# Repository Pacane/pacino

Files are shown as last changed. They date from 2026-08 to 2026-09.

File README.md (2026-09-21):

# Pacino

A hand-wired wireless split keyboard you print, screw together and solder — no main PCB.
Parametric OpenSCAD case + switch plate, with a build pipeline that produces **real STEP solids**
(via FreeCAD) so everything is editable in Fusion 360 as B-rep geometry, not as a mesh.
If you would rather not hand-wire it, the same design has a **slim build**: an 11.5 mm case around a
reversible PCB that is generated from this model and ready to order — [see below](#the-slim-build-a-real-pcb-115-mm).

Named after (and descended from) the [cheapino](https://github.com/tompi/cheapino), whose column
stagger and thumb-cluster geometry it borrows; hardware-wise it runs a nice!nano-compatible
nRF52840, Kailh hot-swap sockets on Amoeba-King single-key PCBs, and ZMK.

file-23d378c498248af3c7d3fe0cd5108f69

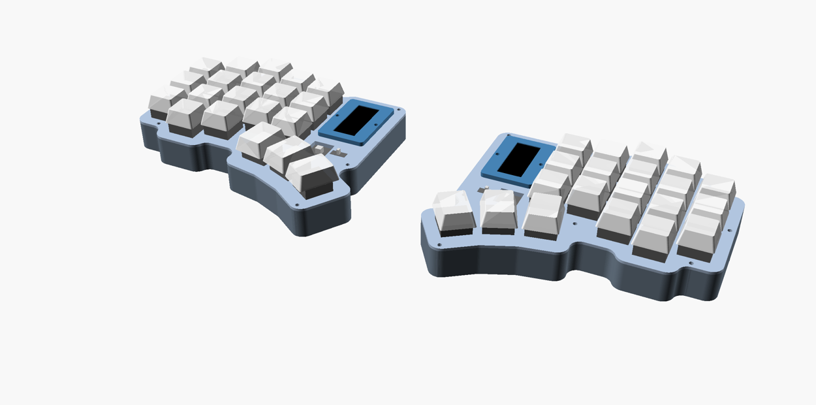
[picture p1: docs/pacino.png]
Pacino — 5 columns + 2 extra keys, nice!view version


*20 keys per half (40 total): 5 columns + 2 extra keys, with the nice!view display. 145 × 120 mm.*

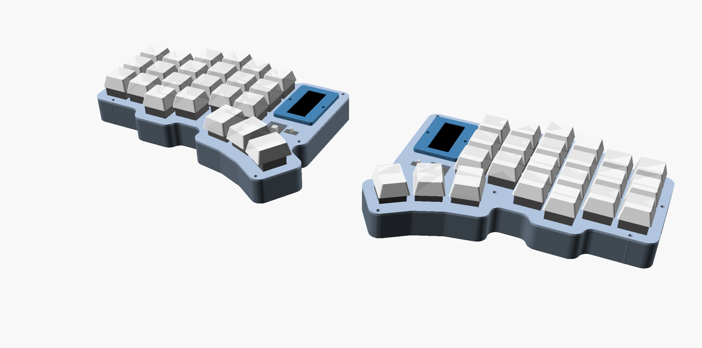
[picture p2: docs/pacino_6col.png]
Pacino — 6 columns + 2 extra keys, nice!view version


*23 keys per half (46 total): the optional 6th outer column, same display. 164 × 120 mm.*

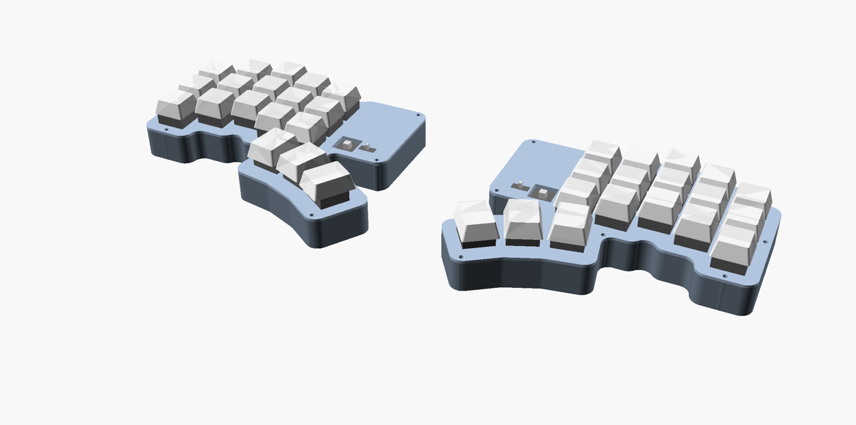
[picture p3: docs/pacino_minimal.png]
Pacino — 5 columns, no extras, no display


*The minimal build — 18 keys per half (36 total), no extra keys, no display. 145 × 120 mm.*

All three are the same scale. The display costs no width: stacked over the nano, a build with it is
exactly as wide as one without. Renders of every other combination are
[at the bottom](#variant-gallery).

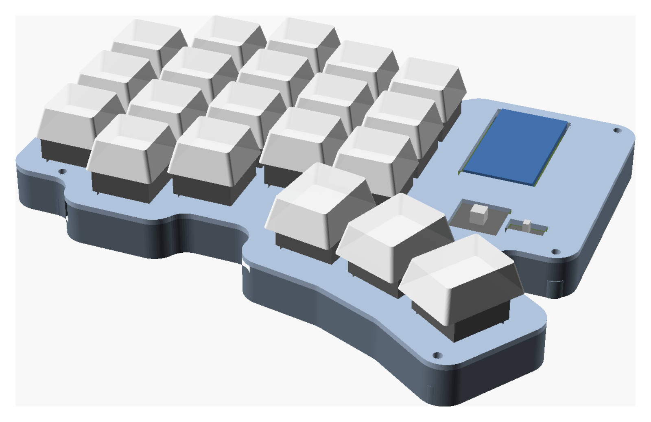
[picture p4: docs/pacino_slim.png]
Pacino — the slim PCB build


*The slim build: the same 40 keys over a reversible PCB, **11.5 mm** to the plate top instead of 17.5,
and flat — the cell lies in a well under the board. The controller sits flush in the plate window.*

**The default design:** a cheapino-style 3×5 (+2) + 3-thumb column-stagger layout on a clean
19.05 mm **MX** grid with **1.25u thumbs**, an **electronics bay** beside the inner column that
holds a **LiPo** (sunk into a well in the case floor — a 902030 by default), a **nice!nano**
(**flipped component-side down** in a cradle that is part of the plate, fully enclosed, USB out
through a notch in the wall) and a **reset button and power slide switch** in pockets in the
plate, laid out for **hand-wiring**. A **nice!view** mount (flush in the plate *directly over* the
nano, clamped by a screw-down bezel, so it costs no extra width) is in the model but off by default:
mounting bosses live in the walls, not in the matrix, and there is ~3 mm under the switch pins.
A PCB-sandwich build is a switch away.

```
keyboard.scad            the model — all parameters at the top, Customizer-friendly (parts: case, plate, section; bezel with nice_view)
layouts/cheapino.scad    generated from ../cheapino/pcb/cheapino.kicad_pcb  (exact positions, if you want them)
layouts/badtemper.scad   generated from ../badtemper2/BadTemper.kicad_pcb
tools/kicad_layout.py    KiCad .kicad_pcb -> layouts/*.scad  (switches, holes, MCU, Edge.Cuts polygon)
tools/pcb_gen.py         the slim build's PCBs: model -> pcb/*/ boards + footprint libs + gerbers
pcb/flat/  pcb/pod/     those two KiCad projects (generated, DRC-clean; each has its own README,
                         gerber zip and renders).  part = "pcb_test" prints a stand-in to fit first
tools/csg2step.py        OpenSCAD .csg -> STEP, runs inside FreeCAD
tools/svg_polygon.py     helper: bakes the cavity outline to a polygon for the FreeCAD pass
build.sh                 builds everything into out/
out/                     STEP / 3MF / STL / DXF / PNG — regenerate any time, never hand-edit
CHANGELOG.md             what changed since you printed — and whether you need to reprint, re-order or reflash
```

## Pick a ready-made variant

[`variants/`](variants/) holds every combination of the four options — 5 or 6 columns, with or
without the two extra keys, 902030 or 103450 battery, with or without nice!view — each as
`case_*` / `plate_*` STEP + 3MF for both halves (plus a bezel for display versions) and previews.
The index in [`variants/README.md`](variants/README.md) lists sizes; `./build_variants.sh`
regenerates them all.

## Quick start

```sh
./build.sh            # everything: step, mesh, dxf, png  (~40 s)
./build.sh step       # just the STEP files
SCAD_ARGS='-D battery=[34,50,10.5]' ./build.sh    # any parameter override, e.g. the 2000 mAh cell
```

Or open `keyboard.scad` in OpenSCAD and use the Customizer (`Window ▸ Customizer`).
`part` selects what is shown/exported (`assembly`, `section`, `case`, `plate`, the 2D profiles),
`side` picks `left` / `right` / `both`, `explode` lifts the plate.

Outputs per side: `case_*` and `plate_*` as `.step` (Fusion) and `.3mf` / `.stl` (slicer),
`*_2d_*.dxf` profiles for sketches, and `preview_*.png` (assembly, exploded, top, case, plate,
both halves, section through the bay). `WITH_DISPLAY=1 ./build.sh` additionally builds the
nice!view version (`case_display_*`, `plate_display_*`, `bezel_*`); in the Customizer that is the
`nice_view` switch.

## The layout

`grid_stagger = [0, 10, 16.4, 10, 7.5]` is the cheapino's column stagger (its PCB is already
19.0 mm MX pitch) snapped to 19.05. The thumb cluster starts where the cheapino's does
(`71.5, -15.5`) but uses **1.25u caps standing portrait** — long side pointing up at the columns —
fanned −10° / −22° / −34° around the thumb (key rotation = 90° + fan) at a 21.8 mm pitch along
the arc: `[[71.5,-15.5,80,1.25], [92.5,-21.5,68,1.25], [111.7,-31.7,56,1.25]]`. That gives
~1.5 mm between caps at their lower ends (they diverge towards the top, as a radial fan does) and
1.7 mm to the bottom row. Edit `grid_thumbs` to shift or re-fan the cluster; keep the rotation
as 90 + fan so the caps stay portrait.

**Extra keys.** `grid_extra_keys = [[1, -1], [2, -1]]` adds a short fourth row under the ring and
middle columns (under X/C on the left half, ,/. on the right) — 38 keys per pair. `[]` removes them;
any `[column, row]` pair on the grid works.

**Sixth column.** `grid_outer_col = true` adds a column outside the pinky (Corne-style 3×6), with
its own `grid_outer_stagger` (0 = same as the pinky). The left-edge bosses and bumpons follow it; the
half grows to 164 mm wide. Build it alongside the default with
`SUFFIX=_6col SCAD_ARGS='-D grid_outer_col=true' ./build.sh`.

**Hand-wiring.** Eight 6 mm bosses sit 0.5 mm inside the inner wall line so they merge into the
wall and the whole matrix area is free for diodes and wires (each boss was checked for ≥ 2 mm to
every switch body, ≥ 1 mm to the battery, and clear of the MCU cradle and the keycap footprints
so the screw heads are reachable). Under the plate there are 10 mm: MX body + pins take 8.3 from
the plate top, leaving ~3 mm under the pins. The bay has ~8 mm of floor to the right of the battery and 4 mm below it for routing,
and its open fence end faces the nice!nano.

Set `layout = "cheapino"` or `"badtemper"` to use the exact positions extracted from those
boards instead (`cavity_from = "pcb"` then follows that board's Edge.Cuts).

## The electronics bay

```
bay_left / bay_top_y = 86.5 / 61   the bay hangs from its top edge (USB at the top); size is automatic
battery_type = "902030"            the cell (902030 / 103450 / 604060 / custom), bottom-left of the bay, in a 3 mm fence
mcu_size   = [18, 33]              nice!nano at the top of the bay over the battery (measured on a SuperMini clone)
nv_pcb     = [14, 36, 1.6]         nice!view, right of the nano, header end down
ctrl_bay_h = 13                    reset + power strip hung below the bay, switches at its right end
```

Stack at the bay with the 902030 (z from the case underside): floor 0–2.5, with the battery well
sunk to 1.2 · battery 1.2–10.7 · 2.8 clearance for the nano's components, which now face down ·
nice!nano PCB 13.5–15.05 · 0.95 air · plate 16–17.5. The 1.3 mm the well recovers pays for the
component clearance the flip costs, so overall height is unchanged. The model warns if the board's
components would hit the battery or the board would hit the plate. `part = "section"` renders the stack as a 2D cut.

`battery_type` picks the cell and sizes the bay and the cavity depth (`cavity_depth = 0` = automatic,
battery thickness + 4): `902030` (20 × 30 × 9, 500 mAh — weeks per charge; 13.5 mm cavity),
`103450` (34 × 50 × 10, 2000 mAh; 45 × 60 bay, 14.5 mm cavity, +1 mm case height and +3 mm width — the bay reaches past the thumb cluster), `604060` (40 × 60 × 6; 10.5 mm cavity),
or `custom` with `battery_custom`. Build the 2000 mAh version alongside the default with
`SUFFIX=_2000mah SCAD_ARGS='-D battery_type="103450"' ./build.sh` → `case_2000mah_*`, `plate_2000mah_*`.
The controller charges at 100 mA by default, which is ~20 h for the 2000 mAh cell: before you fit it, bridge the
**boost** solder jumper on the back of the board (two pads by the battery pads; 500 mA on a nice!nano v2, 300 mA
on the SuperMini clones — only with a cell over 500 mAh, so not for the 902030 or 303040).

### How the nano and the battery are held

**Battery:** it drops into a **well sunk 1.3 mm into the case floor** (`battery_well_floor`), whose
walls locate it on all four sides; with the plate on, the nano 2.8 mm above it keeps it in the well. Set `battery_well_floor = 0`
instead and it sits on the floor inside a 3 mm printed fence (`battery_fence`, open at the lead end),
which costs 1.3 mm of case height — the well is the default because the flipped nano needs the room.

**nice!nano / nRF52840 clone:** it goes in **upside down** (`mcu_flipped`, the default) — components
and USB connector facing *into* the case, bare PCB back facing the plate. That protects everything on
the board, and because the wires now poke straight down through the pads into the bay, the cradle no
longer needs wire channels along the sides: the plate above it is **solid**, with no opening over the
MCU at all.

It sits in a cradle that is part of the plate: rails on both long sides, open at the USB end,
holding the board four ways —

- **sideways:** five half-round **crush ribs** per rail (`crush_rib`, 0.6 mm proud, centred on the
  pocket wall so nothing bulges outward), narrowing the 18.6 mm slot to **17.4 mm** at the ribs. An
  18.0 mm board goes in with real resistance and shaves them to a custom fit; boards up to ~18.6 mm
  crush them further. Turn `crush_rib` down for a lighter fit, up for a tighter one.
- **from below, far end:** two corner tabs under the outer 0.5 mm of the far edge, with a 10 mm gap
  between them so a SuperMini-style clone's centred reset button stays clear.
- **from below, USB end:** two posts rising from the **case floor** (`mcu_end_post`), which engage
  once the plate is screwed down.
- **from above:** a 6 mm-wide roof pad on the plate over the bare back of the board, leaving it
  0.2 mm of lift.

**To fit it: with the plate off the case, slide the board into the cradle from the open USB end
until it meets the far rail.** To remove it, push it back out through the **4 mm eject hole** in the
far rail. **Set `mcu_size` to your board's real width × length.** Before printing, check your board's
component side is clear where the cradle touches it: the far corners (outer 0.5 mm, either side of
the reset button) and the two USB-end corners.

**Wiring the nano:** solder the wires on what is now the underside — they drop straight into the bay,
no channels or routing needed. The battery leads come up out of the well right below the board.

Setting `mcu_flipped = false` restores the old component-side-up cradle: an opening through the
plate, wire channels along both long edges, and a USB slot that crosses the plate line.

### Reset button and power switch

Plain through-hole parts, both dropped into the plate from above: a **12 × 12 mm tactile switch**
with a tall plunger (reset → nano `RST` + `GND`) and an **SS12D00 slide switch** (power, in series
with the battery `+` to the nano's `B+`). Each pocket is a hole through the plate the size of the
body (+0.2 mm) with a 1.2 mm floor hanging below, with a 3.5 mm square opening around each leg
(`ctrl_leg_hole`) so the legs hang in free air below the floor and a wire can be wrapped and
soldered to them from underneath. The
tactile's body sits 2.3 mm below the plate top so ~1 mm of its 3.3 mm plunger is proud — enough to
press, hard to hit by accident; the slide's 3 mm actuator stands up for your thumbnail. Solder
wires to the legs from below. Nothing can push the parts in (they sit on the floor) and the legs
plus wires keep them from lifting; if you want belt-and-braces, a dab of glue or a 0.1 mm tighter
`ctrl_clearance` does it. `reset_body` / `power_body` / `*_legs` take the dimensions of whatever
switches you actually buy.

They sit in a **control bay** strip hung below the electronics bay (`ctrl_bay_h = 0` sizes it for
the larger switch), placed as high as the battery allows — the pockets reach up into the bay's
battery-free margin — so they stay clear of the thumb keys in both battery layouts, off the battery
(legs and wires hang free below), and add nothing to the bay's width. (The strip spans the full bay width on purpose: a narrower one leaves a pocket
between bay, column 4 and thumb key 2 that the outline smoothing turns into a hole.)

### nice!view

The nice!view has no mounting holes — on a PCB it hangs off its 5-pin header — so here it is
**clamped**. It sits vertically (header end down, the way a Corne shows it) in a pocket through the
plate, resting on two 1 mm ledges under its long edges that hang from a ring below the plate. The PCB
top ends up `nv_preload` (0.15 mm) above the plate top; the printed **bezel** (`part = "bezel"`,
2.5 mm, window sized to the glass) is screwed down onto two 5 mm bosses hanging under the plate with
M2 screws — `nv_boss_hole_d = 1.7` for self-tapping into PETG (works well; 3 mm of engagement), or
3.2 for heat-set inserts — so it clamps the PCB, not the plate. The 12.6 mm opening under the
display leaves the solder pads free. Nothing can come loose without removing two screws, and
nothing relies on a friction or snap fit.

**It sits directly on top of the nano** (`nv_stacked`, the default). That only works because the
board is flipped: the plate above it is solid, so the display can take that surface. The bay then
stays as narrow as the no-display version — the display costs **0 mm of width** instead of 11.6.

Three things follow from stacking, and the model enforces all of them:

- The bezel's screw bosses move from the display's **ends to its sides** — an end boss hangs 3 mm
  below the plate and would pass straight through the board. On the sides they clear the board by
  0.8 mm and the cradle pocket by 0.5 mm, landing in free bay space 2.3 mm above the battery.
- The support ledges are thinned (`nv_ledge_te`, 1.2 → 0.6 mm) so they clear the board's back by
  0.4 mm — and they then double as the board's hold-down, replacing the cradle roof pad that the
  display's opening cuts through.
- The display's wiring end overhangs past the board, so its five wires drop straight into the bay
  and run to the nano's pads, which now face into the bay.

The cost is servicing: getting the nano out means removing the bezel and lifting the display first.
Set `nv_stacked = false` for the old side-by-side bay (11.6 mm wider); it is also the automatic
behaviour if `mcu_flipped` is off, since an unflipped nano needs that plate area for its own opening.

### Bumpons

Eight 10.6 mm × 1 mm recesses in the underside for 10 mm self-adhesive rubber feet (`bumpon_d`,
`bumpon_clearance`, `bumpon_depth`; `bumpon_positions` for the four under the key block and thumb
cluster, two on the left edge follow the outer column, and two are placed on the bay: 8 mm in from
its top-right corner, and 12 mm up from the bottom of the control strip on the right). The floor is
2.5 mm so 1.5 mm remains under each recess.

The two bay feet and the **battery well** compete for the same floor: the well is already 1.3 mm
into it, so a recess over the well would leave 0.2 mm. With a well the cell therefore sits against
the bay's *left* wall (which doubles as the well's side) instead of 5 mm from it, keeping the bay's
right-hand corners clear, and the bay is sized so the top-right foot always fits beside the cell with
a millimetre of wall outside its recess. Each bay foot then moves outward only by what its well
forces — a couple of millimetres — and the model warns if one has nowhere to go. The wider cells pay
for it in width: the 103450's bay is 45 mm instead of 44, and its case 148 mm. A 56 mm MagSafe magnet ring (the
self-adhesive kind) goes under the index column (`magsafe_d`, `magsafe_pos`; 0 = none). It is **printed in**
(`magsafe_style = "embedded"`, the default): an annular pocket exactly as tall as the ring (`magsafe_ring_id`,
`magsafe_ring_t`; measure your ring — a 56 mm sticker ring is about 45 mm inside and 0.5–0.7 mm thick), open to the
underside through a window one layer up, so the first layer is a ledge overlapping the ring's edges by 0.8 mm
(`magsafe_lip_w`) and the steel shows through between them, 0.2 mm below the surface. Add a pause in the slicer
**before layer 5** (the model prints the height: after the layer ending at z = 0.8 mm), drop the ring in with its
exposed face **down** and the adhesive up, press it flat, and resume. Layer 5 is then laid straight onto the ring,
like a first layer on a sticky bed, with the nozzle a full layer above the steel. If supports are on, put a
support blocker over the ring: the pocket reaches the plate through the window and would otherwise be filled.
It uses 0.8 mm of the 2.5 mm floor, so it works in the slim build too, and the ring cannot come off. Being
steel, the ring has no polarity to get wrong.

Why the window: the hold improves with every tenth of a millimetre less between the ring and the mount. A
0.4 mm skin over the ring (`magsafe_skin = 0.4`) is the clean look and holds decently; a one-layer skin held
better but tears along its lines with the ring's edge behind it; the ledge is backed by the pocket wall and holds.
Don't leave air over the ring either (`magsafe_pocket_air` only pads a ring thinner than a layer multiple; keep
ledge or skin + ring + air on a layer boundary, the model notes if it isn't): the ceiling would have to bridge it,
and since a layer's lines all run one way, the ones running along the ring span 30 mm chords and sag. The bigger
lever is the ring itself: the usual sticker ring is 0.65 mm of steel, and a *magnet* ring (1.2–2 mm, 16 segments)
holds a mount in a different league — the pocket takes it the same way, but it has a right way up: hold it
against the mount first and put the face it pulls in with down.

The two stick-on alternatives: `"groove"` leaves the underside flat with a one-layer locating groove 0.3 mm
outside the ring's edge, and the ring's adhesive sticks straight to the bed-side first layer (it holds there, as on
any PETG print). `"recess"` sinks the ring 1 mm into the floor (`magsafe_depth`), but that pocket prints on
support and the adhesive does *not* hold on a support-interface surface — sand the pocket and glue the ring in.
The recess has to stay clear of the battery well, since the two cut the floor from opposite sides and would leave
0.2 mm where they overlap (the model warns). `out/preview_bottom.png` shows them all.

### How the plate attaches

The plate is the lid. The case walls end flush with the plate's underside, so the plate rests on
them all round; a 1 mm lip under the plate drops inside the walls (0.2 mm clearance) and locates it.
Eight 6 mm bosses rise from the floor to the plate underside (six around the key block, two on
the bay's right-hand corners, all half-buried in the wall so they don't intrude on the wiring), each with a
3.3 mm × 5 mm hole, with a 4.2 mm × 0.6 mm counterbore at its mouth (`boss_relief_d` / `boss_relief_h`), for an **M2 × 4 × 3.5 brass heat-set insert** — press it down until it bottoms in the counterbore, so it and the plastic it displaces sit below the boss face and the plate seats without trimming (`boss_hole_d = 1.7` if you'd
rather self-tap). **M2 × 6 screws** go down through the plate into them — the heads sit on top of
the plate, like a tray-mount case (ultra-thin hex-socket heads are ideal).

Hardware per half: 8 × M2×4×3.5 inserts, 8 × M2×6 screws, 8 × 10 mm bumpons
(+ 2 × M2×4 self-tapping screws for the bezel if you build the display version).
`variants/insert_test.3mf` (`part = "insert_test"`) is a two-minute test print — one boss as on the
case and a scrap of plate with its screw hole — to try the insert and screw before printing a case.

**M3 instead:** `screw_size = "M3"` resizes everything at once — 4.0 mm insert holes for the common
4.2 mm OD M3 inserts with a 5 mm counterbore, 3.4 mm clearance holes in the plate, and in the slim build a
6 mm spacer boss, a 4.6 mm wall channel, a 3.6 mm wall and 3.4 mm board holes. Hardware is then
8 × M3 inserts (4 mm long here, 3 mm in the slim build) and 8 × M3×6 (M3×10 slim) screws; an M3 socket
head is 5.5 mm across, so use low-profile ones. The 6 mm bosses keep 1 mm of wall around the insert —
fine for the five buried in the wall, set the three free-standing ones carefully. The bezel stays M2.

### Hot-swap with single-key PCBs

Per-key hot-swap PCBs (amoeba style) work as-is: the Kailh socket and the diode go on the underside
of each little board, the bare top face sits against the switch body, and the board hangs on the
switch — the socket grips the pins (as in any hot-swap board) and 5-pin switches' pegs locate it.
Row/column wires join the boards' `ROW`/`COL` pads underneath, below the ribs.

The classic failure with hanging boards — a switch being inserted pushes the board down instead of
into the socket — is handled by **pillars rising from the case floor** under each board's four
corners (`key_pcb_post = [2.5, 3.2]`, `key_pcb_post_gap = 0.2`). They sit inside the corner notches,
on the bare 1.3 × 2 mm patches the amoeba-king keeps clear of pads and components (its side pad rows
end 5.6 mm off-centre; the pillars start at 6.3), and stop 0.2 mm below the boards, so with the case
closed a board cannot move and a new switch's pins are forced into the socket. To swap a switch,
just pull and push with the case closed; the board stays put.

**Wiring around the pillars.** The pillars hug the *top and bottom* edges of each board (the row
boundaries), 3.5 mm long at ±7 mm from centre, so the column boundaries are completely free and the
centre 10 mm of every row boundary is free too. The amoeba-king's ROW pads are on its left/right
edges and its COL pads at the centre of its top/bottom edges: row wires go straight across the
column boundary pad-to-pad, column wires run down the board centre line between the pillar pairs —
neither comes near a pillar. The only rule: never lay a wire along a board's top/bottom edge into a
corner, because a wire on a pillar patch gets clamped in the 0.2 mm gap when the case closes.
[`docs/wiring_guide.png`](docs/wiring_guide.png) shows the underside: the inner wall and its bosses,
the boards with their pads, the pillars, the matrix, and the nice!nano with every pin named. The
matrix pins are read straight from the shield (`row-gpios` in `pacino.dtsi`, `col-gpios` in
`pacino_left.overlay`), and each row and column chain gets its own thin wire to its pin, routed
clear of pillars, bosses and wall (`tools/wiring_guide.py` regenerates it and checks every wire;
each variant directory gets its own). Orient the boards with the ROW pads towards the neighbouring
columns (the pillars are sized around that). The row wires leave the inner column straight into the
bay; the column wires collect at the thumbs' COL pads (the bottom key's, for a column without a
thumb), enter the bay beside the inner column's bottom corner and climb the far side of the nano.

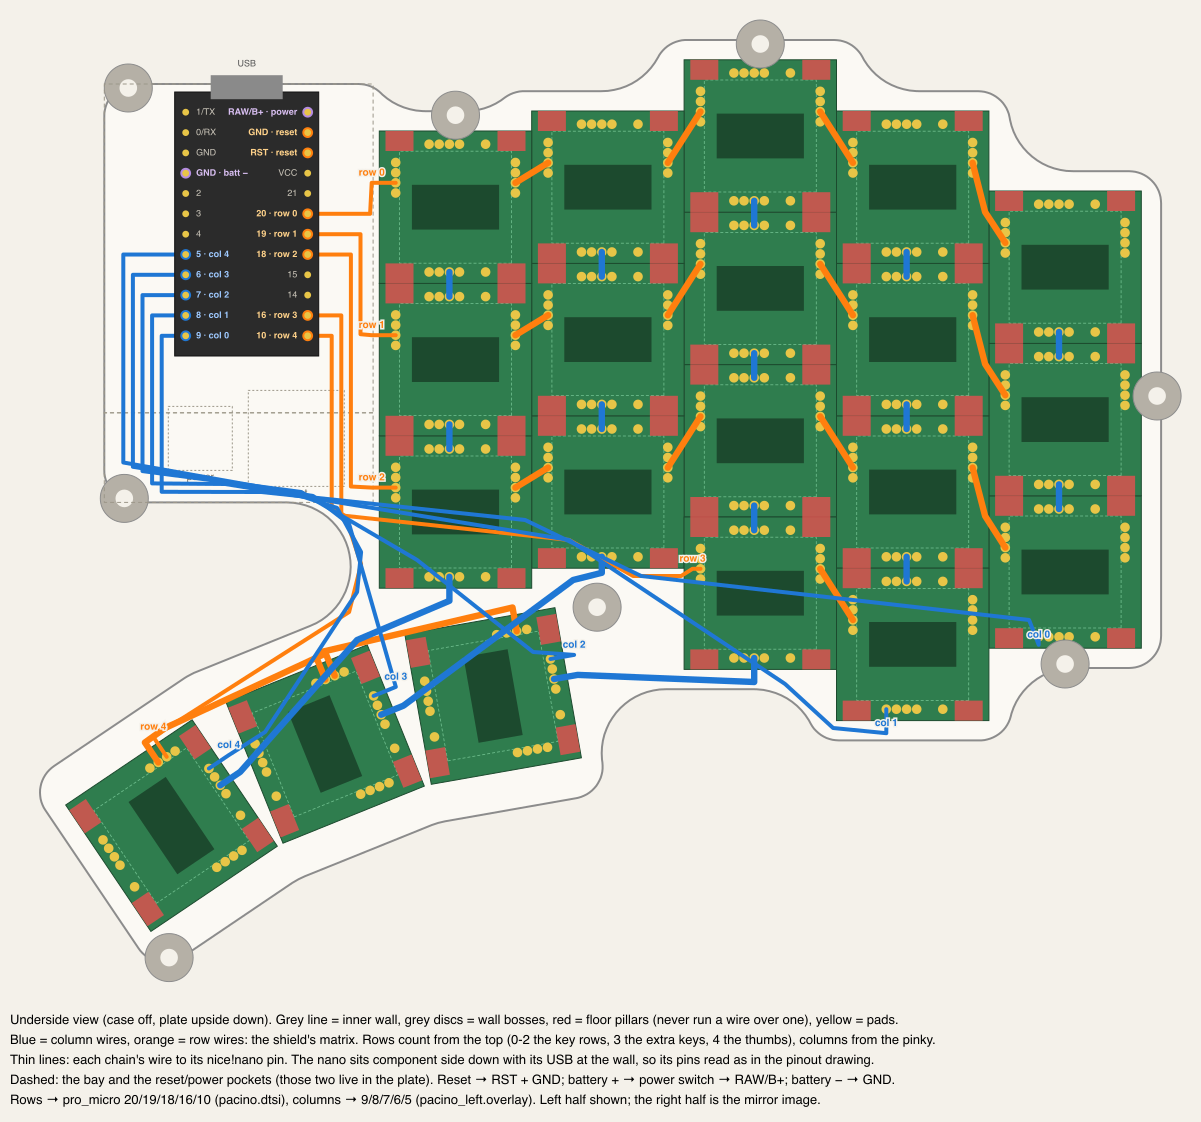
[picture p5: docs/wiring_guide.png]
wiring guide

`key_pcbs = true` (default) also stops the ribs 0.3 mm above the boards' top face, since the boards
are wider than the rib cells; set it to false for plain hand-wiring (no boards, no pillars). All of
this is a hand-wired idea — `build = "pcb"` ignores it, and takes its rib depth from the main board.

### Plate stiffness

A flat 1.5 mm PETG plate flexes under typing, and infill/walls can't fix that (it is already
practically solid). The plate therefore carries an **egg-crate of ribs** on its underside:
a 1.5 mm wall around every switch, 3.2–3.5 mm tall (down to the switch-body bottom, or 0.3 mm above
per-key PCBs, or the main board on the slim build), 0.3 mm outside the switch's clip zone, merging
into a grid (`plate_ribs`, `rib_w`, `rib_h`). That is roughly 5× the bending stiffness of the flat plate
at no change in case height — the ribs sit beside the switch bodies, above the pins, so wiring and
diodes (which live below the pins) are unaffected. The ribs are kept clear of the bosses and the
lip. Print the plate in 100 % infill anyway; a PLA plate with a PETG case is also a fine
combination (PLA is ~70 % stiffer than PETG).

### Printing (PETG)

- **Case:** prints as-is, bosses up, with a **pause before layer 5** to drop the MagSafe ring into its pocket
  (see [Bumpons](#bumpons)). If you print with supports on (say, for the bumpon recesses), use `case_*.bambu.3mf`
  instead: the same case as a Bambu Studio / Orca project with a support blocker already over the ring pocket
  (`tools/bambu_3mf.py` makes it from the plain 3MF) — otherwise the slicer fills the pocket through its window.
  Nothing overhangs except the open-top USB slot (bridged by the
  plate, so it can stay open) and the 1 mm bumpon recesses on the first layer.
- **Plate:** print top-side down. The cradle, the switch pockets (and the display ring and bezel
  bosses, if enabled) then point up and need no support; the keycap side gets the smooth first
  layer. The cradle's crush ribs run the full rail height, so they print as part of the rail
  perimeter. The only overhangs are the cradle's far corner tabs, the roof pad over the board and
  the pocket floors (tiny, fine in PETG).
- **Bezel** (if used): window side down.
- PETG tolerances: pockets have 0.2–0.3 mm clearance, the plate lip 0.2 mm; if your printer runs
  tight, bump `mcu_clearance` / `ctrl_clearance` to 0.4 and `lip_clearance` to 0.3. The MCU cradle
  is deliberately an interference fit — tune `crush_rib` (0.6) rather than the clearances. Self-tapping M2
  into 1.7 mm holes is a good fit for PETG; heat-set inserts also work in the 5 mm bosses.

### What sets the size

Per half (case outline), against the Bad Temper:

| | width × height |
|---|---|
| Bad Temper (choc, printed case) | 122 × 94 |
| badtemper2 MX PCB + 2 mm case | 131 × 107 |
| this (default, no display) | **145.0 × 120.2** (17.5 mm to the plate top) |
| this, with nice!view | 145.0 × 120.2 (the display stacks over the nano) |
| this, slim PCB build | 145.0 × 120.2 (**11.5 mm** to the plate top, flat; or the same with a pod for a 902030) |

Without the display the bay (nano + 902030) is narrower than the thumb cluster, so the **thumb
cluster** sets the right edge (130.5) and the bottom (−51): the cheapino position plus the portrait
1.25u fan is +12 mm lower and ~+12 mm further out than the Bad Temper's 1u thumbs. The display no
longer changes that: stacked over the nano it needs no extra bay width, so both versions are the
same size. (Side by side — `nv_stacked = false` — the nano + nice!view row is 41.2 mm and pushes
the right edge to 142.1: **+11.6 mm**.) Margins (`key_margin` 3,
`wall` 2.4) account for ~2.5 mm per side. A Bad Temper-sized half therefore needs a tighter thumb
cluster, not a different battery.

## Getting it into Fusion 360

1. **STEP (recommended).** `File ▸ Open` / `Insert ▸ Insert Derive` on `out/case_left.step`.
   One solid, true planar faces, real cylindrical holes. Edit with `Press Pull`, fillets,
   `Move Face`, or sketch on a face and cut/extrude; everything after import is in the timeline.
   Volumes are cross-checked against OpenSCAD's mesh on every build (printed by `build.sh`;
   they agree to <0.01 %).
   Note the case outline is a polygon (8 segments per 90° of rounding) because OCC's 2D
   offsetting cannot reproduce OpenSCAD's outline smoothing — see `build.sh`. Holes and bosses
   are exact cylinders.
2. **DXF profiles → fully parametric rebuild.** `Insert ▸ Insert DXF` on the XY plane:
   `cavity_2d`, `case_outline_2d`, `plate_2d`. Extrude the outline to the wall height, cut the
   cavity from `floor_t` up, add bosses at the hole centres. Slower, but you own every dimension.
3. **Mesh fallback.** `Insert ▸ Insert Mesh` with the `.3mf`, then `Mesh ▸ Convert Mesh`
   (Prismatic).

## Build modes and hardware

- `build = "plate"` (default, hand-wired): switches clip into the 1.5 mm plate, 6 mm bosses run
  from the floor to the plate underside with 3.3 mm holes for M2×4×3.5 heat-set inserts
  (`boss_hole_d = 1.7` for self-tappers); M2×6 screws through the plate (`screw_size = "M3"` for
  M3 inserts and screws throughout). `cavity_depth = 10`
  leaves room for MX bodies + pins + wiring and the battery/cradle stack.
- `build = "pcb"`: PCB sandwich, and the slimmest build at **11.5 mm**. Bosses stop at the PCB
  underside, the plate gets spacer bosses down to the PCB, MX plate-to-PCB spacing is automatic
  (5.0 mm MX / 2.2 mm Choc), the MCU sits on sockets on the PCB, the plate gets a window instead of
  the cradle, and the cell either lies flat under the board or rides in a pod on the plate over the
  controller. The boards are in [`pcb/`](pcb/) — see
  [The slim build](#the-slim-build-a-real-pcb-115-mm).
- `switch_type = "choc"` swaps pitch (18 × 17), cutout (13.8), plate thickness (1.3) and heights.
- Wall cutouts: `usb_cutout = [w, h, z-offset-from-board-top]`; `extra_cutouts` for a power
  switch etc. `[x, y, outward_angle, w, h, z]`.

## Using a different PCB or layout

```sh
python3 tools/kicad_layout.py path/to/board.kicad_pcb --prefix mykbd > layouts/mykbd.scad
```

It picks up `SW*`/`K*`/`MX*` switch footprints (position, rotation), mounting holes with
1.9–3.6 mm drills, `U1` as the MCU, and chains `Edge.Cuts` into one polygon. Add an `include`
and a `layout` option in `keyboard.scad` the way `cheapino`/`badtemper` are wired in.

## The slim build: a real PCB, 11.5 mm

`build = "pcb"` turns the same design into a **PCB sandwich**, and the boards exist: [`pcb/`](pcb/)
holds two complete, DRC-clean KiCad 9 projects with gerbers, generated from this model by
[`tools/pcb_gen.py`](tools/pcb_gen.py).

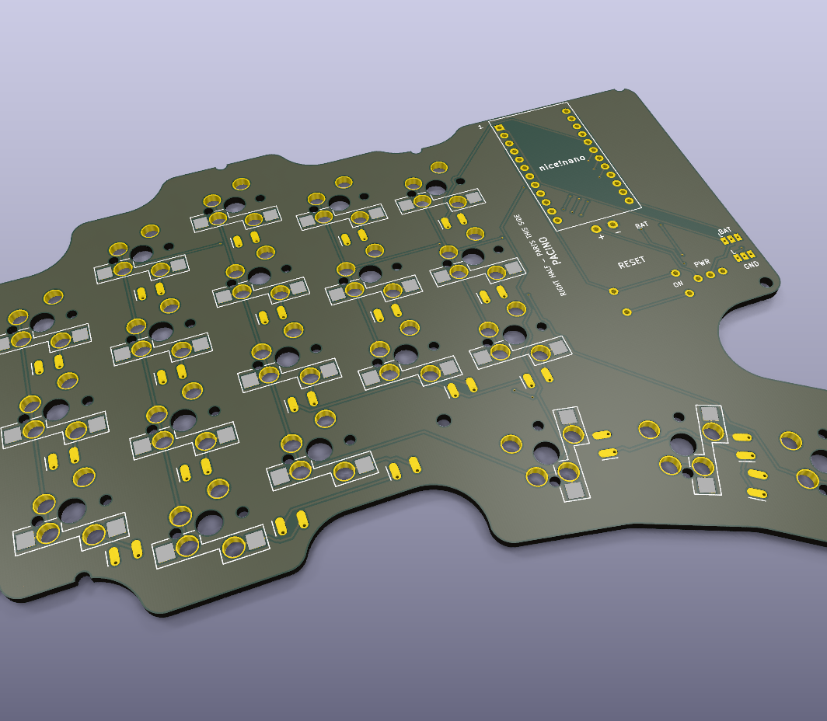
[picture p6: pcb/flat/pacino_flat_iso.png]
the Pacino PCB


<p>
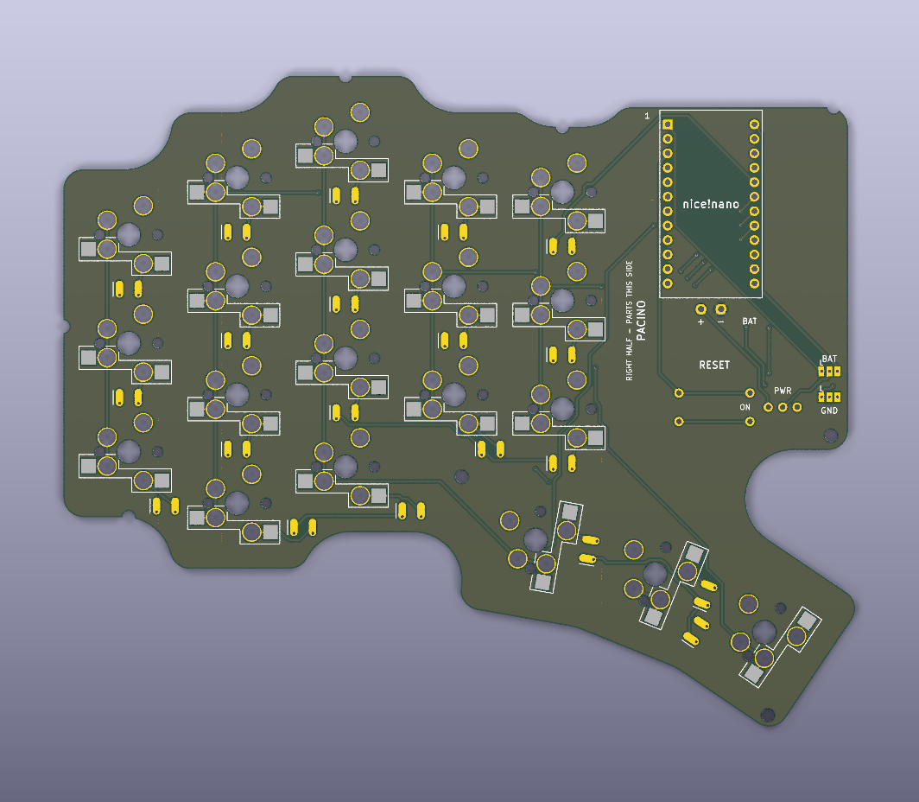
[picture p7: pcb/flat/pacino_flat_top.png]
front

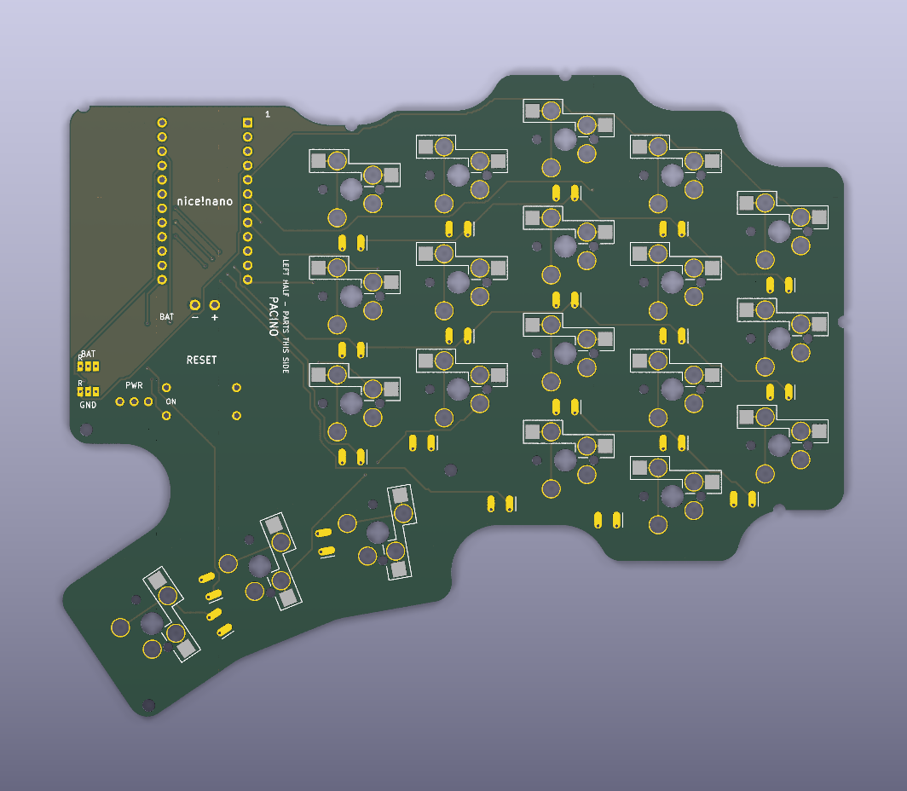
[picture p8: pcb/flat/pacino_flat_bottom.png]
back

</p>

*The same board from both sides. Flip it over and the bay swaps sides — that is the right half. Each
face's silkscreen names the half you build on it, and outlines its hot-swap sockets the way round
they go in on that half. These renders come out of `tools/pcb_gen.py` with the board, so they are
always the board in the repo rather than a picture of an older one.*

**11.5 mm to the plate top** — the floor for any MX build, and 6 mm thinner than hand-wired. The
stack is 2.5 floor + 2.4 (hot-swap sockets) + 1.6 board + 5.0 (MX plate-to-PCB, fixed by the
switch), and there is nothing left to remove.

Hardware for the slim build: the bosses stop at the board, so they are only 4.9 mm tall and their insert
holes 4 mm deep with 0.9 mm of floor under them, the same 0.6 mm counterbore at the mouth — use **M2 × 3 × 3.5 heat-set inserts** (the hand-wired case
takes 4 mm ones) and **M2 × 10 screws** (1.5 plate + 3.5 spacer + 1.6 board + 3 mm of thread). Five of the
eight bosses sit on the wall line like the hand-wired ones, and since the wall keeps rising 5 mm past their
tops, their insert holes would be tucked 1.2 mm under it — so a 4 mm channel (`pcb_screw_channel`) runs up
the inside of the wall over each hole, the insert and screw drop straight in, and the slim case's wall is
3 mm (`pcb_wall`) to keep 1.5 mm behind the channel (`screw_size = "M3"`: 4.6 mm channel, 3.6 mm wall, 3.4 mm
board holes, 6 mm spacer bosses — see [How the plate attaches](#how-the-plate-attaches)). The other three (thumb end, the bay's bottom corner, and
the one by the thumb keys) stand 2.5–3 mm clear of the wall as full round bosses; the board gets three real
mounting holes there and five edge notches at the wall-line ones. Two 3 mm floor pillars (`pcb_posts`)
stand under the board between the bosses, in the column gaps clear of the sockets, switch pins and diodes,
so a 55 mm span of board is not hanging on its corners; the model warns if one is moved onto a socket, and
the board generator keeps diodes off them.

Going to M3 with a board that was made for M2 (2.2 mm holes): the screws only have to pass *through* the board,
so drill its three real holes and file its five edge notches out to 3.4 mm rather than ordering a new one. Seven
of the eight have no copper within 3.15 mm of the hole centre (only the ground pour, which any drill over 2.7 mm
exposes on the hole wall — harmless, the screw lands in a brass insert in plastic). The top-edge hole between the
middle and ring columns, at (76.2, 57.1), is the exception: the column-0 bus runs 1.45 mm from its centre on the
back, so a 3.2 mm drill would cut it. Leave that one M2 with `m2_holes = [[76.2, 57.1]]` (its insert hole,
counterbore, plate hole and board notch stay M2-sized) or leave it unscrewed — the plate rests on the wall all
round. A board generated with `screw_size = "M3"` (`tools/pcb_gen.py -D 'screw_size="M3"'`) has 3.4 mm holes
from the start.

What sets it is where the cell goes, because **below the board every millimetre of battery is a
millimetre of case**. Above it, the 3.5 mm the MX geometry hands you is free — the socketed
controller already lives there, finishing flush with the plate top, and costs no height at all.
There are two ways to spend that, and both are built:

### Flat — a 303040 under the board (the default)

the slim build, flat

There is 3.4 mm of unused space under the board in the bay: 1.3 mm of floor well plus the 2.4 mm the
hot-swap sockets need — and the bay has no switches, so nothing is using it. A cell that fits inside
it needs no pod and no cutout in the board. A **303040** (3 × 30 × 40, ~320 mAh) lies in a well in the
floor, the plate stays flat, and the controller sits flush in its window.
Parts: [`variants/5col_extra2_bat303040_pcb_flat/`](variants/5col_extra2_bat303040_pcb_flat/),
board: [`pcb/flat/`](pcb/flat/).

3.4 mm is a cliff, not a slope. A thicker cell has to poke up through the board, and in the bay that
cutout runs straight under the controller and leaves its pin rows with no board to solder to — the
model warns if you ask for it.

### Pod — the 902030 over the controller

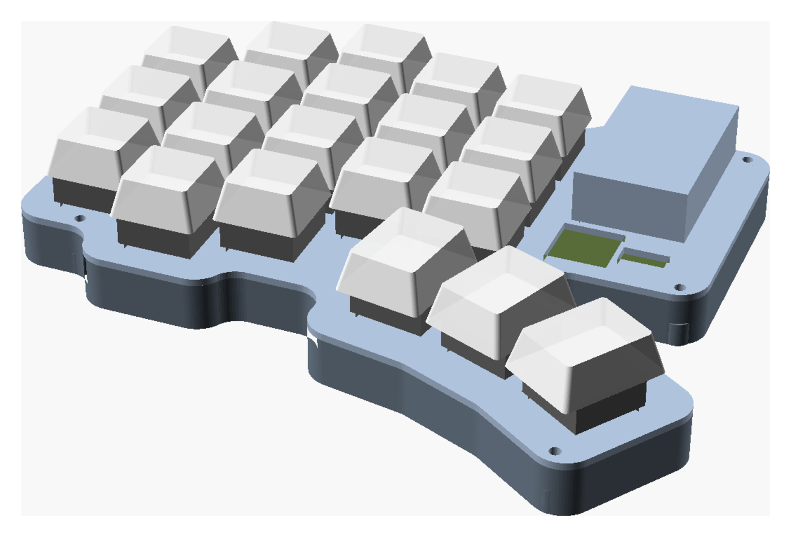
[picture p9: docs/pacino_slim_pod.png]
the slim build, pod


If you want the full 500 mAh, the 902030 rides in a **pod moulded into the plate, directly over the
controller** (`battery_pod = true`): in through the MCU window from below, resting on the controller,
leads down into the bay. Same 11.5 mm case, same outline — the pod stands 11.1 mm proud of the plate,
under the keycaps, which reach 14.5.
Parts: [`variants/5col_extra2_bat902030_pcb_pod/`](variants/5col_extra2_bat902030_pcb_pod/),
board: [`pcb/pod/`](pcb/pod/).

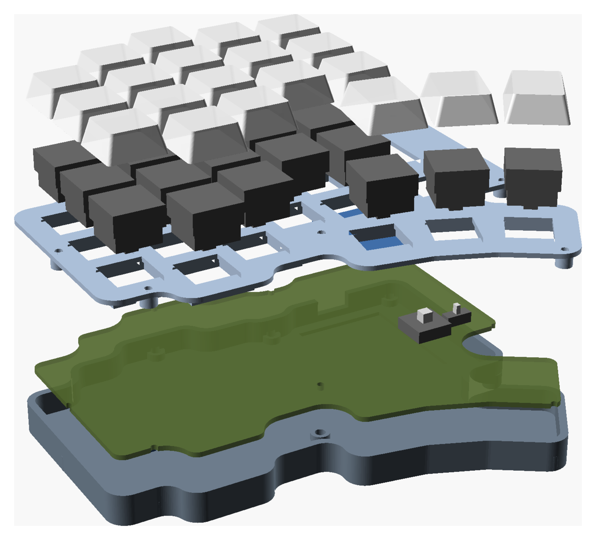
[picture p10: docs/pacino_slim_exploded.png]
the slim build, exploded


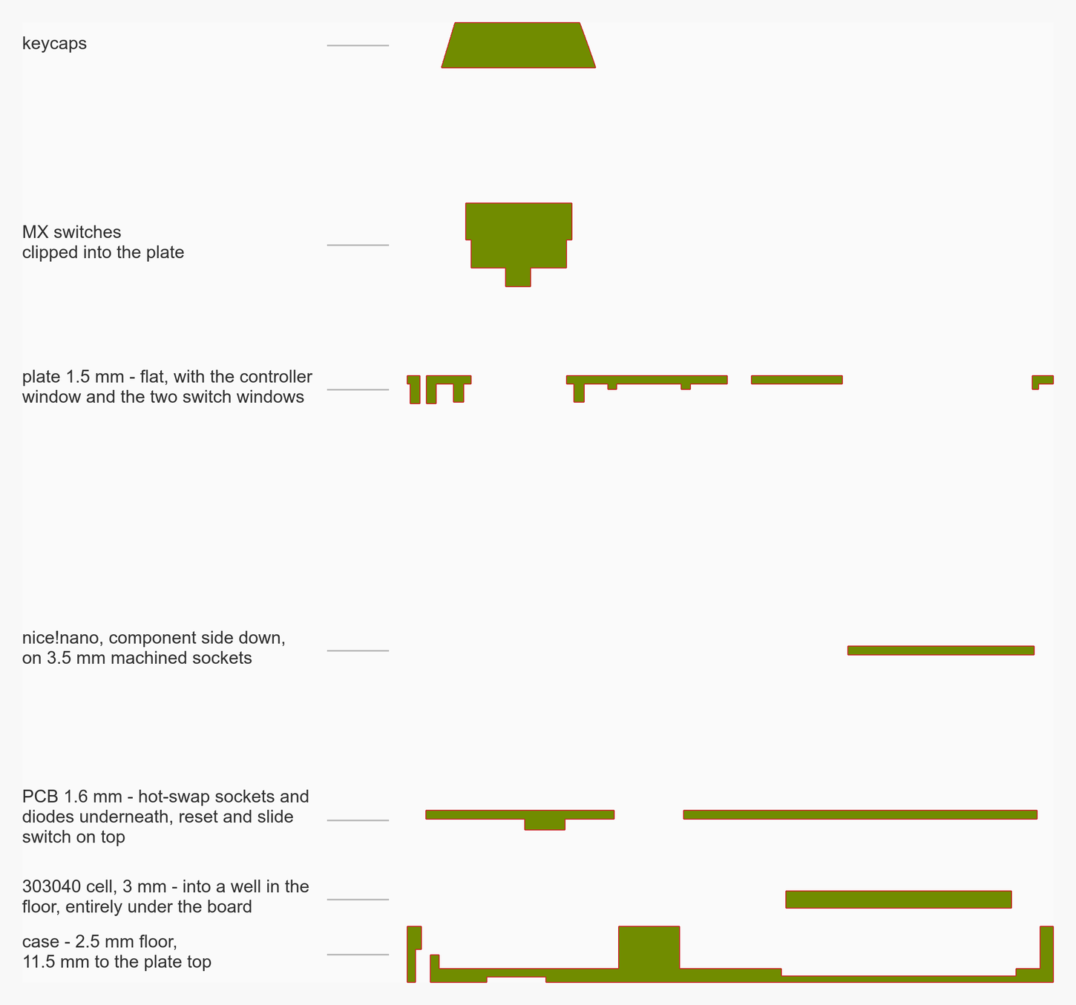
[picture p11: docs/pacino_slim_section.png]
the slim build in section, exploded and labelled


*Every part and where it sits, in the order you assemble it. `part = "section"` cuts the stack at
`section_x` (here 111, through a thumb key and the bay at once); `explode` separates the layers —
case, cell, board, controller, plate, switches, keycaps — each by its own step, so `explode = 0` is
exactly the assembled model.*

### Test-fitting it before you order a board

`part = "pcb_test"` prints a stand-in for the PCB: the real outline and mounting notches at 1.6 mm
thick, every hole a switch's pins, pegs and centre post pass through, the controller's two socket
rows, and the reset and slide switch legs — plus bumps on the underside at the hot-swap socket's real
1.85 mm, so the 2.4 mm under the board is a real test and not an assumption. Both slim variants ship
one as `pcb_test.3mf`; it is reversible the same way the board is, so flip it over for the other half.

```sh
SCAD_ARGS='-D build="pcb"' ./build.sh          # the case and plate
openscad -D 'part="pcb_test"' -D 'build="pcb"' -o pcb_test.3mf keyboard.scad
```

Print it flat, bumps up, then turn it over into the case. It checks the outline against the walls
and bosses, that every switch's pins land in a hole, the plate-to-board spacing, where the controller
and the two switches sit, the cell's room, and the 11.5 mm — everything except the copper. What it
cannot tell you: a printed 1.6 mm sheet is floppier than FR-4, so don't judge flex by it.

### The board

20 keys, 39 nets, ~515 tracks, ~16 vias, two layers, 0.3 mm tracks / 0.2 mm clearance / 0.3 mm
smallest drill — the cheapest process any fab offers. Hot-swap sockets, SOD-123 diodes (a
through-hole 1N4148 fits the same land), the controller on 3.5 mm machined low-profile sockets under the
plate window, reset and slide switch poking up through theirs. The controller gets **bare machined pins**
(Mill-Max 3320 or diode legs) — not a pin header with a plastic body: the board has to sit directly on the
sockets, 3.5 mm + its own thickness putting its back flush with the plate top and its USB receptacle inside
the socket gap. A 2.5–3 mm header body between board and sockets lifts the whole controller by that much and
pushes the USB receptacle up into the plate at the wall. The window around the controller runs right up to the
wall line at the USB end (the receptacle overhangs the board there) and the plate's rim is cut away across the
whole window at that end (the wall's notch below stays 12 mm), so the port is open from above rather than hidden
under a bridge and no stub of rim sits over the board's corners (`usb_plate_slot`); the window has 2 mm of clearance on the other sides;
`part = "clash"` renders whatever the plate hits — it should be empty. The silkscreen outlines every
hot-swap socket on both faces, so each one goes where its outline is — and because the outlines on
the two faces are the 180° rotation of each other, the way the right half differs is visible on the
board rather than only in the instructions.

The two builds are **two boards**, not one board with an option: moving the cell moves the bay, two
of the mounting holes and the reset/power positions. They are otherwise identical — same matrix,
same footprints, same firmware; only the bay end of the outline and the parts in it differ.

Both are **reversible**: one design, flipped over for the right half. Three things pay for that, and
each board's `README.md` has the detail —

- **Switches** carry *both* MX pin diagonals and a socket land on each face; on the right half they
  go in rotated 180°, which an MX switch does not care about. (Mirroring the pin pair instead — the
  obvious way — puts two 3 mm holes 2.84 mm apart and they merge into a slot.)
- **The matrix** lands on different GPIOs per half, because flipping swaps the controller's two pin
  rows. The ten holes were chosen so both of each hole's pins are usable GPIOs, keeping
  `pro_micro 1/14/15/16` free on both halves. Hence a separate `pacino_pcb` ZMK shield. (ZMK's
  stock nice!view adapter wants pins 1/2/3 — D1 plus the OLED header's SDA/SCL — and the PCB uses
  2 and 3 for the matrix, so a display on the PCB needs its own `nice_view_spi` on the free
  14/15/16.)
- **The controller** sits on top of the board — the face opposite the sockets — component side
  down, flush in the plate window; the pin lists and the **L**/**R** marks are worked out for that.
- **Power** gets two three-pad solder jumpers (bridge to **L** or **R**). Reset needs none: it sits
  across a pin pair that is GND/RST one way up and RST/GND the other.

```sh
tools/pcb_gen.py                 # both boards, footprint libraries and gerbers
tools/pcb_gen.py --variant=flat  # just one
```

Everything on them comes from `keyboard.scad` — outline, switch positions, mounting holes, controller
and switch placement — so changing the model and re-running moves the boards with it. There is no
schematic file: the generator declares every net and every connection, and names them the way the ZMK
shield does. Each project ships a `*_gerbers.zip` ready to upload; order ten and you have five
keyboards' worth of both halves.

If you would rather draw your own board, the bootstrap files are still there:
[`docs/pcb/pacino_edge_cuts.dxf`](docs/pcb/pacino_edge_cuts.dxf) (the outline for `Edge.Cuts`) and
[`docs/pcb/pacino_placement.csv`](docs/pcb/pacino_placement.csv) (every position in KiCad
coordinates), both from `tools/kicad_placement.py`. `tools/kicad_layout.py` reads a finished
`.kicad_pcb` back so the case can follow the real board.

## Variant gallery

Every option combination, with previews, sizes and download links:
**[variants/README.md](variants/README.md)** — each directory also carries an exploded-style
`preview_assembly.png`, a `preview_top.png` and its own `wiring_guide.png`.

## Firmware (ZMK)

This repo doubles as the ZMK config — no separate zmk-config repo needed. `config/` holds the
`pacino` shield (matrix, transform, default keymap) and `build.yaml` the build matrix; pushing a
change to either makes **GitHub Actions build the firmware** (Actions tab → latest run →
artifacts → `.uf2` files for left, right and `settings_reset`). SuperMini nRF52840 clones flash
as `nice_nano_v2`: double-tap reset, drag the `.uf2` on.

The slim PCB build has its own shield, **`pacino_pcb`** (same layout, same matrix, same keymap):
the reversible board puts the matrix on a different set of GPIOs on each half, so it cannot share
`pacino_left` / `pacino_right`. Both shields are in the build matrix; take the `pacino_pcb_*`
artifacts if you built the board. The pin lists are in
[`pcb/README.md`](pcb/README.md) and `tools/pcb_gen.py` prints them.

Electrical matrix ([`docs/wiring_guide.png`](docs/wiring_guide.png) draws it pin by pin) — 5 columns × 5 rows
per half, diodes `col2row` (Amoeba-King: switch → diode → ROW pad):

| matrix | wires to | nice!nano pin |
|---|---|---|
| row 0 / 1 / 2 | top / home / bottom key row | `pro_micro` 20 / 19 / 18 |
| row 3 | the two extra keys | `pro_micro` 16 |
| row 4 | the three thumbs | `pro_micro` 10 |
| col 0…4 | pinky → inner column (each column chain includes its extra key and thumb) | `pro_micro` 9 / 8 / 7 / 6 / 5 |

Pins 1, 2 and 3 are left free: that is where ZMK's stock `nice_view_adapter` puts the nice!view
(CS on D1, MOSI and SCK on the OLED header's SDA/SCL, plus VCC and GND), so the display variant is
this same wiring plus `nice_view_adapter nice_view` after the shield in `build.yaml` — no rewiring,
and nothing to add to `config/pacino.conf` (the nice_view shield enables the display itself). Pins
14/15/16 are the AVR pro micro's SPI pins; the nRF52840 puts SPI anywhere. Edit your keymap in
`config/pacino.keymap`. The left half is the central
side. The shield covers the default 5-column + 2-extra layout; the 6-column or no-extra variants
need a matching edit to the transform and one more column pin.

## Requirements

- OpenSCAD 2025.03+ (Manifold backend) — `/Applications/OpenSCAD.app`
- FreeCAD 1.0+ for STEP — `/Applications/FreeCAD.app` (only for `build.sh step`)
- Python 3 for the tools
- KiCad 9 for the PCB — `tools/pcb_gen.py` runs itself under KiCad's bundled Python (`pcbnew`)
  and uses `kicad-cli` for the gerbers

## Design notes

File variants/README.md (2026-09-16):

# Variants

Every combination of the four options. Each directory has `case_{left,right}` and `plate_{left,right}`
as **.step** (Fusion 360 / CAD) and **.3mf** (slicer) -- the case also as `case_*.bambu.3mf`, a Bambu Studio / Orca
project with a support blocker over the MagSafe ring pocket, for printing with supports on -- plus a bezel for the display versions, previews, and a
`wiring_guide.png` showing the underside with the wall, the floor pillars, the matrix and every wire to its nice!nano pin, all clash-free.
Print the plate top-side down, the case as-is with a pause before layer 5 to drop the MagSafe ring into its pocket; hardware and assembly notes are in the main README.

| variant | columns | keys/half | battery | nice!view | half size (mm) | preview |
|---|---|---|---|---|---|---|
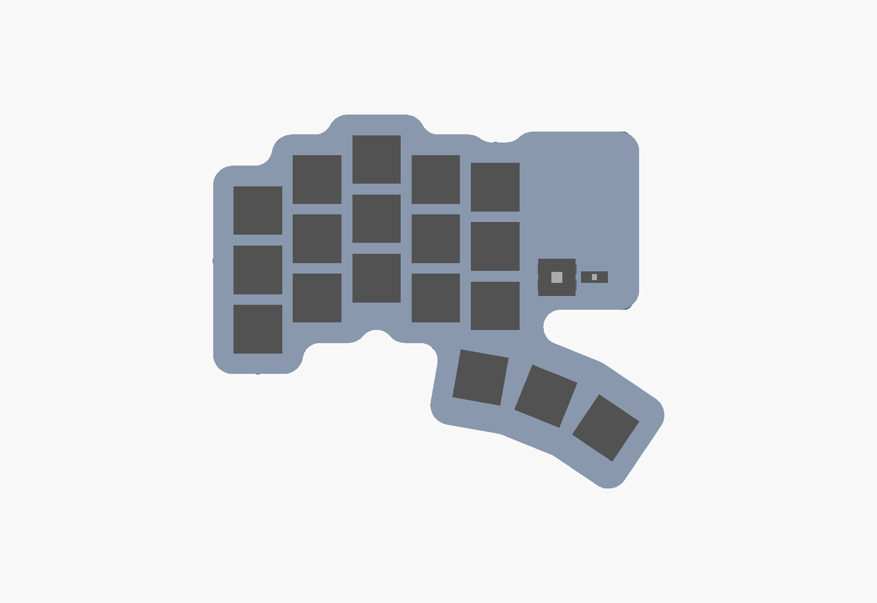
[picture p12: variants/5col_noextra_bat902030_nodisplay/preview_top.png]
| [`5col_noextra_bat902030_nodisplay`](5col_noextra_bat902030_nodisplay/) | 5 | 18 | 902030 | no | 145 × 120 |  |
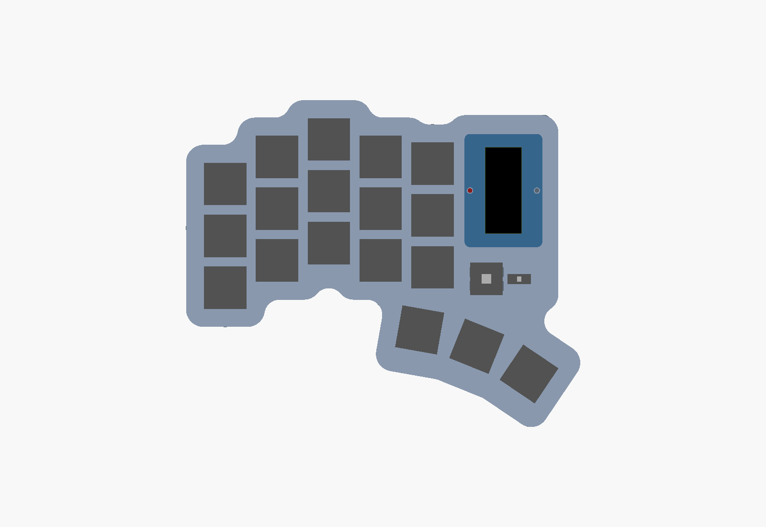
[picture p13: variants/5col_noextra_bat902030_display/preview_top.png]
| [`5col_noextra_bat902030_display`](5col_noextra_bat902030_display/) | 5 | 18 | 902030 | yes | 145 × 120 |  |
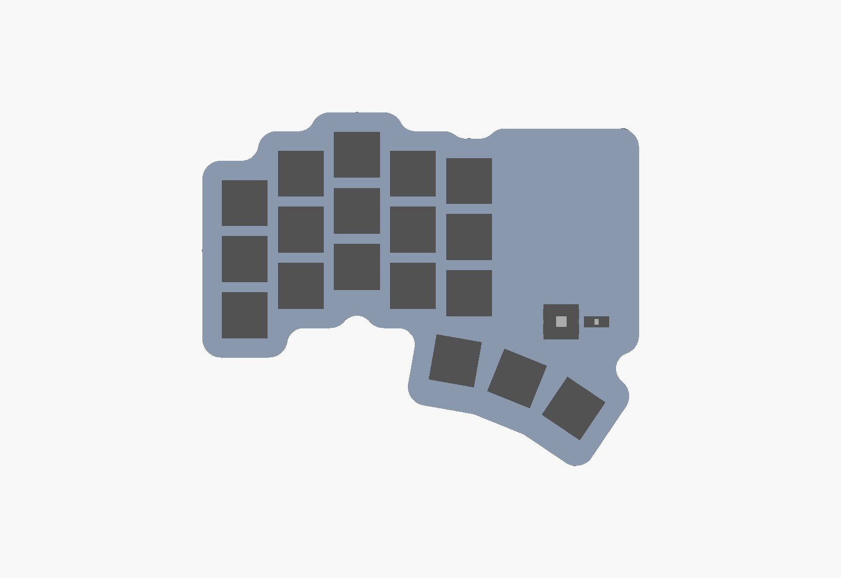
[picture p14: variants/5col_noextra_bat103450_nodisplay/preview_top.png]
| [`5col_noextra_bat103450_nodisplay`](5col_noextra_bat103450_nodisplay/) | 5 | 18 | 103450 | no | 148 × 120 |  |
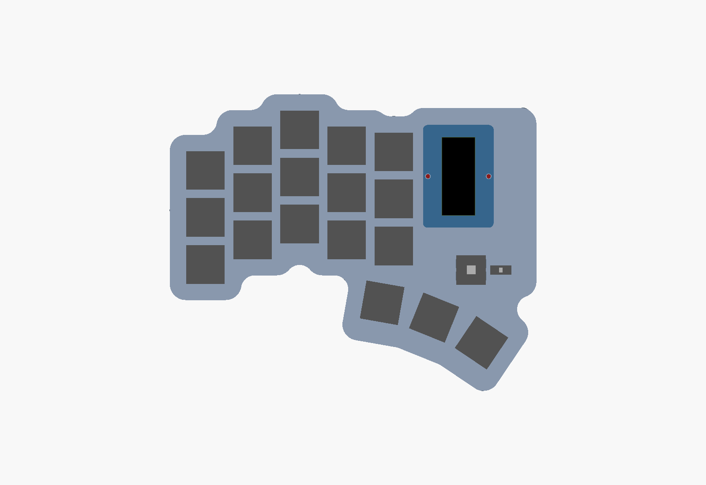
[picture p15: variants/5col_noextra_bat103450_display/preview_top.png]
| [`5col_noextra_bat103450_display`](5col_noextra_bat103450_display/) | 5 | 18 | 103450 | yes | 148 × 120 |  |
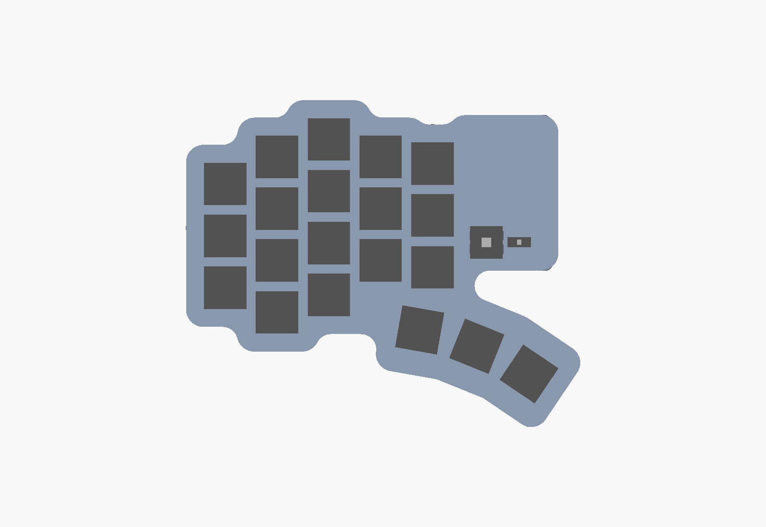
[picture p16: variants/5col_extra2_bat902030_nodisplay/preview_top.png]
| [`5col_extra2_bat902030_nodisplay`](5col_extra2_bat902030_nodisplay/) | 5 | 20 | 902030 | no | 145 × 120 |  |
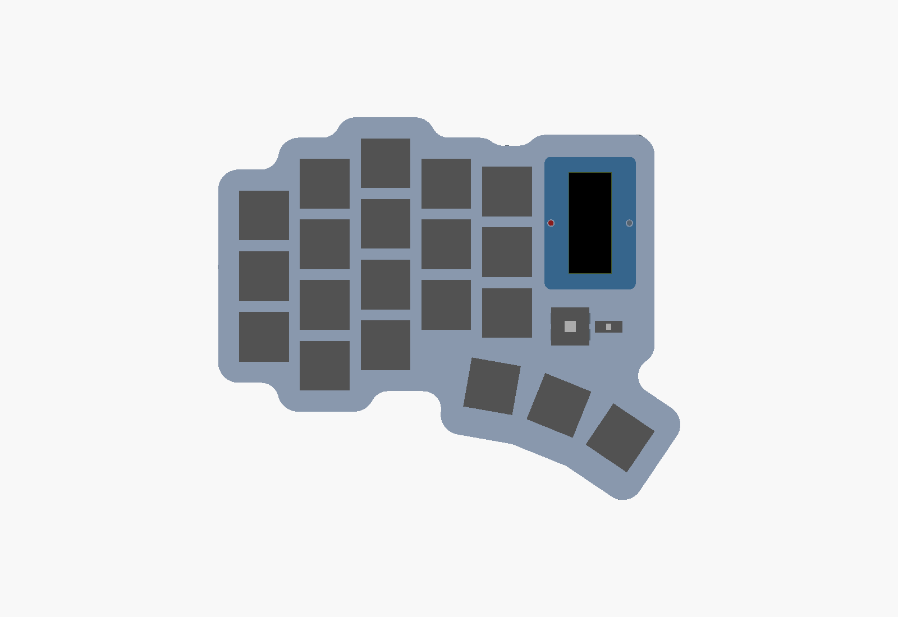
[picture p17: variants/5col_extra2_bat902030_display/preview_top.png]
| [`5col_extra2_bat902030_display`](5col_extra2_bat902030_display/) | 5 | 20 | 902030 | yes | 145 × 120 |  |
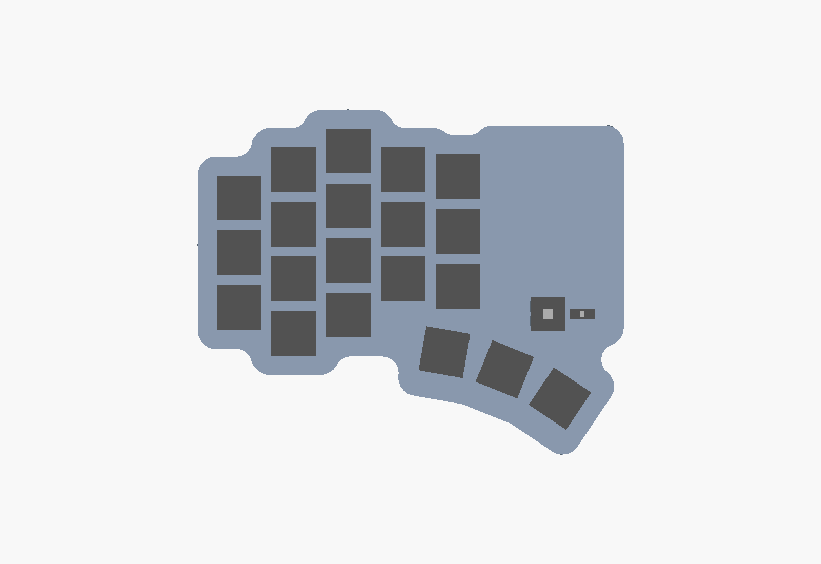
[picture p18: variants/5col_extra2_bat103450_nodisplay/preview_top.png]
| [`5col_extra2_bat103450_nodisplay`](5col_extra2_bat103450_nodisplay/) | 5 | 20 | 103450 | no | 148 × 120 |  |
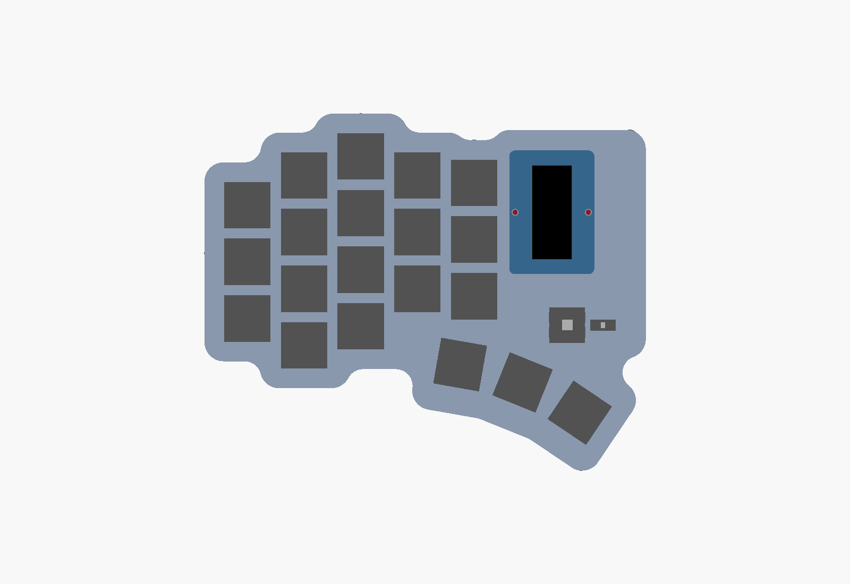
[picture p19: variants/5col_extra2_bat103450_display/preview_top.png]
| [`5col_extra2_bat103450_display`](5col_extra2_bat103450_display/) | 5 | 20 | 103450 | yes | 148 × 120 |  |
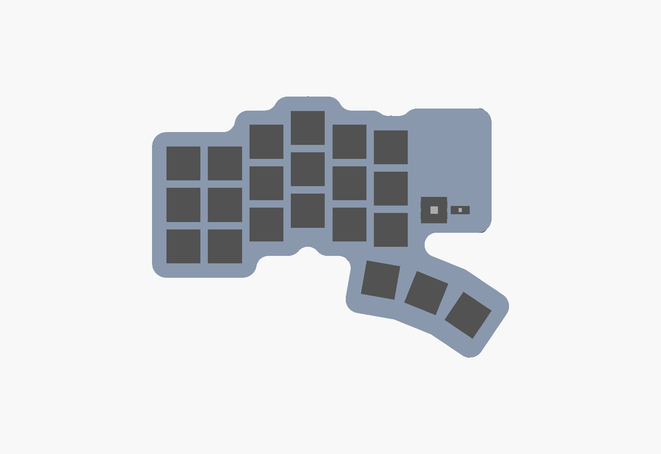
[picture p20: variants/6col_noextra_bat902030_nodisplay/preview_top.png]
| [`6col_noextra_bat902030_nodisplay`](6col_noextra_bat902030_nodisplay/) | 6 | 21 | 902030 | no | 164 × 120 |  |
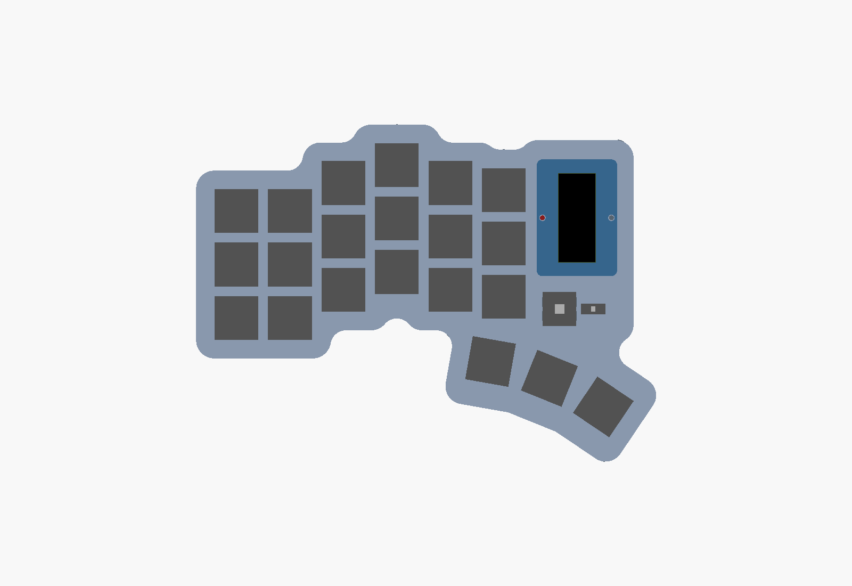
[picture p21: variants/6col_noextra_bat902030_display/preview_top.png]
| [`6col_noextra_bat902030_display`](6col_noextra_bat902030_display/) | 6 | 21 | 902030 | yes | 164 × 120 |  |
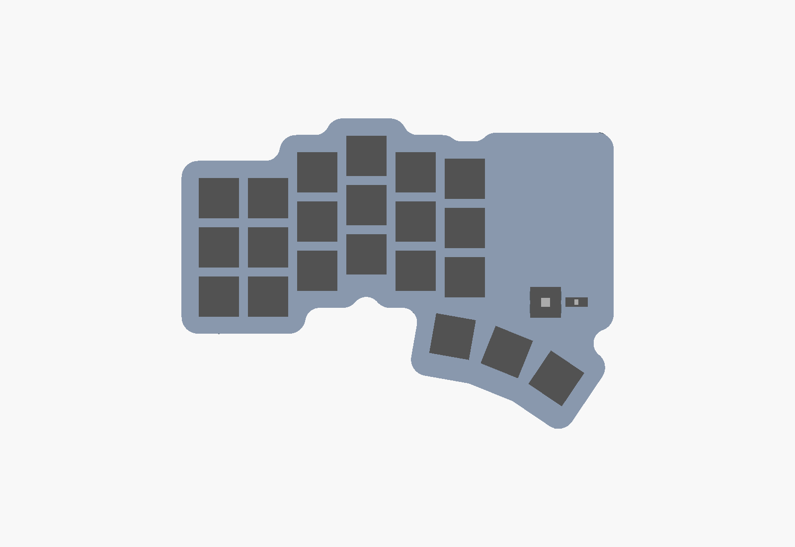
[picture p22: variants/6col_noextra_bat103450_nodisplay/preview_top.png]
| [`6col_noextra_bat103450_nodisplay`](6col_noextra_bat103450_nodisplay/) | 6 | 21 | 103450 | no | 167 × 120 |  |
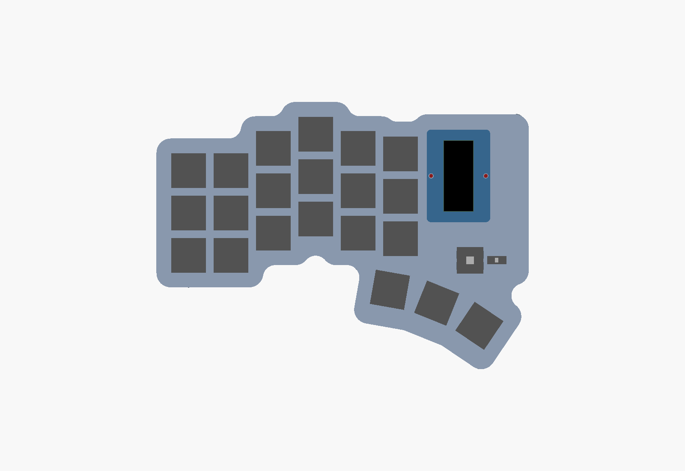
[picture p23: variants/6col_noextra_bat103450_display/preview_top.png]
| [`6col_noextra_bat103450_display`](6col_noextra_bat103450_display/) | 6 | 21 | 103450 | yes | 167 × 120 |  |
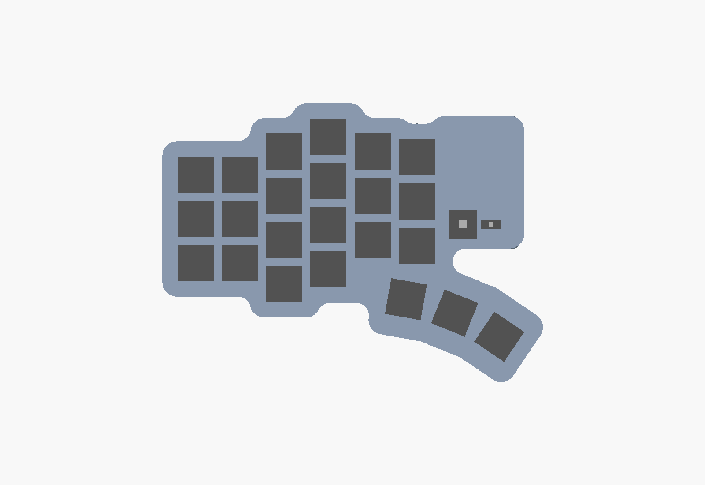
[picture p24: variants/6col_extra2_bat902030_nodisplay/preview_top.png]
| [`6col_extra2_bat902030_nodisplay`](6col_extra2_bat902030_nodisplay/) | 6 | 23 | 902030 | no | 164 × 120 |  |
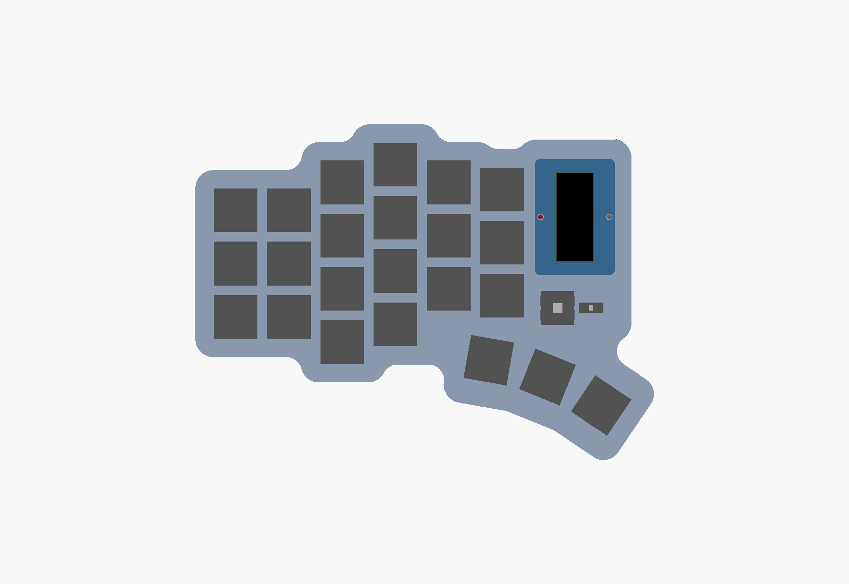
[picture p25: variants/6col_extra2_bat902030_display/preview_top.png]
| [`6col_extra2_bat902030_display`](6col_extra2_bat902030_display/) | 6 | 23 | 902030 | yes | 164 × 120 |  |
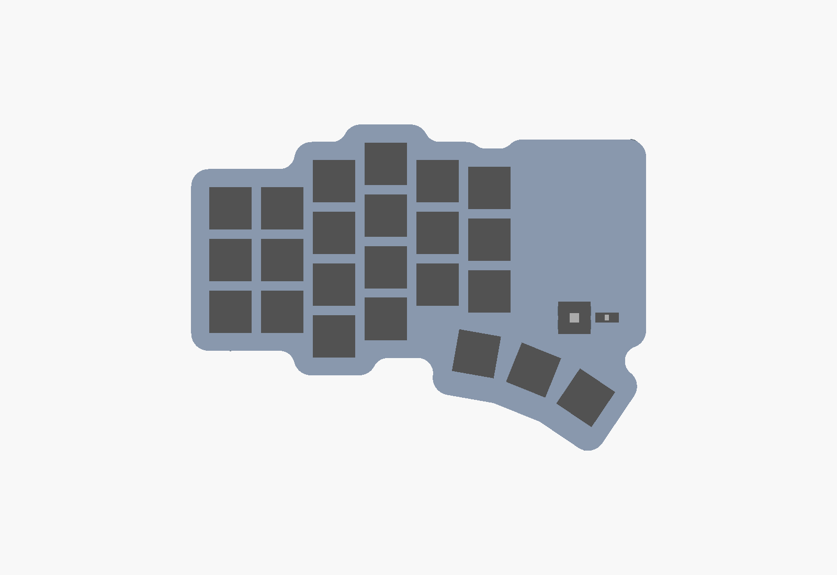
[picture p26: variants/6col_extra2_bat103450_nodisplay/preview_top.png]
| [`6col_extra2_bat103450_nodisplay`](6col_extra2_bat103450_nodisplay/) | 6 | 23 | 103450 | no | 167 × 120 |  |
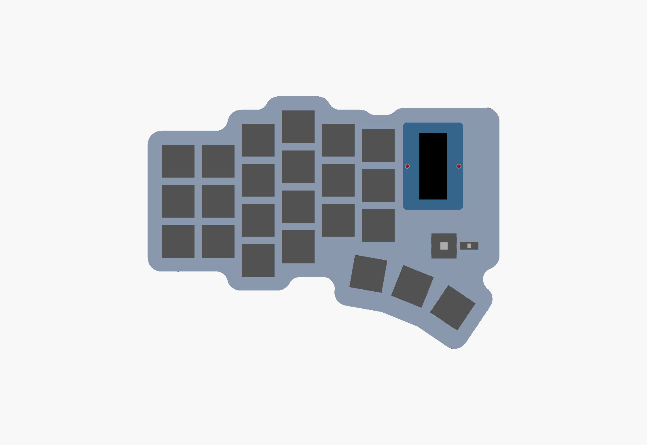
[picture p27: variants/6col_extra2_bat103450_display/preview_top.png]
| [`6col_extra2_bat103450_display`](6col_extra2_bat103450_display/) | 6 | 23 | 103450 | yes | 167 × 120 |  |
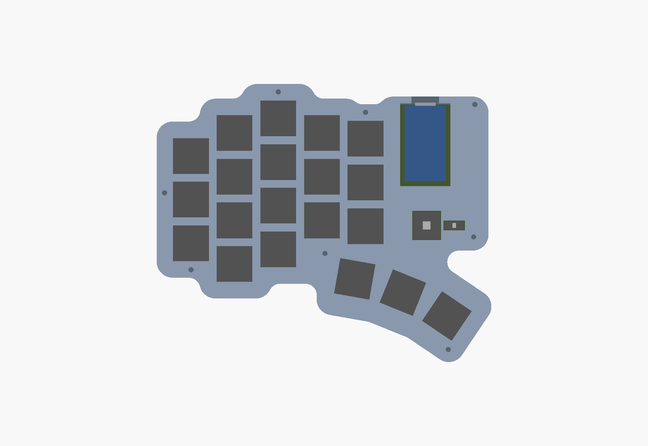
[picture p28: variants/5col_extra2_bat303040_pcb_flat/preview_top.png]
| [`5col_extra2_bat303040_pcb_flat`](5col_extra2_bat303040_pcb_flat/) | 5 | 20 | 303040, flat (under the board) | no | 146 × 121 |  |
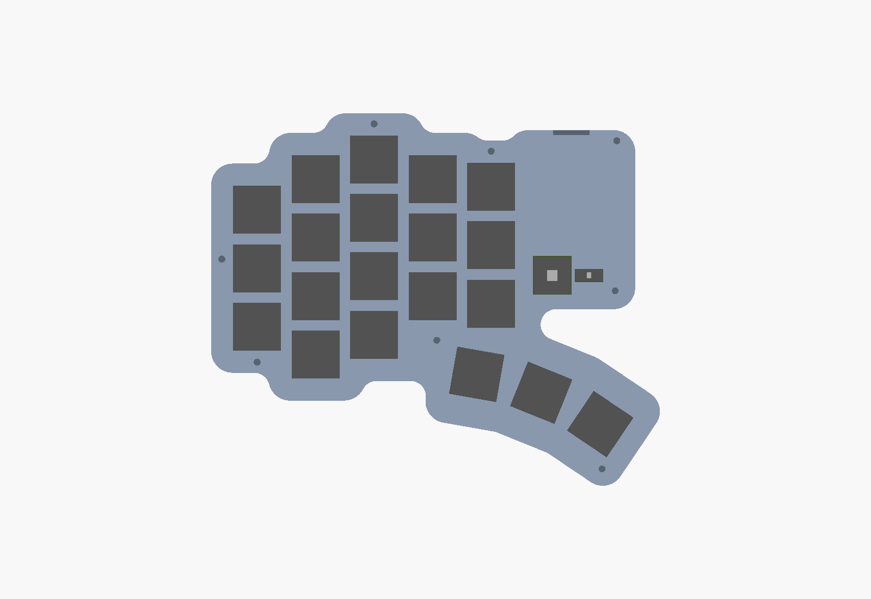
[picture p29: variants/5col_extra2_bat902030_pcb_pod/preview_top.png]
| [`5col_extra2_bat902030_pcb_pod`](5col_extra2_bat902030_pcb_pod/) | 5 | 20 | 902030, in a plate pod | no | 146 × 121 |  |

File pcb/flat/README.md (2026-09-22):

# pacino_flat

The board for the slim build whose cell sits **in a well in the case floor, entirely under the board -- the plate is flat**.
Cell: **303040 (3 x 30 x 40, ~320 mAh)**.  Case half: [`variants/5col_extra2_bat303040_pcb_flat`](../../variants/5col_extra2_bat303040_pcb_flat/).

The two slim builds are two boards, not one board with an option: moving the cell moves the bay, two
of the mounting holes and the reset/power positions. The matrix, the footprints and the firmware are
identical between them.

Generated by [`tools/pcb_gen.py`](../../tools/pcb_gen.py) -- **do not hand-edit
`pacino_flat.kicad_pcb`**; change the generator (or `keyboard.scad`, which the outline and every
position come from) and re-run it. There is no schematic file: the generator declares every net and
every connection, and names the nets the way the ZMK shield names them.

    tools/pcb_gen.py                 # both boards, with gerbers and renders
    tools/pcb_gen.py --variant=flat  # just this one
    tools/pcb_gen.py --no-render     # skip the raytracing while iterating

pacino_flat

20 keys, 39 nets, 557 tracks, 21 vias. Two layers, 1.6 mm, 0.3 mm tracks,
0.2 mm clearance, 0.3 mm smallest drill -- inside every fab's cheapest process.

## One board, both halves

The board is **reversible**: build the left half with the parts on the back, flip the board over and
build the right half with the parts on the front. The silkscreen on each face says which half it is.
Three things make that work.

**Switches.** Every switch footprint carries *both* MX pin diagonals -- the normal pair and its 180
degree rotation -- and a hot-swap socket land on each face. On the right half the switches and the
sockets go in **rotated 180 degrees**; MX switches are square and their stems are symmetric, so
nothing about the feel, the keycaps or the plate changes. (Mirroring the pin pair instead, which is
the obvious way to do it, puts two 3 mm holes 2.84 mm apart -- they would merge into a slot.)

**Matrix.** The controller sits on the face *opposite* the sockets and diodes -- on top of the board,
component side towards it, flush in the plate's window -- and flipping the board swaps its two pin
rows but not the position along a row, so each hole is one pin on the left half and a different one
on the right. The ten matrix holes were
chosen so that *both* of their pins are usable GPIOs and neither is one of `pro_micro 1/14/15/16` --
the nice!view's CS/MISO/SCK/MOSI stay free on both halves. The two halves therefore need different
pin lists in ZMK -- which is why the slim build has its own shield, `pacino_pcb`, whose two overlays
differ from each other (the hand-wired `pacino` shield is unchanged and unrelated):

| net | hole | left half | right half |
|---|---|---|---|
| `ROW0` | U1 pad 20 | `pro_micro 2` | `pro_micro 21` |
| `ROW1` | U1 pad 19 | `pro_micro 3` | `pro_micro 20` |
| `ROW2` | U1 pad 18 | `pro_micro 4` | `pro_micro 19` |
| `ROW3` | U1 pad 17 | `pro_micro 5` | `pro_micro 18` |
| `ROW4` | U1 pad 13 | `pro_micro 9` | `pro_micro 10` |
| `COL0` | U1 pad 5 | `pro_micro 21` | `pro_micro 2` |
| `COL1` | U1 pad 6 | `pro_micro 20` | `pro_micro 3` |
| `COL2` | U1 pad 7 | `pro_micro 19` | `pro_micro 4` |
| `COL3` | U1 pad 8 | `pro_micro 18` | `pro_micro 5` |
| `COL4` | U1 pad 12 | `pro_micro 10` | `pro_micro 9` |

**Power.** RAW and GND have no symmetric partner, so each gets a three-pad solder jumper: bridge the
centre pad to the pad marked **L** or **R** for the half you are building. The mark is printed on
the face the controller sits on (the face opposite the sockets), and that is the pad to bridge.
Boards generated before September 2026 have the letters the other way round: on those, still bridge
the marked pad on the controller's face, whatever letter it shows. Reset needs no jumper -- the
switch sits across the `(rowA,3)`/`(rowB,3)` pair, which is GND/RST one way up and RST/GND the
other; a 12 mm tactile links its two legs 12.5 mm apart internally, and the footprint puts those on
one net (boards from before the same date have it the other way and short RST to GND: fit the
switch by two diagonal legs only).

| jumper | bridge to | left half | right half |
|---|---|---|---|
| `JP1` RAW | centre -> L or R | pad 1 = `RAW` | pad 24 = `RAW` |
| `JP2` GND | centre -> L or R | pad 21 = `GND` | pad 4 = `GND` |

## Assembly

1. Pick your half and work on **that face only** -- the one whose silkscreen names your half.
2. Diodes: cathode (the bar) towards the marked end. The land takes a SOD-123 on either face, or a
   through-hole 1N4148 bent to 3.3 mm.
3. Hot-swap sockets, one per key, on the same face -- the silkscreen outlines each one, so the
   socket goes where its outline is. **Right half: rotated 180 degrees**; the outlines on that face
   are drawn that way round, so follow them rather than the other side's.
4. Reset and slide switch: through-hole, bodies on the *other* face -- they poke up through their
   windows in the plate.
5. Sockets for the controller on the **other** face -- the plate side, with the reset and slide
   switch bodies. The nano sits on top of the board, **component side down** (towards the board:
   its USB shell lives in the 3.5 mm socket gap), USB towards the notch in the wall, and finishes
   flush in the plate's window. The nano's own B+ / B- pads stay empty; the battery reaches it
   through RAW / GND -- *after* the slide switch, so **charge with the switch on**: switched off, the
   charger sees no cell and its blue LED blinks instead of charging.
6. Bridge `JP1` and `JP2` to the pad marked for your half.
7. Battery leads to `BAT +` / `-`; the cell lies in the floor well beneath them.

## Bill of materials (per half)

| qty | part | notes |
|---|---|---|
| 20 | Kailh MX hot-swap socket | CPG151101S11, one per key, on the face you assemble |
| 20 | 1N4148W diode | SOD-123; a through-hole 1N4148 on 3.3 mm pitch fits the same land |
| 20 | MX switch | plate-mount 3-pin or PCB-mount 5-pin, 3x 1.25u for the thumbs |
| 1 | nice!nano v2 / nRF52840 SuperMini | component side DOWN on 3.5 mm low-profile sockets |
| 2 | 1x12 machined low-profile socket | Mill-Max and similar; a normal stamped 2.54 header stands ~8.5 mm and will not fit under the plate |
| 2 | 1x12 machined pin strip | into the controller's castellations, pins out of its COMPONENT side. Measure board surface to controller underside with a pin seated: that is mcu_socket_h (3.5 mm by default, and it cannot go below 3.5 -- the USB shell hangs 3.2 mm under the board) |
| 1 | 12x12 mm THT tactile switch | reset, tall plunger, through the plate window |
| 1 | SS12D00 slide switch | power, through the plate window |
| 1 | LiPo cell 303040 (3 x 30 x 40, ~320 mAh) | in a well in the case floor, entirely under the board -- the plate is flat |

Plus, from the case: 8 x M2x3x3.5 heat-set inserts, 8 x M2x10 screws, 8 x 10 mm bumpons.

## Why the mounting holes are notches

Five of the eight are half-circles in the edge rather than holes through the board; the other three
(the thumb end, the bay's bottom corner and the one between the columns) are real holes. That follows
from the case: five of its screw bosses sit 0.5 mm inside the inner wall line so they merge into the
wall, and the board is the cavity less 0.5 mm -- so those screws' centres land exactly on the board's
edge. The other three bosses stand 2.5-3 mm clear of the wall, because the wall keeps rising past the
bosses in this build and an insert hole at the wall line would be tucked under it; the five that stay
on the line get a 4 mm channel up the inside of the wall instead, so their inserts and screws drop in.

Nothing is bolted through the board. It is **clamped**: the case's 6 mm bosses come up to its
underside and the plate's 5 mm spacer bosses come down onto its top, about 8 mm2 of board between
them at each point, and the M2 screw passes through the notch on its way from the plate into the
boss. The notches also locate the board -- each one hugs a screw shank, so the board cannot shift in
the 0.5 mm of slack around it. Fit the board with the screws out, then drop them through.

## Ordering

Two-layer, 1.6 mm, any finish, no controlled impedance. `pacino_flat_gerbers.zip` is ready to upload.
Order it twice over (or ten boards, which is the usual minimum) -- the same board is both halves.

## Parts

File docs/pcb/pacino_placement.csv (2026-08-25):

type | ref | x_model | y_model | rot_deg | x_kicad | y_kicad | note
switch | SW1 | 0 | 0 | 0 | 60.0 | 120.0 | 1u MX hotswap
switch | SW2 | 0 | 19.05 | 0 | 60.0 | 100.95 | 1u MX hotswap
switch | SW3 | 0 | 38.1 | 0 | 60.0 | 81.9 | 1u MX hotswap
switch | SW4 | 19.05 | 10 | 0 | 79.05 | 110.0 | 1u MX hotswap
switch | SW5 | 19.05 | 29.05 | 0 | 79.05 | 90.95 | 1u MX hotswap
switch | SW6 | 19.05 | 48.1 | 0 | 79.05 | 71.9 | 1u MX hotswap
switch | SW7 | 38.1 | 16.4 | 0 | 98.1 | 103.6 | 1u MX hotswap
switch | SW8 | 38.1 | 35.45 | 0 | 98.1 | 84.55 | 1u MX hotswap
switch | SW9 | 38.1 | 54.5 | 0 | 98.1 | 65.5 | 1u MX hotswap
switch | SW10 | 57.15 | 10 | 0 | 117.15 | 110.0 | 1u MX hotswap
switch | SW11 | 57.15 | 29.05 | 0 | 117.15 | 90.95 | 1u MX hotswap
switch | SW12 | 57.15 | 48.1 | 0 | 117.15 | 71.9 | 1u MX hotswap
switch | SW13 | 76.2 | 7.5 | 0 | 136.2 | 112.5 | 1u MX hotswap
switch | SW14 | 76.2 | 26.55 | 0 | 136.2 | 93.45 | 1u MX hotswap
switch | SW15 | 76.2 | 45.6 | 0 | 136.2 | 74.4 | 1u MX hotswap
switch | SW16 | 19.05 | -9.05 | 0 | 79.05 | 129.05 | 1u MX hotswap
switch | SW17 | 38.1 | -2.65 | 0 | 98.1 | 122.65 | 1u MX hotswap
switch | SW18 | 71.5 | -15.5 | 80 | 131.5 | 135.5 | 1.25u MX hotswap
switch | SW19 | 92.5 | -21.5 | 68 | 152.5 | 141.5 | 1.25u MX hotswap
switch | SW20 | 111.7 | -31.7 | 56 | 171.7 | 151.7 | 1.25u MX hotswap
hole | H1 | -11.5 | 22 | 0 | 48.5 | 98.0 | M2 clearance 2.2, screw passes into the case boss below
hole | H2 | 0 | -11.5 | 0 | 60.0 | 131.5 | M2 clearance 2.2, screw passes into the case boss below
hole | H3 | 38.1 | 66 | 0 | 98.1 | 54.0 | M2 clearance 2.2, screw passes into the case boss below
hole | H4 | 76.2 | 57.1 | 0 | 136.2 | 62.9 | M2 clearance 2.2, screw passes into the case boss below
hole | H5 | 58.5 | -4.4 | 0 | 118.5 | 124.4 | M2 clearance 2.2, screw passes into the case boss below
hole | H6 | 112 | -48.2 | 0 | 172.0 | 168.2 | M2 clearance 2.2, screw passes into the case boss below
hole | H7 | 117.1 | 60.5 | 0 | 177.1 | 59.5 | M2 clearance 2.2, screw passes into the case boss below
hole | H8 | 117.6 | 9.2 | 0 | 177.6 | 110.8 | M2 clearance 2.2, screw passes into the case boss below
mcu | U1 | 102.3 | 43.5 | 0 | 162.3 | 76.5 | nice!nano footprint, USB towards +Y (model) / -Y (KiCad)
keepout | BAT | 102.3 | 43.5 | 0 | 162.3 | 76.5 | the cell's footprint: in the plate pod over the controller (default) or in the floor well under the board -- no cutout in either
reset | RSW1 | 96.1 | 16.7 | 0 | 156.1 | 103.3 | PCB-mounted reset (the plate has a window here)
power | PWR1 | 108.1 | 16.7 | 0 | 168.1 | 103.3 | PCB-mounted power slide switch (the plate has a window here)

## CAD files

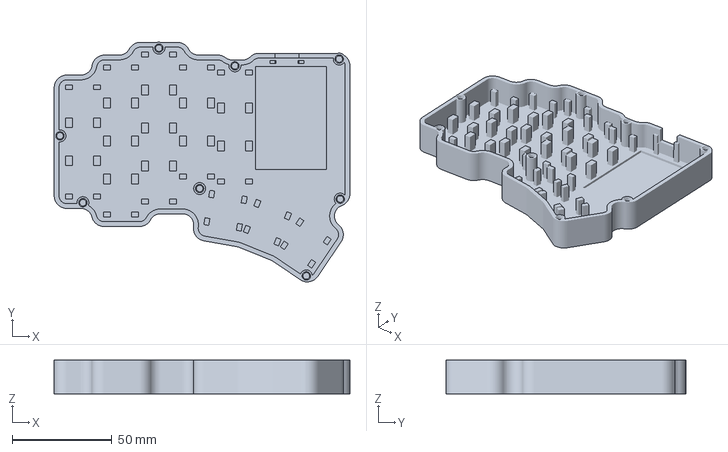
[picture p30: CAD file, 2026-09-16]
variants/5col_extra2_bat103450_display/case_left.bambu.3mf
148.4 x 120.2 x 17.0 mm

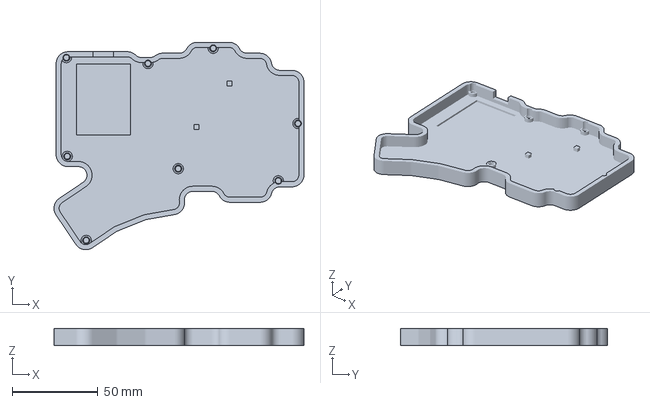
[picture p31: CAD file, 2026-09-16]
variants/5col_extra2_bat303040_pcb_flat/case_right.bambu.3mf
146.1 x 121.3 x 10.0 mm

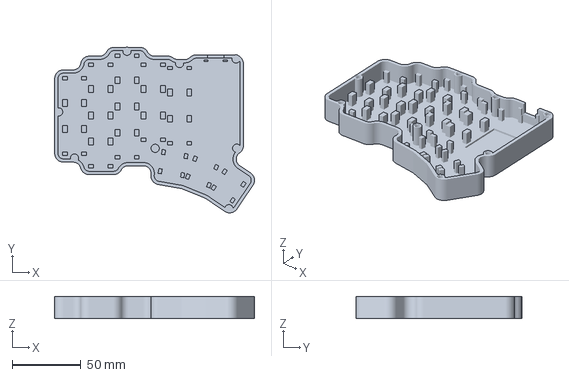
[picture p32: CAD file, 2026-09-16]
variants/5col_extra2_bat902030_display/case_left.bambu.3mf
145.0 x 120.2 x 16.0 mm

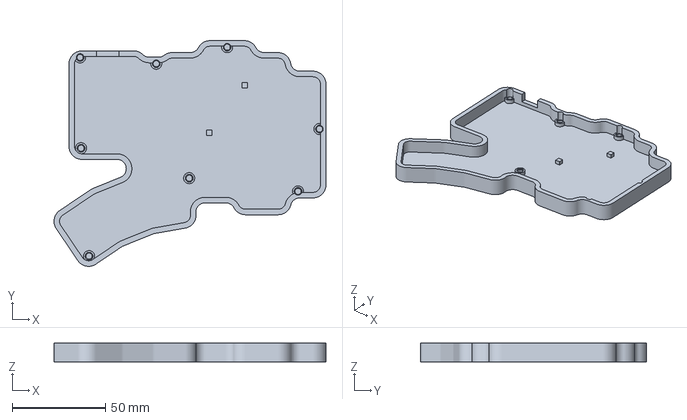
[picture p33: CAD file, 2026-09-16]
variants/5col_extra2_bat902030_pcb_pod/case_right.bambu.3mf
146.1 x 121.3 x 10.0 mm

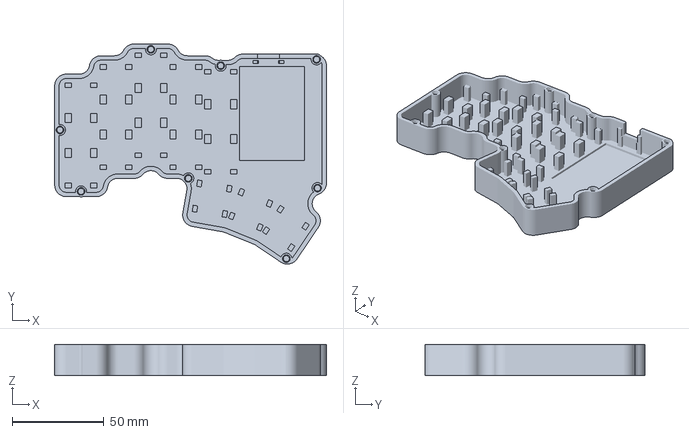
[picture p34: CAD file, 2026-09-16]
variants/5col_noextra_bat103450_display/case_left.bambu.3mf
148.4 x 120.2 x 17.0 mm

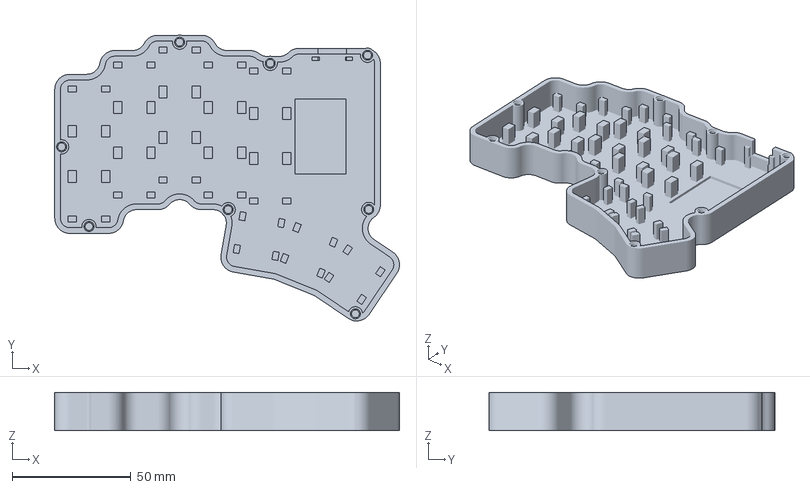
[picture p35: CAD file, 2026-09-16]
variants/5col_noextra_bat902030_display/case_left.bambu.3mf
145.0 x 120.2 x 16.0 mm

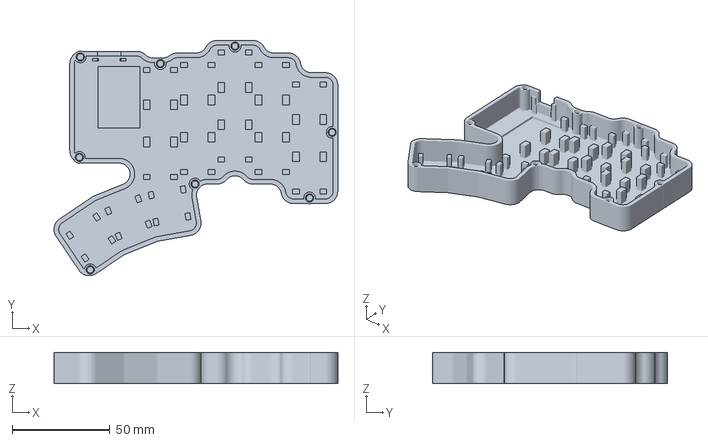
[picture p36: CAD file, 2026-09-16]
variants/5col_noextra_bat902030_nodisplay/case_right.bambu.3mf
145.0 x 120.2 x 16.0 mm

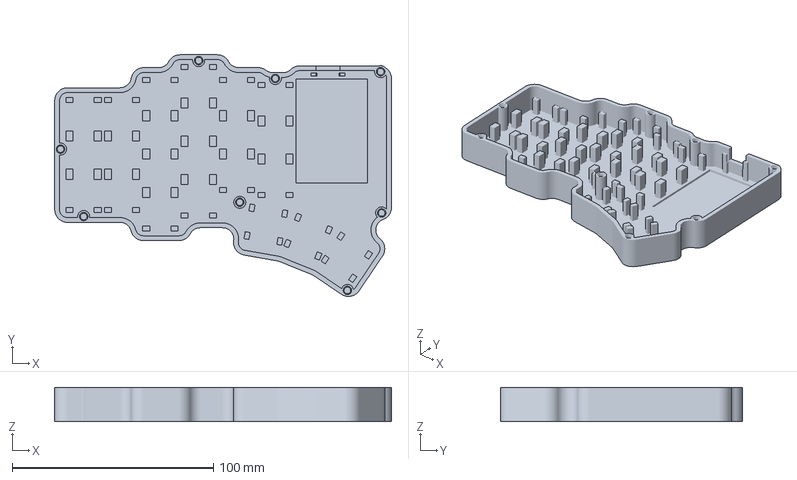
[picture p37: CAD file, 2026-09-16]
variants/6col_extra2_bat103450_display/case_left.bambu.3mf
167.5 x 120.2 x 17.0 mm

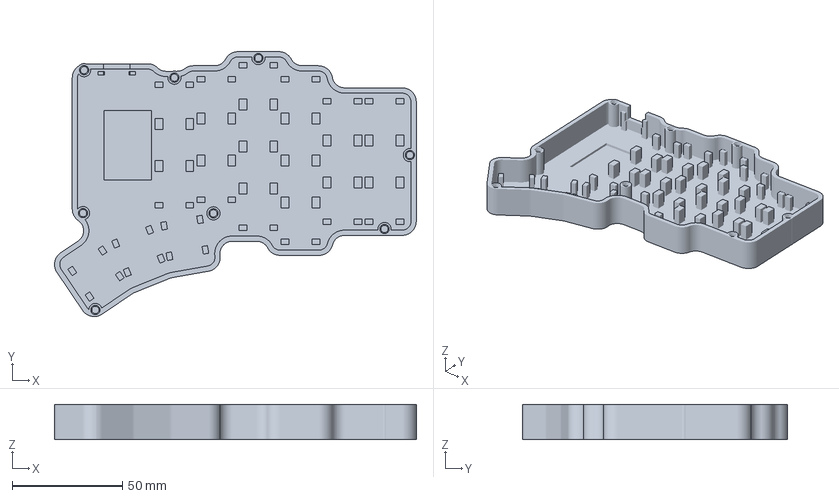
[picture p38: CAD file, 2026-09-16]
variants/6col_extra2_bat902030_display/case_right.bambu.3mf
164.1 x 120.2 x 16.0 mm

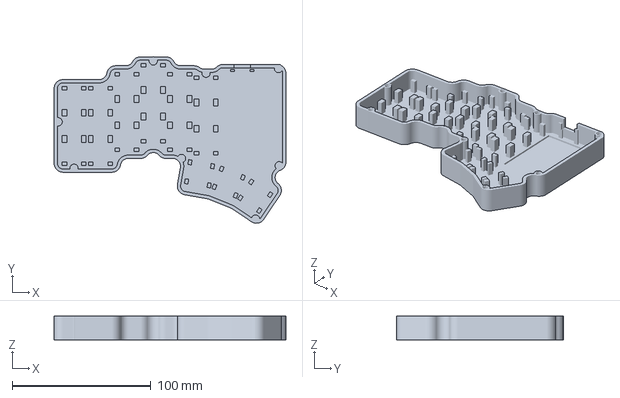
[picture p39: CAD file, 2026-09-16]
variants/6col_noextra_bat103450_display/case_left.bambu.3mf
167.5 x 120.2 x 17.0 mm

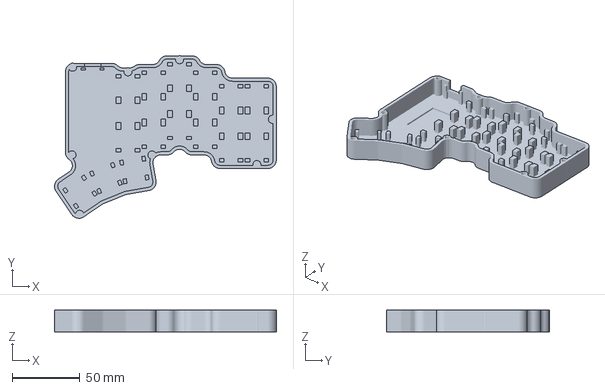
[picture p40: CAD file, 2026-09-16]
variants/6col_noextra_bat902030_display/case_right.bambu.3mf
164.1 x 120.2 x 16.0 mm

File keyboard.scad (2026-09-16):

// keyboard.scad — parametric split keyboard case + switch plate (one half; mirrored for the other)
//
// Default design: cheapino-style 3x5+3 column-stagger layout on a clean 19.05 mm MX grid (1.25u
// portrait thumbs), hand-wired, with an electronics bay beside the inner column holding a LiPo (in
// the case floor), a nice!nano in a cradle that is part of the plate (USB out through the wall),
// and a reset button + power switch below it.  Optional nice!view (nice_view = true).
//
// Tested with OpenSCAD 2025.03 (Manifold backend).  See README.md for the Fusion 360 workflow.
//
// Frame: mm, X right, Y up (away from you), Z up.  Origin = centre of the bottom pinky key of the
// LEFT half.  side="right" mirrors everything in X.
//
// Vertical stack, z=0 at the underside of the case; the wall top is flush with the plate underside:
//   build="plate":  floor_t | cavity_depth                      | plate      (no main PCB; handwire / amoeba PCBs)
//   build="pcb":    floor_t | pcb_lift | PCB | plate_to_pcb-plate_t | plate   (PCB sandwich)

include <layouts/cheapino.scad>
include <layouts/badtemper.scad>

/* [Output] */
part = "assembly"; // [assembly, section, case, plate, bezel, insert_test, pcb_test, clash, plate_2d, case_outline_2d, cavity_2d, pcb_2d, pcb_outline_2d, bezel_2d, info]
// part = "section": 2D cross-section of the assembly through the plane x = section_x (Y across, Z up)
// part = "clash": the case intersected with the plate as assembled, plus (PCB build) the plate with the
// controller -- empty when everything fits
section_x = 123;
side = "left"; // [left, right, both]
// gap between the halves when side = "both"
both_gap = 30;
// lift the plate + keycaps in the assembly view
explode = 0; // [0:1:40]
show_keycaps = true;
show_switches = true;
show_electronics = true;

/* [Layout] */
// grid = parametric column stagger below (default: cheapino geometry on a 19.05 grid);
// cheapino / badtemper = exact positions from those KiCad boards (layouts/*.scad)
layout = "grid"; // [grid, cheapino, badtemper]
grid_rows = 3;
grid_cols = 5;
// per-column Y offset in mm, index 0 = pinky  (cheapino: 0, 10, 16.4, 10, 7.5)
grid_stagger = [0, 10, 16.4, 10, 7.5];
// optional 6th column outside the pinky column (Corne-style 3x6), with its own stagger
grid_outer_col = false;
grid_outer_stagger = 0;
// extra keys as [column, row] on the grid (row -1 = below the bottom row): two keys under the ring and middle
// columns, i.e. under X/C on the left half and ,/. on the right.  [] = none
grid_extra_keys = [[1, -1], [2, -1]];
// thumb keys [x, y, rotation_deg, width_u]: 1.25u caps standing "portrait" (rotation = 90 + fan) so the
// long side points up at the columns, fanned -10/-22/-34 deg around the thumb, 21.8 mm pitch along the arc
// (~1.5 mm between caps at their lower ends, 1.7 mm to the bottom row); first key where the cheapino has it
grid_thumbs = [[71.5, -15.5, 80, 1.25], [92.5, -21.5, 68, 1.25], [111.7, -31.7, 56, 1.25]];
// mounting bosses / plate screws [x, y] around the key block: on the perimeter (0.5 mm inside the inner
// wall line, so they merge into the wall) keeping the matrix clear for hand-wiring; >= 2 mm to switch bodies.
// (Two on the left edge follow the outer column, and two on the bay's right-hand corners are automatic.)
grid_holes = [[38.1, 66], [76.2, 57.1], [58.5, -4.4], [112, -48.2]];
// pcb build: the last of those (thumb end) stands 2.5 mm in from the wall instead of on it, so its insert hole
// is clear of the wall rising past the pillar (see pcb_screw_channel); [] = leave it on the wall line
pcb_thumb_hole = [112.3, -46.3];

/* [Switch] */
switch_type = "mx"; // [mx, choc]
// add the 0.8 mm side reliefs for MX switch clips
cutout_notches = false;
// 0 = default for the switch type (MX 1.5, Choc 1.3)
plate_thickness_override = 0;

/* [Build] */
// plate = switches clip into the plate, no main PCB, bosses run floor-to-plate, MCU cradle in the plate;
// pcb = PCB sandwich: bosses stop at the PCB, plate gets spacer bosses, MCU sits on the PCB
build = "plate"; // [plate, pcb]
// plate build: cavity depth below the plate underside. 0 = automatic: whatever the battery + nano cradle
// stack needs (battery + 4), but at least 10 so there is room under the MX pins for diodes and wires.
// (9-10 mm cells come out at 13.5-14.5, a 6 mm cell at 10.)
cavity_depth = 0;
// pcb build: PCB underside above the floor. 0 = automatic: hotswap sockets (2.4) or whatever makes the
// battery -- which sits on the floor, poking through a cutout in the PCB -- fit under the plate
pcb_lift = 0;
pcb_t = 1.6;
// pcb build: MCU socket height above the PCB. The controller board must sit DIRECTLY on the sockets -- bare
// machined pins (Mill-Max 3320 / diode legs), no header body between them: 3.5 + the board = its back flush
// with the plate top, and its USB receptacle (3.2 mm, component side down) inside the socket gap.
mcu_socket_h = 3.5;
// pcb build: plate window around the controller, clearance per side (the pod build uses the pod's interior
// width instead). Its USB end always runs to the wall line: see mcu_window_2d.
mcu_window_margin = 2;
// pcb build: part = "pcb_test" prints a stand-in for the board at pcb_t thick -- the real outline and
// every hole a switch, the controller or the two switches passes through -- so the whole stack can be
// test-fitted before a board is ordered. The stand-ins for the hot-swap sockets are bumps on the
// underside at the socket's real height, which is what makes the 2.4 mm under the board a real test.
pcb_test_sockets = true;
// holes come out undersize when printed; these are the drilled sizes plus a little
pcb_test_slop = 0.2;
// pcb build: floor pillars supporting the board from below between the mounting bosses, [x, y] each, pcb_post
// square, stopping pcb_post_gap under the board. They go in the column gaps, clear of what hangs under the
// board: the hot-swap socket on the pin side of every key, the switch's post and pins, and the diode 8.8 mm
// below each key. The model warns if one lands in those zones and tools/pcb_gen.py keeps diodes off them.
// [] = none. Defaults: one in the ring/middle column gap high up, one in the middle/index gap low down.
pcb_posts = [[28.6, 45.5], [47.8, 20]];
pcb_post = 3;
pcb_post_gap = 0.1;
// pcb build: carry the cell in a pod that is part of the plate, directly over the socketed controller
// (whose bare back finishes flush with the plate top), instead of in a well in the case floor. Below the
// board every millimetre of cell is a millimetre of case; the 3.5 mm above it is fixed by the MX
// plate-to-PCB geometry and otherwise wasted, so this costs no case height at all -- 11.5 mm to the plate
// top, the MX minimum, with the 902030 still in the build. The pod stands battery + pod_wall proud of the
// plate, under the keycaps (14.5). The cell goes in through the MCU window from below and rests on the
// controller; its leads drop into the bay past the window's far end. The board is then solid (no cutout).
battery_pod = true;
pod_wall = 1.2;
pod_clearance = 0.4;

/* [Case] */
wall = 2.4;
// (the pcb build's wall is pcb_wall, under [Mounting]: it depends on the screw channel)
// floor thickness (the bumpon recesses take bumpon_depth out of it)
floor_t = 2.5;
// keys = hull the keycaps (+ bay) with key_margin / corner_r;  pcb = follow the layout's Edge.Cuts + pcb_gap
cavity_from = "keys"; // [keys, pcb]
// keycap edge -> inner wall
key_margin = 3;
// radius of the convex (outer) corners
corner_r = 4;
// notches narrower than this get filled (smooths the column stagger steps and the bay/thumb junction)
fill_r = 8;
// PCB edge -> inner wall (cavity_from = "pcb")
pcb_gap = 0.5;
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

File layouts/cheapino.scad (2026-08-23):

// Generated by tools/kicad_layout.py from ../cheapino/pcb/cheapino.kicad_pcb -- do not edit, re-run instead.
// Units: mm. X right, Y up. Origin = centre of K1 (bottom-left switch).
// KiCad origin of this frame: (69.012, 108.331)

cheapino_keys = [  // [x, y, rot_deg, width_u]
  [75.997, 45.466, 0, 1],  // K1
  [75.997, 26.467, 0, 1],  // K2
  [75.997, 7.468, 0, 1],  // K3
  [56.998, 48.006, 0, 1],  // K4
  [56.998, 29.007, 0, 1],  // K5
  [56.998, 10.008, 0, 1],  // K6
  [37.998, 54.356, 0, 1],  // K7
  [37.998, 35.357, 0, 1],  // K8
  [37.998, 16.358, 0, 1],  // K9
  [18.999, 48.006, 0, 1],  // K10
  [18.999, 29.007, 0, 1],  // K11
  [18.999, 10.008, 0, 1],  // K12
  [0, 37.998, 0, 1],  // K13
  [0, 18.999, 0, 1],  // K14
  [0, 0, 0, 1],  // K15
  [112.598, -21.21, -23, 1],  // K16
  [92.277, -15.494, -10, 1],  // K17
  [71.323, -14.224, 0, 1],  // K18
];

cheapino_holes = [  // [x, y]  (M2-ish mounting holes)
  [84.912, 36.703],  // drill 2.2
  [67.068, 17.019],  // drill 2.2
  [75.768, -3.429],  // drill 2.2
  [8.959, 9.312],  // drill 2.2
  [47.012, 44.927],  // drill 2.2
  [100.152, -24.257],  // drill 2.2
  [27.801, 38.598],  // drill 2.2
  [8.933, 28.472],  // drill 2.2
  [103.2, -8.001],  // drill 2.2
];

cheapino_mcu = [96.596, 38.715, 0, 18, 25.085];  // [cx, cy, rot, width, length]  USB end = +Y before rotation
cheapino_usb = [96.596, 51.257];  // board end where the USB connector sits

cheapino_pcb_outline = [  // 290 points, from Edge.Cuts (1 loop found, longest used)
  [115.035, -32.282],
  [115.555, -32.451],
  [116.097, -32.512],
  [116.641, -32.463],
  [117.164, -32.307],
  [117.646, -32.049],
  [118.066, -31.701],
  [118.408, -31.275],
  [118.658, -30.79],
  [123.218, -20.262],
  [123.433, -19.772],
  [123.567, -19.255],
  [123.618, -18.723],
  [123.584, -18.189],
  [123.466, -17.668],
  [123.268, -17.172],
  [122.993, -16.713],
  [122.65, -16.303],
  [122.246, -15.953],
  [121.792, -15.671],
  [121.299, -15.464],
  [109.868, -10.31],
  [109.395, -10.127],
  [108.945, -9.895],
  [108.521, -9.617],
  [108.129, -9.297],
  [107.773, -8.936],
  [107.456, -8.541],
  [107.183, -8.114],
  [106.956, -7.661],
  [106.778, -7.187],
  [106.651, -6.697],
  [106.575, -6.196],
  [106.553, -5.69],
  [106.386, 23.822],
  [106.434, 24.138],
  [106.618, 24.399],
  [106.898, 24.553],
  [107.218, 24.566],
  [107.574, 24.556],
  [107.896, 24.71],
  [108.112, 24.994],
  [108.174, 25.346],
  [108.011, 47.069],
  [108.06, 47.585],
  [108.031, 48.103],
  [107.923, 48.61],
  [107.74, 49.095],
  [107.485, 49.547],
  [107.165, 49.955],
  [106.787, 50.31],
  [106.359, 50.603],
  [105.892, 50.828],
  [105.396, 50.98],
  [104.883, 51.055],
  [104.365, 51.051],
  [86.394, 51.014],
  [85.88, 51.076],
  [85.403, 51.274],
  [84.997, 51.593],
  [84.692, 52.011],
  [84.512, 52.495],
  [84.469, 53.01],
  [84.371, 53.501],
  [84.093, 53.917],
  [83.676, 54.196],
  [83.185, 54.293],
  [66.556, 54.434],
  [66.143, 54.54],
  [65.774, 54.756],
  [65.48, 55.065],
  [65.283, 55.444],
  [65.167, 55.755],
  [64.953, 56.008],
  [64.665, 56.173],
  [64.338, 56.231],
  [48.648, 56.404],
  [48.123, 56.486],
  [47.669, 56.763],
  [47.357, 57.194],
  [47.234, 57.711],
  [47.202, 61.142],
  [47.131, 61.652],
  [46.875, 62.1],
  [46.47, 62.419],
  [45.975, 62.565],
  [30.785, 62.535],
  [30.305, 62.46],
  [29.89, 62.207],
  [29.604, 61.814],
  [29.49, 61.341],
  [29.489, 57.785],
  [29.323, 57.29],
  [28.999, 56.882],
  [28.556, 56.607],
  [28.045, 56.499],
  [11.417, 56.362],
  [11.074, 56.263],
  [10.784, 56.055],
  [10.581, 55.761],
  [10.489, 55.417],
  [10.418, 49.174],
  [10.357, 48.637],
  [10.178, 48.126],
  [9.89, 47.668],
  [9.508, 47.285],
  [9.05, 46.997],
  [8.539, 46.818],
  [8.001, 46.758],
  [-4.801, 47.156],
  [-5.312, 47.124],
  [-5.816, 47.029],
  [-6.304, 46.872],
  [-6.768, 46.656],
  [-7.203, 46.385],
  [-7.6, 46.061],
  [-7.955, 45.691],
  [-8.26, 45.279],
  [-8.513, 44.833],
  [-8.708, 44.36],
  [-8.843, 43.865],
  [-8.915, 43.358],
  [-8.914, -7.211],
  [-8.869, -7.711],
  [-8.712, -8.188],
  [-8.452, -8.618],
  [-8.101, -8.977],
  [-7.678, -9.248],
  [-7.205, -9.416],
  [-6.706, -9.473],
  [8.23, -9.497],
  [8.729, -9.431],
  [9.193, -9.239],
  [9.593, -8.932],
  [9.899, -8.533],
  [10.092, -8.068],
  [10.157, -7.569],
  [10.27, -0.877],
  [10.333, -0.334],
  [10.52, 0.179],
  [10.82, 0.635],
  [11.218, 1.009],
  [11.692, 1.28],
  [12.216, 1.435],
  [25.806, 1.349],
  [26.311, 1.409],
  [26.787, 1.585],
  [27.209, 1.868],
  [27.554, 2.242],
  [27.801, 2.686],
  [27.937, 3.175],
  [27.96, 4.989],
  [28.084, 5.566],
  [28.388, 6.073],
  [28.838, 6.455],
  [29.387, 6.672],
  [29.977, 6.701],
  [46.086, 6.896],
  [46.636, 6.865],
  [47.155, 6.676],
  [47.597, 6.347],
  [47.926, 5.905],
  [48.114, 5.387],
  [48.146, 4.836],
  [47.978, 2.39],
  [48.041, 1.874],
  [48.217, 1.383],
  [48.497, 0.944],
  [48.867, 0.578],
  [49.308, 0.303],
  [49.8, 0.132],
  [50.317, 0.074],
  [58.709, -0.019],
  [59.229, -0.047],
  [59.736, -0.161],
  [60.218, -0.357],
  [60.661, -0.63],
  [61.053, -0.973],
  [61.382, -1.375],
  [61.64, -1.827],
  [61.82, -2.315],
  [61.916, -2.827],
  [62.704, -21.616],
  [62.855, -22.217],
  [63.182, -22.743],
  [63.655, -23.144],
  [64.228, -23.38],
  [64.728, -23.335],
  [65.228, -23.293],
  [65.728, -23.253],
  [66.229, -23.216],
  [66.729, -23.181],
  [67.23, -23.149],
  [67.731, -23.12],
  [68.232, -23.093],
  [68.733, -23.069],
  [69.235, -23.047],
  [69.736, -23.028],
  [70.238, -23.011],
  [70.739, -22.997],
  [71.241, -22.985],
  [71.743, -22.976],
  [72.245, -22.97],
  [72.747, -22.966],
  [73.248, -22.965],
  [73.75, -22.966],
  [74.252, -22.97],
  [74.754, -22.976],
  [75.256, -22.985],
  [75.757, -22.997],
  [76.259, -23.011],
  [76.761, -23.027],
  [77.262, -23.046],
  [77.763, -23.068],
  [78.265, -23.092],
  [78.766, -23.119],
  [79.267, -23.149],
  [79.768, -23.181],
  [80.268, -23.215],
  [80.769, -23.252],
  [81.269, -23.292],
  [81.769, -23.334],
  [82.269, -23.379],
  [82.769, -23.426],
  [83.268, -23.476],
  [83.767, -23.528],
  [84.266, -23.583],
  [84.764, -23.641],
  [85.263, -23.701],
  [85.761, -23.763],
  [86.258, -23.828],
  [86.756, -23.896],
  [87.252, -23.966],
  [87.749, -24.039],
  [88.245, -24.114],
  [88.741, -24.192],
  [89.236, -24.272],
  [89.731, -24.355],
  [90.226, -24.44],
  [90.72, -24.528],
  [91.214, -24.619],
  [91.707, -24.711],
  [92.199, -24.807],
  [92.692, -24.905],
  [93.183, -25.005],
  [93.674, -25.108],
  [94.165, -25.214],
  [94.655, -25.322],
  [95.145, -25.432],
  [95.634, -25.545],
  [96.122, -25.661],
  [96.61, -25.779],
  [97.097, -25.899],
  [97.584, -26.022],
  [98.07, -26.147],
  [98.555, -26.275],
  [99.039, -26.406],
  [99.523, -26.538],
  [100.007, -26.674],
  [100.489, -26.811],
  [100.971, -26.952],
  [101.452, -27.094],
  [101.933, -27.239],
  [102.412, -27.387],
  [102.891, -27.537],
  [103.369, -27.69],
  [103.847, -27.844],
  [104.323, -28.002],
  [104.799, -28.162],
  [105.274, -28.324],
  [105.748, -28.488],
  [106.221, -28.655],
  [106.693, -28.825],
  [107.165, -28.997],
  [107.636, -29.171],
  [108.105, -29.348],
  [108.574, -29.527],
  [109.042, -29.708],
  [109.509, -29.892],
  [109.975, -30.078],
  [110.44, -30.267],
  [110.904, -30.458],
  [111.367, -30.651],
  [111.829, -30.847],
  [112.29, -31.045],
  [112.751, -31.245],
  [113.21, -31.448],
  [113.668, -31.653],
  [114.125, -31.861],
  [114.581, -32.07],
];

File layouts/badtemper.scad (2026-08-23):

// Generated by tools/kicad_layout.py from ../badtemper2/BadTemper.kicad_pcb -- do not edit, re-run instead.
// Units: mm. X right, Y up. Origin = centre of SW1 (bottom-left switch).
// KiCad origin of this frame: (85.91, 108.5)

badtemper_keys = [  // [x, y, rot_deg, width_u]
  [0, 38.1, 0, 1],  // SW1
  [19.05, 50.1, 0, 1],  // SW2
  [38.1, 56.1, 0, 1],  // SW3
  [57.15, 49.48, 0, 1],  // SW4
  [76.2, 47.1, 0, 1],  // SW5
  [0, 19.05, 0, 1],  // SW6
  [19.05, 31.05, 0, 1],  // SW7
  [38.1, 37.05, 0, 1],  // SW8
  [57.15, 30.43, 0, 1],  // SW9
  [76.2, 28.05, 0, 1],  // SW10
  [0, 0, 0, 1],  // SW11
  [19.05, 12, 0, 1],  // SW12
  [38.1, 18, 0, 1],  // SW13
  [57.15, 11.38, 0, 1],  // SW14
  [76.2, 9, 0, 1],  // SW15
  [63.013, -10.711, 0, 1],  // SW16
  [84.233, -13.613, -15, 1],  // SW17
  [103.812, -21.928, -30, 1],  // SW18
];

badtemper_holes = [  // [x, y]  (M2-ish mounting holes)
  [9.09, 41.698],  // drill 2.2
  [63.061, 38.65],  // drill 2.2
  [9.09, 24.68],  // drill 2.2
];

badtemper_mcu = [92.144, 37.38, 0, 17.78, 33.02];  // [cx, cy, rot, width, length]  USB end = +Y before rotation
badtemper_usb = [92.144, 53.89];  // board end where the USB connector sits

badtemper_pcb_outline = [  // 104 points, from Edge.Cuts (1 loop found, longest used)
  [28.143, 1.633],
  [28.35, 1.681],
  [28.523, 1.804],
  [28.636, 1.984],
  [28.67, 2.2],
  [28.67, 7.242],
  [28.706, 7.452],
  [28.819, 7.633],
  [28.992, 7.756],
  [29.199, 7.803],
  [41.899, 7.803],
  [51.954, -3.403],
  [51.954, -20.439],
  [51.989, -20.649],
  [52.102, -20.829],
  [52.276, -20.952],
  [52.483, -20.999],
  [72.885, -21.003],
  [91.08, -26.166],
  [107.539, -36.214],
  [107.739, -36.276],
  [107.947, -36.254],
  [108.129, -36.15],
  [108.255, -35.982],
  [116.671, -20.47],
  [116.734, -20.264],
  [116.718, -20.049],
  [116.623, -19.855],
  [116.464, -19.709],
  [108.233, -14.872],
  [108.172, 53.965],
  [108.137, 54.175],
  [108.024, 54.355],
  [107.85, 54.478],
  [107.643, 54.526],
  [86.17, 54.514],
  [85.999, 54.546],
  [85.848, 54.63],
  [85.731, 54.759],
  [85.662, 54.918],
  [85.6, 55.092],
  [85.483, 55.235],
  [85.325, 55.33],
  [85.143, 55.366],
  [67.081, 55.35],
  [66.873, 55.398],
  [66.7, 55.521],
  [66.587, 55.701],
  [66.551, 55.911],
  [66.551, 57.591],
  [66.516, 57.801],
  [66.403, 57.981],
  [66.229, 58.104],
  [66.022, 58.152],
  [48.048, 58.169],
  [47.841, 58.217],
  [47.668, 58.34],
  [47.555, 58.52],
  [47.519, 58.73],
  [47.519, 64.912],
  [47.484, 65.122],
  [47.37, 65.302],
  [47.197, 65.425],
  [46.99, 65.472],
  [29.231, 65.457],
  [29.024, 65.41],
  [28.851, 65.287],
  [28.738, 65.107],
  [28.702, 64.897],
  [28.72, 59.342],
  [28.684, 59.132],
  [28.571, 58.952],
  [28.398, 58.829],
  [28.191, 58.782],
  [10.168, 58.782],
  [9.96, 58.734],
  [9.787, 58.611],
  [9.674, 58.431],
  [9.638, 58.221],
  [9.637, 45.879],
  [9.601, 45.67],
  [9.488, 45.49],
  [9.315, 45.367],
  [9.107, 45.319],
  [-8.901, 45.342],
  [-9.108, 45.295],
  [-9.281, 45.172],
  [-9.394, 44.992],
  [-9.43, 44.782],
  [-9.43, -10.687],
  [-9.394, -10.897],
  [-9.281, -11.077],
  [-9.108, -11.2],
  [-8.901, -11.247],
  [9.184, -11.269],
  [9.391, -11.222],
  [9.565, -11.099],
  [9.678, -10.919],
  [9.713, -10.709],
  [9.695, 1.08],
  [9.731, 1.29],
  [9.844, 1.47],
  [10.017, 1.593],
  [10.224, 1.641],
];

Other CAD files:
docs/pcb/pacino_edge_cuts.dxf
variants/5col_extra2_bat103450_nodisplay/case_left.bambu.3mf
variants/5col_extra2_bat902030_nodisplay/case_right.bambu.3mf
variants/5col_noextra_bat103450_nodisplay/case_right.bambu.3mf
variants/6col_extra2_bat103450_nodisplay/case_left.bambu.3mf
variants/6col_extra2_bat902030_nodisplay/case_right.bambu.3mf
variants/6col_noextra_bat103450_nodisplay/case_left.bambu.3mf
variants/5col_extra2_bat103450_display/bezel_left.3mf
variants/5col_extra2_bat103450_display/bezel_left.step
variants/5col_extra2_bat103450_display/bezel_right.3mf
variants/5col_extra2_bat103450_display/bezel_right.step
variants/5col_extra2_bat103450_display/case_left.3mf
variants/5col_extra2_bat103450_display/case_left.step
variants/5col_extra2_bat103450_display/case_right.3mf
variants/5col_extra2_bat103450_display/case_right.bambu.3mf
variants/5col_extra2_bat103450_display/case_right.step
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

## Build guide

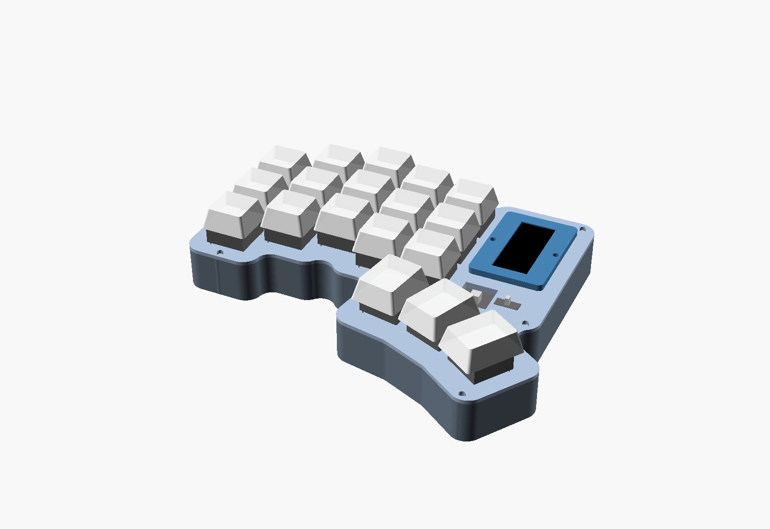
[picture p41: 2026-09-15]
variants/5col_noextra_bat902030_display/preview_assembly.png

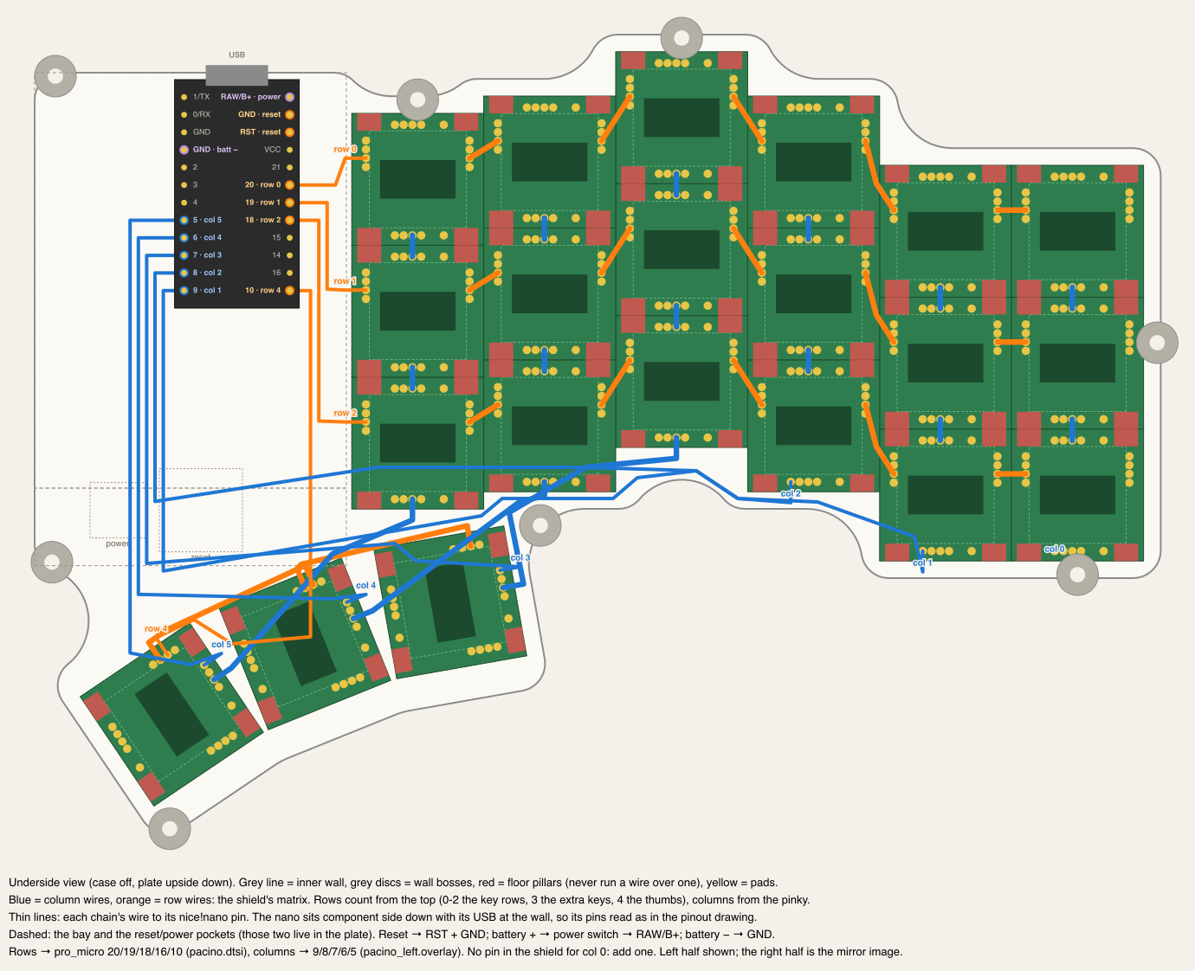
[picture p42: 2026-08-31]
variants/6col_noextra_bat103450_nodisplay/wiring_guide.png

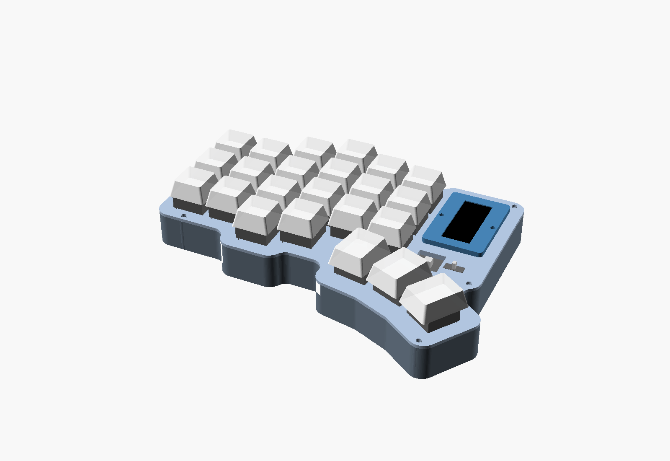
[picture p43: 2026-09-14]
variants/6col_extra2_bat902030_display/preview_assembly.png

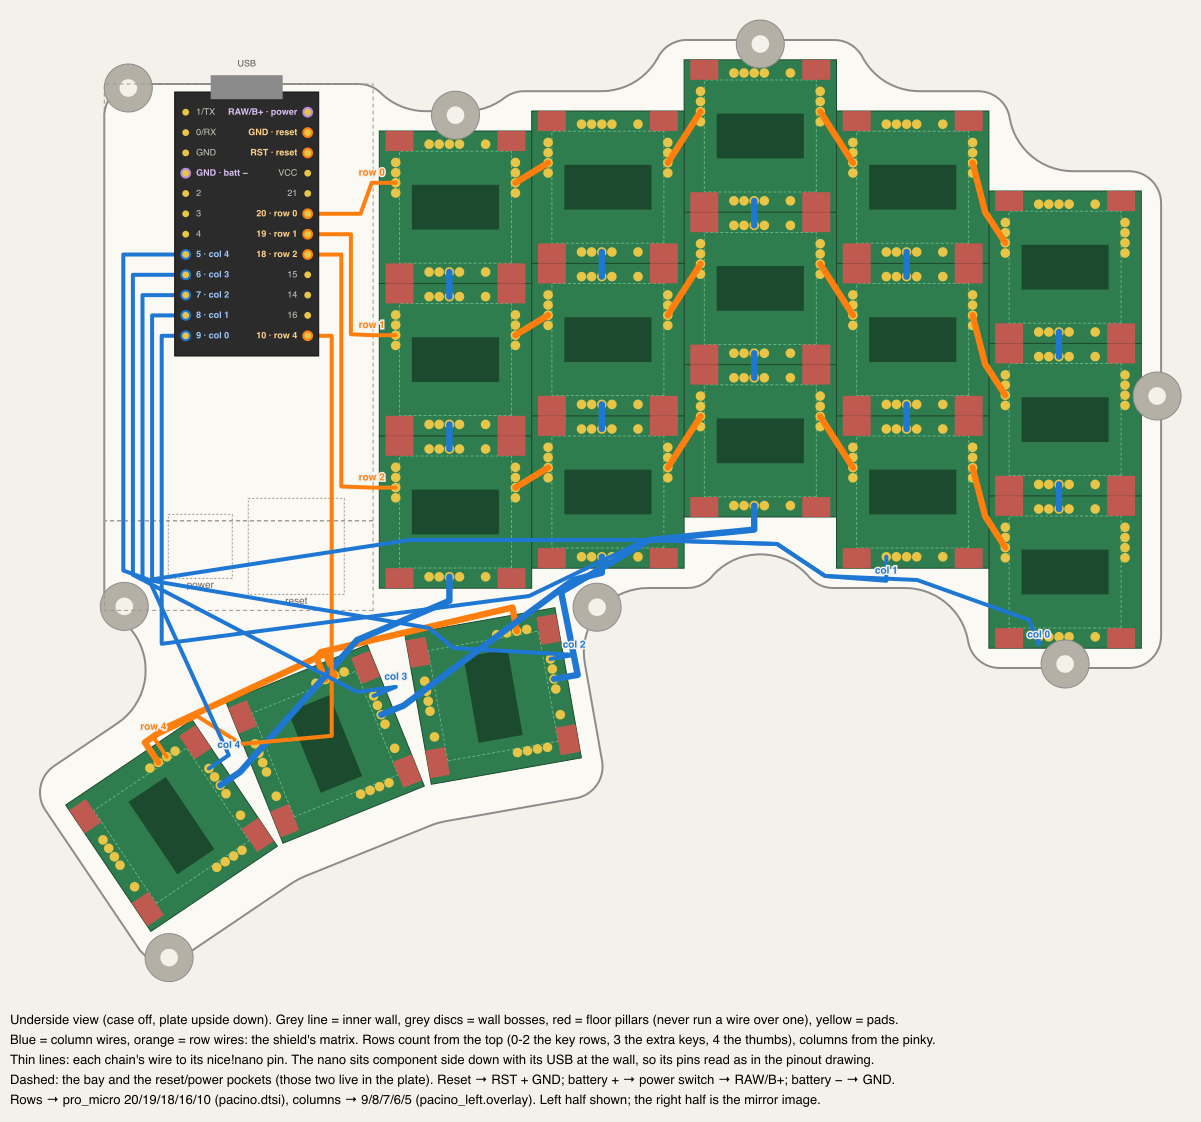
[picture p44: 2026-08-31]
variants/5col_noextra_bat902030_display/wiring_guide.png

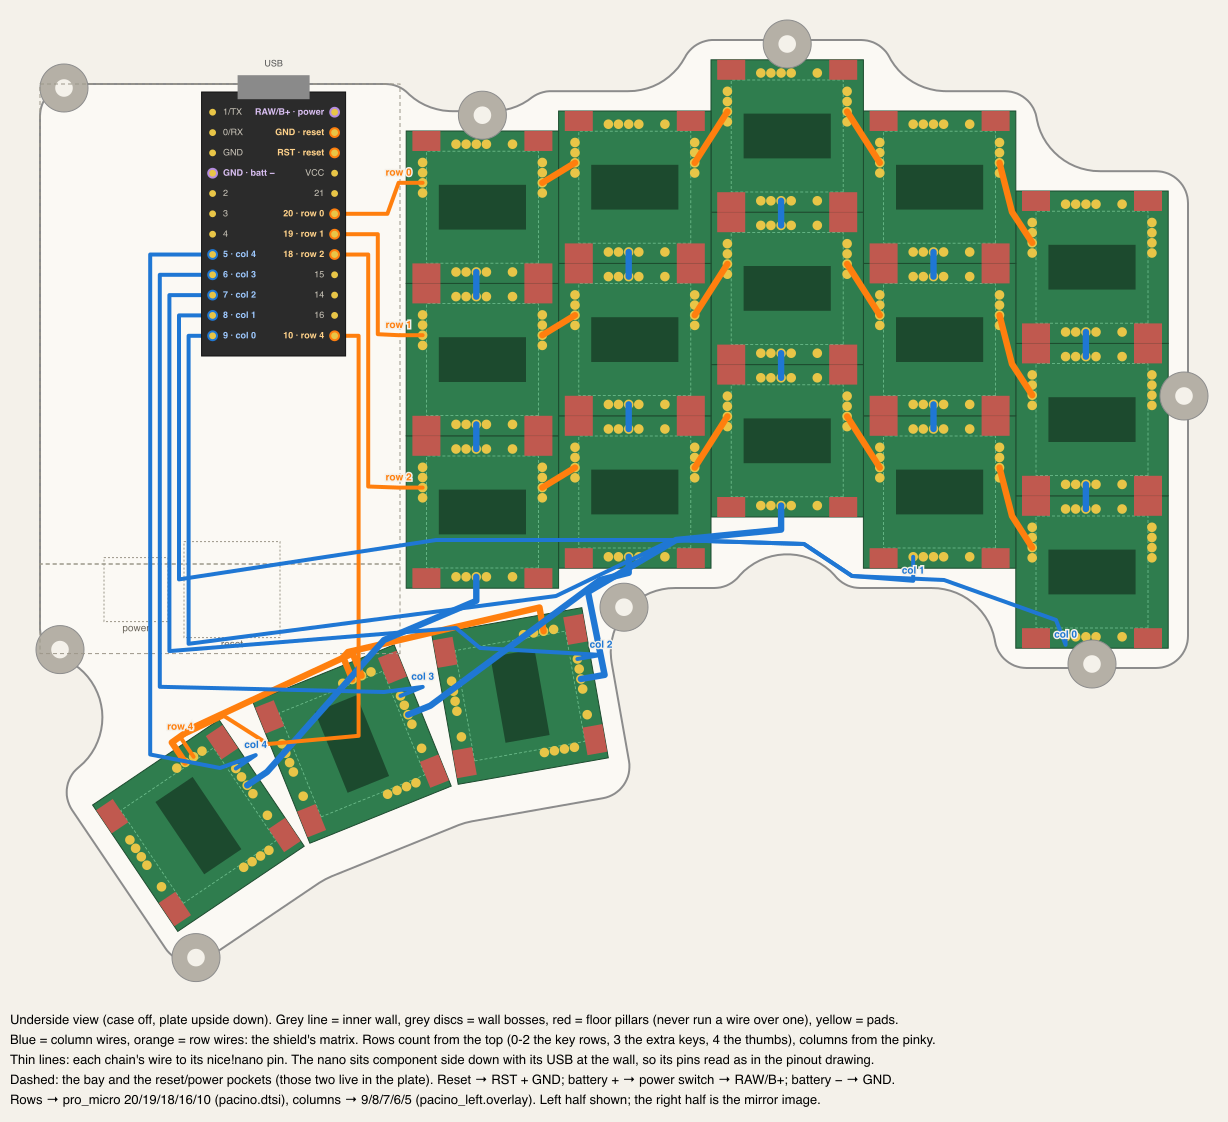
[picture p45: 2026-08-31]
variants/5col_noextra_bat103450_nodisplay/wiring_guide.png

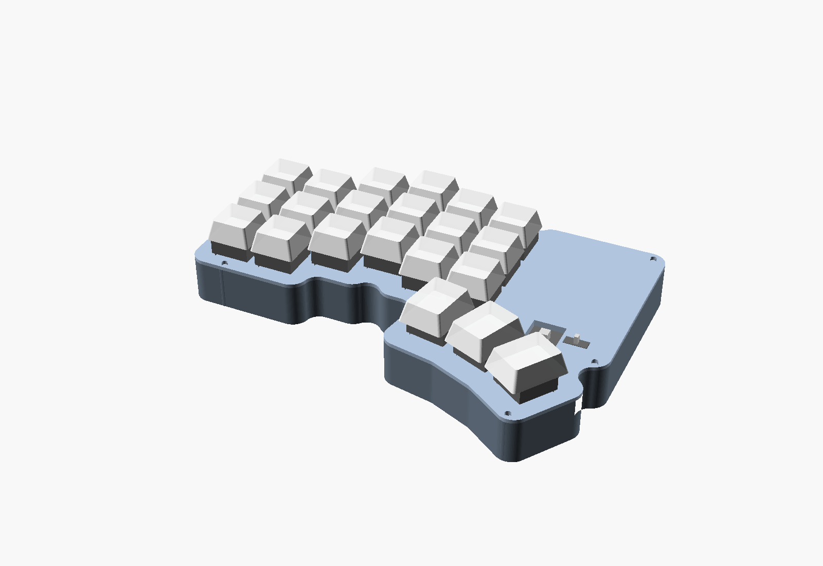
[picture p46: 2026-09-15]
variants/6col_noextra_bat103450_nodisplay/preview_assembly.png

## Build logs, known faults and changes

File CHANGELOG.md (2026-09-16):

# Changelog

What changed, for people who have already printed a case or ordered a board. Newest first. Each entry says
which parts it touches and whether an existing build is affected:

- **reprint** — the printed part changed in a way that matters (fit, hardware, a feature you'd want)
- **re-order** — the PCB changed; boards from before are different
- **reflash / rewire** — the firmware pin assignment changed
- nothing marked — docs, options that default off, or changes to parts you don't have to rebuild

The project went public on 2026-09-14. Everything before that is condensed at the bottom.

## 2026-09-16

- **The MagSafe ring is now printed in, by default.** Three test prints on the slim build settled it: the ring
  goes into a pocket at a print pause before layer 5, exposed through a window in a one-layer ledge, and holds a
  mount with nothing to stick and nothing to come off. `magsafe_style = "embedded"` with `magsafe_skin = 0` is
  the default for every variant; a 0.4 mm skin over the ring is the clean-looking option, a one-layer skin held
  better but tore along its lines, hence the ledge. The stick-on groove and the glued recess stay as options.
  Case only — **reprint** if you want the ring captive (the groove cases keep working as they are). Print
  with a pause and, if you use supports, a support blocker over the ring — every variant now also ships
  `case_*.bambu.3mf`, a Bambu Studio / Orca project with that blocker in place. All variants rebuilt.

## 2026-09-15

- **MagSafe ring: three ways to fit it.** The 1 mm recess under the index column printed on support, and
  the ring's adhesive does not hold on a support-interface surface (it holds fine on the bed-side surface —
  that's how it works on other PETG cases). `magsafe_style` now defaults to `"groove"`: no recess, the ring
  sticks straight onto the underside inside a one-layer locating groove. `"embedded"` prints the steel ring
  *into* the floor at a print pause (pocket behind 0.4 mm of floor, the model prints the pause height; set
  `magsafe_ring_id` / `magsafe_ring_t` to your ring; the pocket is exactly the ring's height so the ceiling is laid
  onto the steel rather than bridged — the first test print showed a bridged annulus sagging along the ring).
  `"recess"` is the old pocket, for gluing. Case only
  — **reprint** if your ring won't stay on, otherwise the old recess is still fine with glue. All variants
  rebuilt with the groove.
- **M3 hardware option.** `screw_size = "M3"` resizes the insert holes (4.0 mm for 4.2 mm OD inserts),
  the counterbores, the plate's clearance holes (3.4 mm) and, in the slim build, the spacer bosses, wall
  channel, wall and board holes. Default stays M2, so nothing changes unless you ask for it. An existing
  M2 board can be drilled/filed to 3.4 mm at seven of its eight holes; the README says which one can't and
  how `m2_holes` keeps it M2.

## 2026-09-14

- **Insert holes get a 0.6 mm counterbore.** Heat-set inserts push a ring of plastic up around them, and
  standing proud of the boss face it kept the plate (hand-wired) or the board (slim build) from seating
  without trimming. Every insert hole now opens into a 4.2 × 0.6 mm relief; press the insert down until it
  bottoms and the flash stays below the face. Case and the `insert_test` coupon — **reprint** the case if
  your plate or board doesn't sit flat on the bosses (or trim the flash on the case you have). All variants
  rebuilt.
- Carry case removed (the two-tray design from 2026-09-08 and its files).
- README: more photos.

## Before publication (2026-08-23 → 2026-09-12)

- **2026-09-12 — slim PCB revision 2.** Three things the first batch of boards taught: the controller sits
  on top of the board (opposite the sockets), which swaps its pin rows relative to what the generator
  assumed, so per-half pin tables, silkscreen faces and the firmware lists are computed for that; the
  reset switch footprint had the 12 mm tactile's legs paired wrong (a normally fitted switch held RST at
  GND and the nano never booted); the battery/GND jumpers moved out from under the bay's corner boss.
  **re-order** — boards from before this date have the old reset footprint and jumper placement.
- **2026-08-31 — rows rewired** to pro_micro 20/19/18/16/10 (columns unchanged on 9/8/7/6/5). **rewire /
  reflash** for hand-wired halves built from the earlier wiring guide; display builds move row 3 to pin 21.
- **2026-08-27 — slim build fixes:** screw channels up the wall over the insert holes, 3 mm wall, three
  pillars pulled in from the wall; the plate's rim cut across the whole controller window at the USB end;
  floor pillars under the board. Slim case, plate and boards.
- **2026-08-25 — the slim build:** `build = "pcb"` with a generated reversible board (KiCad 9, gerbers),
  the 902030 in a plate pod or a 303040 flat under the board, 11.5 mm to the plate top; the
  `pacino_pcb` firmware shield. MagSafe recess kept clear of the battery well.
- **2026-08-24 — controller flipped** component-side-down with cradle crush ribs, the battery sunk into a
  floor well, and the nice!view stacked over the controller.
- **2026-08-23 — first commit:** the parametric hand-wired build, ZMK config with GitHub Actions builds,
  the variant gallery.

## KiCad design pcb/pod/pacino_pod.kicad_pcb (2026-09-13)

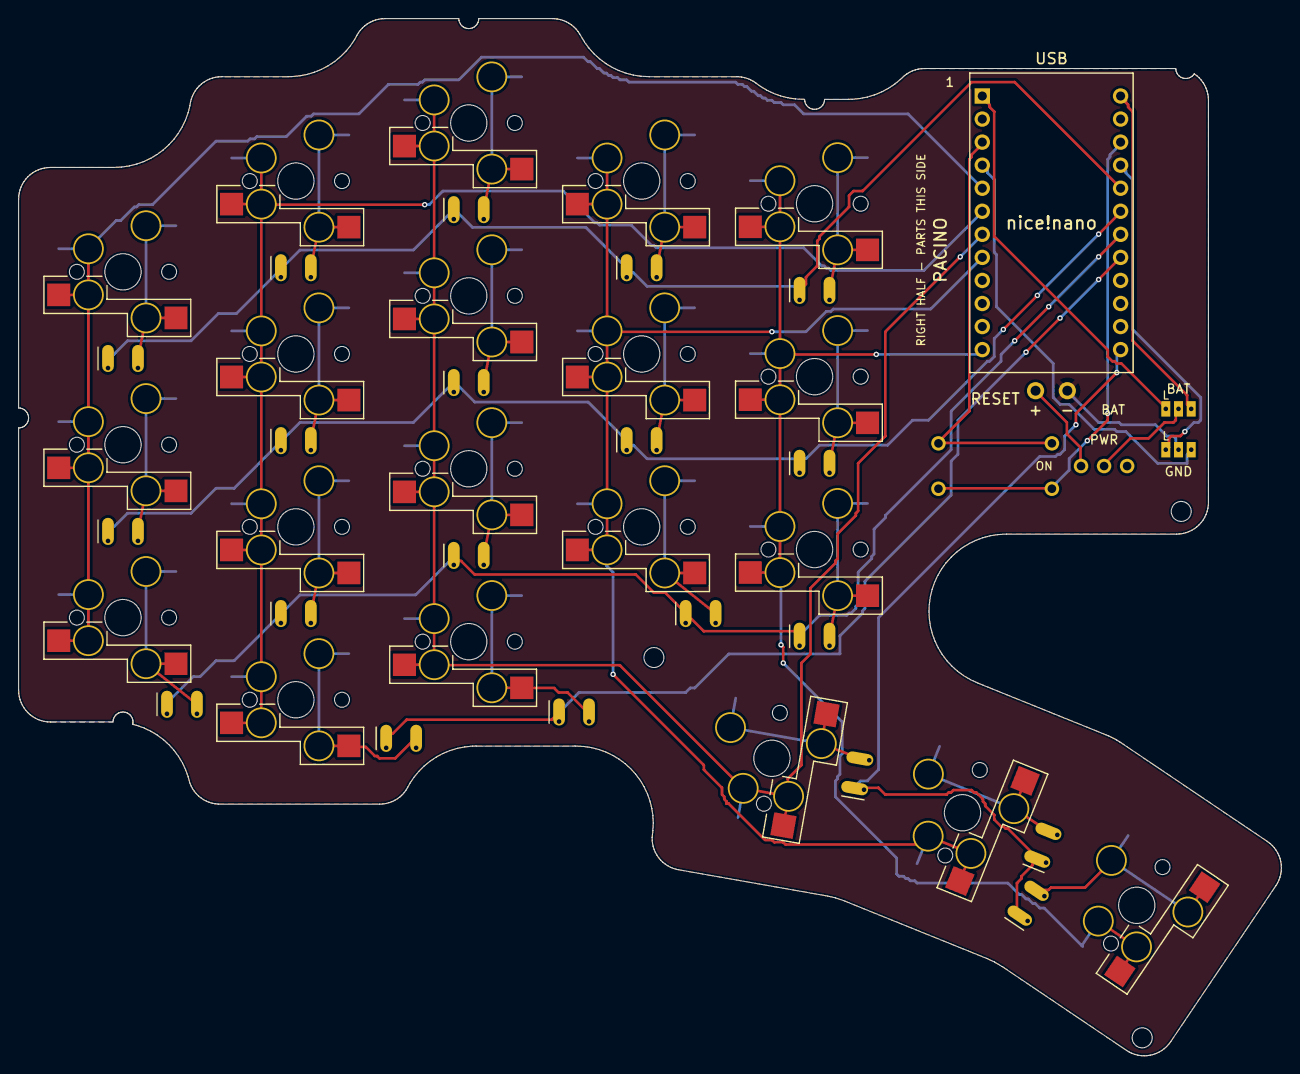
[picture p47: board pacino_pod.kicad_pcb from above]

Board: 2 copper layers, 139.1 x 114.3 mm, 49 parts (0 on the bottom side), 39 nets.

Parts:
BT1: LiPo
D1, D2, D3, D4, D5, D6, D7, D8, D9, D10, D11, D12, D13, D14, D15, D16, D17, D18, D19, D20: 1N4148W
H1, H2, H3: MountingHole
JP1: BAT_SELECT
JP2: GND_SELECT
PWR1: SS12D00
RSW1: SW_Tactile_12mm
SW1, SW2, SW3, SW4, SW5, SW6, SW7, SW8, SW9, SW10, SW11, SW12, SW13, SW14, SW15, SW16, SW17, SW18, SW19, SW20: MX_Hotswap_Rev
U1: nice!nano

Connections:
BAT_L: JP1.1, U1.1
BAT_P: BT1.1, PWR1.1
BAT_R: JP1.3, U1.24
BAT_SW: JP1.2, PWR1.2
COL0: SW1.1, SW2.1, SW3.1, U1.5
COL1: SW4.1, SW5.1, SW6.1, SW16.1, U1.6
COL2: SW7.1, SW8.1, SW9.1, SW17.1, SW18.1, U1.7
COL3: SW10.1, SW11.1, SW12.1, SW19.1, U1.8
COL4: SW13.1, SW14.1, SW15.1, SW20.1, U1.12
GND: BT1.2, JP2.2
GND_L: JP2.1, U1.21
GND_R: JP2.3, U1.4
ROW0: D3.1, D6.1, D9.1, D12.1, D15.1, U1.20
ROW1: D2.1, D5.1, D8.1, D11.1, D14.1, U1.19
ROW2: D1.1, D4.1, D7.1, D10.1, D13.1, U1.18
ROW3: D16.1, D17.1, U1.17
ROW4: D18.1, D19.1, D20.1, U1.13
RST_A: RSW1.1, U1.3
RST_B: RSW1.2, U1.22
SW1: D1.2, SW1.2
SW2: D2.2, SW2.2
SW3: D3.2, SW3.2
SW4: D4.2, SW4.2
SW5: D5.2, SW5.2
SW6: D6.2, SW6.2
SW7: D7.2, SW7.2
SW8: D8.2, SW8.2
SW9: D9.2, SW9.2
SW10: D10.2, SW10.2
SW11: D11.2, SW11.2
SW12: D12.2, SW12.2
SW13: D13.2, SW13.2
SW14: D14.2, SW14.2
SW15: D15.2, SW15.2
SW16: D16.2, SW16.2
SW17: D17.2, SW17.2
SW18: D18.2, SW18.2
SW19: D19.2, SW19.2
SW20: D20.2, SW20.2

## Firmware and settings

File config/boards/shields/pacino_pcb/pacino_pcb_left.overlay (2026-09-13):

#include "pacino_pcb.dtsi"

/*
 * Left half: sockets and diodes on the board's BACK face, controller on the FRONT (on top of the
 * board, component side down).  Seen from the front that puts the nano's RAW row on pads 13-24 and
 * its TX row on pads 1-12.  Bridge JP1 / JP2 to the pad marked L, on the face the nano sits on.
 */

&kscan0 {
    row-gpios
        = <&pro_micro 2 (GPIO_ACTIVE_HIGH | GPIO_PULL_DOWN)>    /* row 0: top    */
        , <&pro_micro 3 (GPIO_ACTIVE_HIGH | GPIO_PULL_DOWN)>    /* row 1: home   */
        , <&pro_micro 4 (GPIO_ACTIVE_HIGH | GPIO_PULL_DOWN)>    /* row 2: bottom */
        , <&pro_micro 5 (GPIO_ACTIVE_HIGH | GPIO_PULL_DOWN)>    /* row 3: extras */
        , <&pro_micro 9 (GPIO_ACTIVE_HIGH | GPIO_PULL_DOWN)>    /* row 4: thumbs */
        ;
    /* COL0 .. COL4 = pinky .. inner, the order the transform wants for the left half */
    col-gpios
        = <&pro_micro 21 GPIO_ACTIVE_HIGH>   /* col 0: pinky  (COL0) */
        , <&pro_micro 20 GPIO_ACTIVE_HIGH>   /* col 1: ring   (COL1) */
        , <&pro_micro 19 GPIO_ACTIVE_HIGH>   /* col 2: middle (COL2) */
        , <&pro_micro 18 GPIO_ACTIVE_HIGH>   /* col 3: index  (COL3) */
        , <&pro_micro 10 GPIO_ACTIVE_HIGH>   /* col 4: inner  (COL4) */
        ;
};

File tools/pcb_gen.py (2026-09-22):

#!/usr/bin/env python3
"""Generate the Pacino PCB -- the board for build = "pcb", the slim variant -- as a KiCad 9 project.

    tools/pcb_gen.py [-D ...openscad overrides...]

Everything comes from keyboard.scad: the board outline is the case cavity minus pcb_gap, the switch,
mounting-hole, controller and reset/power positions are the model's own.  Re-run it after changing the
model and the board follows.  There is no schematic: this script IS the schematic -- it declares every
net and every connection, and the nets are named the way the ZMK shield names them.

The board is REVERSIBLE: one design, flipped over for the right half.  What that costs, and how it is
paid for, is in three places --

  switches   every footprint carries both pin diagonals (the 0 deg pair and the 180 deg pair) and a
             hot-swap socket land on each face.  On the right half the switches and sockets go in
             rotated 180 deg; MX switches are square and their stems are symmetric, so nothing about
             the feel or the keycaps changes.
  matrix     flipping the board swaps the controller's two pin rows (row A <-> row B) but not the
             position along a row, so a hole that is pro_micro 2 on the left half is pro_micro 21 on
             the right.  Every matrix net therefore lands on a usable GPIO on both halves -- the ten
             holes were chosen so that both of their pins are free, and pins 1/14/15/16 (the nice!view
             SPI four) stay clear on BOTH halves.  The two ZMK overlays get different pin lists; the
             generator prints them.
  power      RAW and GND have no symmetric pair, so each gets a three-pad solder jumper: bridge the
             centre pad to L or R.  Reset needs no jumper -- it sits across the (rowA,3)/(rowB,3) pair,
             which is GND/RST one way round and RST/GND the other.
  controller sits ON TOP of the board -- the face opposite the sockets and diodes -- component side
             down, flush in the plate's window (that is what the case is built around).  Every
             per-half pin table, and which face carries the L / R mark, is computed for that.
"""
import math, os, re, subprocess, sys, heapq

# ---------------------------------------------------------------- run under KiCad's python
try:
    import pcbnew
except ImportError:                                                    # pragma: no cover
    cand = [os.environ.get("KICAD_PYTHON", "")] + [
        "/Applications/KiCad/KiCad.app/Contents/Frameworks/Python.framework/Versions/%s/bin/python3" % v
        for v in ("3.9", "3.11", "3.12", "Current")] + ["/usr/lib/kicad/bin/python3"]
    for py in cand:
        if py and os.path.exists(py):
            os.execv(py, [py, os.path.abspath(__file__)] + sys.argv[1:])
    sys.exit("pcbnew not importable and no KiCad python found -- set KICAD_PYTHON")

ROOT = os.path.dirname(os.path.dirname(os.path.abspath(__file__)))

# The two slim builds differ in where the cell lives, and that moves the bay, two mounting holes and
# the reset/power positions -- so they are two boards, not one board with an option.
VARIANTS = {
    "flat": dict(key="flat", name="pacino_flat", case="5col_extra2_bat303040_pcb_flat",
                 scad=["-D", "battery_pod=false", "-D", 'battery_type="custom"',
                       "-D", "battery_custom=[30,40,3]"],
                 cell="303040 (3 x 30 x 40, ~320 mAh)",
                 where="in a well in the case floor, entirely under the board -- the plate is flat",
                 leads="Battery leads to `BAT +` / `-`; the cell lies in the floor well beneath them."),
    "pod":  dict(key="pod", name="pacino_pod", case="5col_extra2_bat902030_pcb_pod",
                 scad=["-D", "battery_pod=true"],
                 cell="902030 (9.5 x 20 x 30, 500 mAh)",
                 where="in a pod moulded into the plate, directly over the controller",
                 leads="Battery leads to `BAT +` / `-`; they drop through the plate's controller "
                       "window from the pod above."),
}
OPENSCAD = os.environ.get("OPENSCAD") or "/Applications/OpenSCAD.app/Contents/MacOS/OpenSCAD"
if not os.path.exists(OPENSCAD):
    from shutil import which; OPENSCAD = which("openscad") or OPENSCAD
RENDER = "--no-render" not in sys.argv[1:]
ARGV = [a for a in sys.argv[1:] if not a.startswith("--variant") and a != "--no-render"]
WANT = [a.split("=", 1)[1] for a in sys.argv[1:] if a.startswith("--variant=")] or list(VARIANTS)
SCAD_ARGS = []          # set per variant in main()
LIBNAME = "pacino"      # ditto -- the footprint library this board's parts resolve to

KX0, KY0 = 60.0, 120.0            # model origin -> KiCad coordinates (KiCad y is down)
def K(p):  return (KX0 + p[0], KY0 - p[1])

# ---------------------------------------------------------------- geometry from the model
def scad(part, out, extra=()):
    return subprocess.run([OPENSCAD, "--backend=Manifold", "-q", "-D", 'part="%s"' % part,
                           "-D", 'build="pcb"', *SCAD_ARGS, *extra, "-o", out, "keyboard.scad"],
                          cwd=ROOT, capture_output=True, text=True)

def model_info():
    r = subprocess.run([OPENSCAD, "-D", 'part="info"', "-D", 'build="pcb"', *SCAD_ARGS,
                        "-o", "/tmp/_pacino_info.stl", "keyboard.scad"],
                       cwd=ROOT, capture_output=True, text=True)
    info = "".join(l[6:] for l in r.stderr.splitlines() if l.startswith("ECHO: "))
    def arr(name):
        m = re.search(name + r' = (\[.*?\])(?=, [a-z_]+ =|$)', info)
        if not m: sys.exit("could not read %s from the model:\n%s" % (name, info[:400]))
        return eval(m.group(1))
    return {k: arr(k) for k in ("keys", "holes", "mcu", "reset", "power", "stack", "bay", "ctrl", "pcb_posts")}

def dxf_polylines(path):
    L = open(path).read().split("\n"); out = []; i = 0
    while i < len(L) - 1:
        if L[i].strip() == "0" and L[i + 1].strip() == "LWPOLYLINE":
            pts = []; j = i + 2; x = None
            while j < len(L) - 1 and L[j].strip() != "0":
                c, v = L[j].strip(), L[j + 1].strip()
                if c == "10": x = float(v)
                elif c == "20": pts.append((x, float(v)))
                j += 2
            out.append(pts); i = j
        else: i += 2
    return out

def area(poly):
    return sum(poly[i][0] * poly[(i + 1) % len(poly)][1] - poly[(i + 1) % len(poly)][0] * poly[i][1]
               for i in range(len(poly))) / 2

def rdp(pts, eps):
    if len(pts) < 3: return pts
    ax, ay = pts[0]; bx, by = pts[-1]
    dx, dy = bx - ax, by - ay; n = math.hypot(dx, dy)
    worst, wi = -1, 0
    for i in range(1, len(pts) - 1):
        px, py = pts[i]
        d = abs(dx * (ay - py) - (ax - px) * dy) / n if n else math.hypot(px - ax, py - ay)
        if d > worst: worst, wi = d, i
    if worst <= eps: return [pts[0], pts[-1]]
    return rdp(pts[:wi + 1], eps)[:-1] + rdp(pts[wi:], eps)

def board_outline():
    dxf = "/tmp/_pacino_edge.dxf"
    r = scad("pcb_outline_2d", dxf)
    if r.returncode: sys.exit("openscad failed:\n" + r.stderr[-2000:])
    loops = dxf_polylines(dxf)
    loops.sort(key=lambda p: -abs(area(p)))
    outer = [K(p) for p in loops[0]]
    holes = [[K(p) for p in l] for l in loops[1:] if abs(area(l)) > 1.0]
    sys.setrecursionlimit(10000)
    outer = rdp(outer + [outer[0]], 0.008)[:-1]
    return outer, holes

# ---------------------------------------------------------------- pcbnew helpers
mm  = pcbnew.FromMM
def V(x, y): return pcbnew.VECTOR2I(mm(x), mm(y))
def lset(*layers):
    s = pcbnew.LSET()
    for l in layers: s.addLayer(l)
    return s
CU  = {"F": pcbnew.F_Cu, "B": pcbnew.B_Cu}
SILK= {"F": pcbnew.F_SilkS, "B": pcbnew.B_SilkS}
MASK= {"F": pcbnew.F_Mask, "B": pcbnew.B_Mask}
PASTE={"F": pcbnew.F_Paste, "B": pcbnew.B_Paste}

OBST = []     # (layers set of "F"/"B"/"*", shape, net) -- the router's view of the copper
def obst(layers, shape, net): OBST.append((layers, shape, net))

class Gen:
    def __init__(self):
        self.b = pcbnew.CreateEmptyBoard()
        self.nets = {}
        ds = self.b.GetDesignSettings()
        ds.m_TrackMinWidth = mm(0.2); ds.m_MinClearance = mm(0.2)
        ds.m_ViasMinSize = mm(0.5); ds.m_MinThroughDrill = mm(0.3)
        ds.m_HoleToHoleMin = mm(0.25); ds.m_CopperEdgeClearance = mm(0.25)
        ds.m_SolderMaskExpansion = mm(0.05); ds.m_SolderMaskMinWidth = mm(0.2)
        self.tracks = 0; self.vias = 0
        self.pads = []          # (net, layers, x, y)
        self.parent = {}        # union-find over pad positions, per net

    def net(self, name):
        if name not in self.nets:
            n = pcbnew.NETINFO_ITEM(self.b, name); self.b.Add(n); self.nets[name] = n
        return self.nets[name]

    # -------- primitives
    def track(self, a, b, layer, net):
        t = pcbnew.PCB_TRACK(self.b)
        t.SetStart(V(*a)); t.SetEnd(V(*b)); t.SetWidth(mm(0.3))
        t.SetLayer(CU[layer]); t.SetNet(self.net(net)); self.b.Add(t)
        obst(layer, ("seg", a[0], a[1], b[0], b[1], 0.15), net)
        self.tracks += 1

    def via(self, p, net):
        v = pcbnew.PCB_VIA(self.b)
        v.SetPosition(V(*p)); v.SetFrontWidth(mm(0.6)); v.SetDrill(mm(0.3))
        v.SetViaType(pcbnew.VIATYPE_THROUGH); v.SetLayerPair(pcbnew.F_Cu, pcbnew.B_Cu)
        v.SetNet(self.net(net)); self.b.Add(v)
        obst("*", ("circ", p[0], p[1], 0.3), net); self.vias += 1

    def edge(self, a, b, layer=None, width=0.1, parent=None):
        s = pcbnew.PCB_SHAPE(parent or self.b); s.SetShape(pcbnew.SHAPE_T_SEGMENT)
        s.SetStart(a if isinstance(a, pcbnew.VECTOR2I) else V(*a))
        s.SetEnd(b if isinstance(b, pcbnew.VECTOR2I) else V(*b))
        s.SetLayer(layer or pcbnew.Edge_Cuts)
        s.SetWidth(mm(width))
        (parent or self.b).Add(s)

    def text(self, p, txt, layer, size=1.0, rot=0, mirror=False):
        t = pcbnew.PCB_TEXT(self.b); t.SetText(txt); t.SetPosition(V(*p)); t.SetLayer(layer)
        t.SetTextSize(V(max(size, 0.85), max(size, 0.85)))
        t.SetTextThickness(mm(max(size, 0.85) * 0.16))
        t.SetMirrored(mirror); t.SetTextAngle(pcbnew.EDA_ANGLE(rot, pcbnew.DEGREES_T))
        t.SetHorizJustify(pcbnew.GR_TEXT_H_ALIGN_CENTER); self.b.Add(t)

    # -------- footprints
    def fp(self, ref, value, at, rot, pads, courtyard=None, silk=(), fab=()):
        f = pcbnew.FOOTPRINT(self.b); self.b.Add(f)
        f.SetFPID(pcbnew.LIB_ID(LIBNAME, value))
        f.SetReference(ref); f.SetValue(value)
        f.SetPosition(V(*at))
        f.Reference().SetLayer(pcbnew.F_Fab); f.Reference().SetTextSize(V(0.8, 0.8))
        f.Value().SetLayer(pcbnew.F_Fab); f.Value().SetTextSize(V(0.8, 0.8)); f.Value().SetVisible(False)
        f.Reference().SetPosition(V(at[0], at[1] - 0.5))
        ca, sa = math.cos(math.radians(rot)), math.sin(math.radians(rot))
        def world(x, y): return (at[0] + ca * x - sa * -y, at[1] + (-sa) * x + ca * y)
        for p in pads:
            self._pad(f, p, world, rot)
        # graphics go on as footprint children in the unrotated frame; the orientation at the end
        # turns pads and shapes together
        # sum in nanometres, not millimetres: FromMM(a + b) and FromMM(a) + FromMM(b) differ by a
        # nanometre, which is enough for KiCad to call every instance different from the library's
        def L(x, y): return pcbnew.VECTOR2I(mm(at[0]) + mm(x), mm(at[1]) + mm(y))
        if courtyard:
            x0, y0, x1, y1 = courtyard
            pts = [L(x0, y0), L(x1, y0), L(x1, y1), L(x0, y1)]
            for lay in (pcbnew.F_CrtYd, pcbnew.B_CrtYd):
                for i in range(4):
                    self.edge(pts[i], pts[(i + 1) % 4], lay, 0.05, f)
        for (a, bb, la) in silk:
            self.edge(L(*a), L(*bb), SILK[la], 0.15, f)
        for (a, bb) in fab:
            self.edge(L(*a), L(*bb), pcbnew.F_Fab, 0.1, f)
        # orientation LAST: FOOTPRINT::SetOrientation rotates the pads it already owns, shapes and
        # offsets included.  Rotating first and adding pads after leaves every pad shape unrotated.
        f.SetOrientationDegrees(rot)
        return f

    def _pad(self, f, p, world, rot):
        num, kind, x, y, w, h, drill, shape, net = (
            p["n"], p["k"], p["x"], p["y"], p.get("w", 1.0), p.get("h", 1.0),
            p.get("d", 0), p.get("s", "circle"), p.get("net"))
        pad = pcbnew.PAD(f)
        pad.SetNumber(str(num))
        pad.SetShape({"circle": pcbnew.PAD_SHAPE_CIRCLE, "rect": pcbnew.PAD_SHAPE_RECT,
                      "oval": pcbnew.PAD_SHAPE_OVAL, "roundrect": pcbnew.PAD_SHAPE_ROUNDRECT}[shape])
        pad.SetSize(V(w, h))
        if kind in ("F", "B"):
            pad.SetAttribute(pcbnew.PAD_ATTRIB_SMD)
            pad.SetLayerSet(lset(CU[kind], MASK[kind], PASTE[kind]))
            layers = kind
        elif kind == "PTH":
            pad.SetAttribute(pcbnew.PAD_ATTRIB_PTH)
            pad.SetLayerSet(lset(pcbnew.F_Cu, pcbnew.B_Cu, pcbnew.F_Mask, pcbnew.B_Mask))
            pad.SetDrillSize(V(drill, drill)); layers = "*"
        else:
            pad.SetAttribute(pcbnew.PAD_ATTRIB_NPTH)
            pad.SetLayerSet(lset(pcbnew.F_Cu, pcbnew.B_Cu, pcbnew.F_Mask, pcbnew.B_Mask))
            pad.SetDrillSize(V(drill, drill)); layers = "*"; net = None
        f.Add(pad)
        pad.SetFPRelativePosition(V(x, y))
        # NB: a pad's position is its HOLE; "off" moves the copper away from it, which is how the
        # diode lands can take an SMD part without the barrel wicking solder out of the joint.
        if "off" in p: pad.SetOffset(V(*p["off"]))
        if net: pad.SetNet(self.net(net))
        off = p.get("off", (0, 0))
        if kind != "NPTH" and net:
            self.pads.append((net, layers) + world(x + off[0], y + off[1]))
        if kind == "NPTH":
            hx, hy = world(x, y)
            obst("*", ("circ", hx, hy, drill / 2), None)
        else:
            wx, wy = world(x + off[0], y + off[1])
            if shape == "circle":
                obst(layers, ("circ", wx, wy, w / 2), net)
            else:
                obst(layers, ("rect", wx, wy, w, h, rot), net)
            if off != (0, 0):                                # the hole sits away from the copper
                hx, hy = world(x, y)
                obst("*", ("circ", hx, hy, drill / 2), net)
        return pad

# ---------------------------------------------------------------- footprints
def mx_pads(col, sw):
    """Reversible MX + Kailh hot-swap.  Both pin diagonals, a socket land on each face.

    The 0 deg pins are (-3.81,-2.54)/(2.54,-5.08); the 180 deg pins are their negatives.  Grouping
    them as "the two at |y|=2.54 are the column pin, the two at |y|=5.08 go to the diode" means a
    switch bridges column-to-diode whichever way round it goes in.  Mirroring about a diagonal (the
    naive reversible footprint) would put two 3 mm holes 2.84 mm apart and they would merge."""
    return [
        {"n": "", "k": "NPTH", "x": 0,      "y": 0,     "w": 4.0, "h": 4.0, "d": 4.0},
        {"n": "", "k": "NPTH", "x": -5.08,  "y": 0,     "w": 1.65, "h": 1.65, "d": 1.65},
        {"n": "", "k": "NPTH", "x": 5.08,   "y": 0,     "w": 1.65, "h": 1.65, "d": 1.65},
        {"n": 1, "k": "PTH", "x": -3.81, "y": -2.54, "w": 3.4, "h": 3.4, "d": 3.0, "net": col},
        {"n": 1, "k": "PTH", "x": -3.81, "y":  2.54, "w": 3.4, "h": 3.4, "d": 3.0, "net": col},
        {"n": 2, "k": "PTH", "x":  2.54, "y": -5.08, "w": 3.4, "h": 3.4, "d": 3.0, "net": sw},
        {"n": 2, "k": "PTH", "x":  2.54, "y":  5.08, "w": 3.4, "h": 3.4, "d": 3.0, "net": sw},
        {"n": 1, "k": "B", "x": -7.085, "y": -2.54, "w": 2.55, "h": 2.5, "s": "rect", "net": col},
        {"n": 2, "k": "B", "x":  5.842, "y": -5.08, "w": 2.55, "h": 2.5, "s": "rect", "net": sw},
        {"n": 1, "k": "F", "x": -7.085, "y":  2.54, "w": 2.55, "h": 2.5, "s": "rect", "net": col},
        {"n": 2, "k": "F", "x":  5.842, "y":  5.08, "w": 2.55, "h": 2.5, "s": "rect", "net": sw},
    ]
MX_CRT = (-8.8, -6.7, 7.8, 6.7)

# The socket outline the silkscreen shows: the envelope of the Kailh socket's two contact ends and the
# bridge between them, taken from the land geometry above rather than a datasheet drawing -- so it is
# what you see looking at the socket from the face it solders to, at the size its lands imply.  Drawn
# on both faces (the left half's sockets go on the back, the right half's on the front, rotated 180),
# which also makes that rotation obvious without reading the silk.
SOCKET_B = [(-8.71, -4.59), (0.49, -4.59), (0.49, -7.13), (7.47, -7.13),
            (7.47, -3.03), (-1.76, -3.03), (-1.76, -0.49), (-8.71, -0.49)]
SOCKET_F = [(x, -y) for x, y in SOCKET_B]

def switch_mask(face):
    """every mask opening the switch footprint makes on that face -- what its silk has to dodge"""
    o = [("c", 0, 0, 2.0), ("c", -5.08, 0, 0.825), ("c", 5.08, 0, 0.825),
         ("c", -3.81, -2.54, 1.7), ("c", -3.81, 2.54, 1.7),
         ("c", 2.54, -5.08, 1.7), ("c", 2.54, 5.08, 1.7)]
    sy = -1 if face == "B" else 1
    return o + [("r", -7.085, sy * 2.54, 2.55, 2.5), ("r", 5.842, sy * 5.08, 2.55, 2.5)]

def clear_of(p, obs, gap):
    for o in obs:
        if o[0] == "c":
            if math.hypot(p[0] - o[1], p[1] - o[2]) < o[3] + gap: return False
        else:
            dx = max(abs(p[0] - o[1]) - o[3] / 2, 0); dy = max(abs(p[1] - o[2]) - o[4] / 2, 0)
            if math.hypot(dx, dy) < gap: return False
    return True

def clip_silk(poly, obs, gap=0.3, step=0.08, minlen=0.6):
    """walk the outline and keep only the stretches that clear every opening -- the outline comes out
    broken where the pads interrupt it, which is what a hand-drawn socket outline looks like too"""
    out, pts = [], poly + [poly[0]]
    for a, b in zip(pts, pts[1:]):
        n = max(2, int(math.hypot(b[0] - a[0], b[1] - a[1]) / step) + 1)
        run = []
        for i in range(n + 1):
            t = i / n
            p = (a[0] + (b[0] - a[0]) * t, a[1] + (b[1] - a[1]) * t)
            if clear_of(p, obs, gap):
                run.append(p)
            else:
                if len(run) > 1 and math.hypot(run[-1][0] - run[0][0], run[-1][1] - run[0][1]) >= minlen:
                    out.append((run[0], run[-1]))
                run = []
        if len(run) > 1 and math.hypot(run[-1][0] - run[0][0], run[-1][1] - run[0][1]) >= minlen:
            out.append((run[0], run[-1]))
    return out

SOCKET_SILK = ([(a, b, "B") for a, b in clip_silk(SOCKET_B, switch_mask("B"))] +
               [(a, b, "F") for a, b in clip_silk(SOCKET_F, switch_mask("F"))])
MX_FAB = [((-7, -7), (7, -7)), ((7, -7), (7, 7)), ((7, 7), (-7, 7)), ((-7, 7), (-7, -7))]

def diode_pads(row, sw):
    """SOD-123 land on both faces at once: one plated pad per end, copper offset off the hole so an
    SMD diode solders to either face and the barrel ties them.  A THT 1N4148 on 3.3 mm pitch fits too."""
    return [
        {"n": 1, "k": "PTH", "x": -1.65, "y": 1.8, "w": 1.3, "h": 3.0, "d": 0.5, "s": "oval",
         "off": (0, -1.05), "net": row},
        {"n": 2, "k": "PTH", "x":  1.65, "y": 1.8, "w": 1.3, "h": 3.0, "d": 0.5, "s": "oval",
         "off": (0, -1.05), "net": sw},
    ]
D_CRT = (-3.0, -1.2, 2.6, 2.6)
POST_CRT = (-2.0, -2.0, 2.0, 2.0)   # a 3 mm floor pillar of the case stands under the board here, + 0.5 all round

MCU_PIN = {}      # pad number -> (x, y) in footprint coords
for i in range(1, 13):
    MCU_PIN[i] = (-7.62, -13.97 + (i - 1) * 2.54)
    MCU_PIN[25 - i] = (7.62, -13.97 + (i - 1) * 2.54)
# pro_micro pin names, row A (pads 1..12) then row B (pads 13..24), for the silk and the report
PRO_MICRO = {1: "1/TX", 2: "0/RX", 3: "GND", 4: "GND", 5: "2", 6: "3", 7: "4", 8: "5", 9: "6",
             10: "7", 11: "8", 12: "9", 13: "10", 14: "16", 15: "14", 16: "15", 17: "18", 18: "19",
             19: "20", 20: "21", 21: "VCC", 22: "RST", 23: "GND", 24: "RAW"}
# the ten matrix holes: both of each hole's two pins (left build / right build) must be a free GPIO,
# and neither may be 1/14/15/16 -- those four are the nice!view's CS/MISO/SCK/MOSI and stay free on
# BOTH halves.  That leaves exactly k = 5,6,7,8,12 on each row: ten holes for ten matrix nets.
MCU_MATRIX = {5: "COL0", 6: "COL1", 7: "COL2", 8: "COL3", 12: "COL4",
              20: "ROW0", 19: "ROW1", 18: "ROW2", 17: "ROW3", 13: "ROW4"}
# The controller sits on the face opposite the parts.  Left half: parts on B, nano on F, component
# side towards the board -- seen from F that is the plain pinout, RAW on pad 1 and GND on pad 4.
# Right half: parts on F, nano on B -- rows swapped, RAW on pad 24 and GND on pad 21.
MCU_POWER  = {3: "RST_A", 22: "RST_B", 1: "BAT_L", 24: "BAT_R", 21: "GND_L", 4: "GND_R"}

def mcu_pads(w, l):
    pads = []
    for n, (x, y) in sorted(MCU_PIN.items()):
        net = MCU_MATRIX.get(n) or MCU_POWER.get(n)
        pads.append({"n": n, "k": "PTH", "x": x, "y": y, "w": 1.7, "h": 1.7, "d": 1.0,
                     "s": "rect" if n == 1 else "circle", "net": net})
    return pads

def jumper_pads(l_net, common, r_net):
    return [{"n": 1, "k": "PTH", "x": -1.4, "y": 0, "w": 1.0, "h": 1.7, "d": 0.5, "s": "rect", "net": l_net},
            {"n": 2, "k": "PTH", "x":  0.0, "y": 0, "w": 1.0, "h": 1.7, "d": 0.5, "s": "rect", "net": common},
            {"n": 3, "k": "PTH", "x":  1.4, "y": 0, "w": 1.0, "h": 1.7, "d": 0.5, "s": "rect", "net": r_net}]
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

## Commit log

2026-08-23 Pacino: parametric hand-wired wireless split keyboard
    Cheapino-derived 3x5(+2)+3 column-stagger layout on a 19.05 mm MX grid with
    1.25u portrait thumbs, hand-wired with Amoeba-King hot-swap PCBs, SuperMini
    nRF52840, 902030/103450 LiPo, reset + power switches, optional nice!view and
    sixth column. OpenSCAD model with a FreeCAD pipeline producing STEP for
    Fusion 360; variants/ holds every option combination as STEP + 3MF with
    per-variant wiring guides.
    Claude-Session: https://claude.ai/code/session_01BC8SMH5i2ZF6J7YagrN8cV
    [badtemper.scad, bezel_left.3mf, bezel_left.step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]
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2026-08-23 Thin PCB variant: revived build=pcb mode, KiCad bootstrap, variant output
    Auto pcb_lift (battery through a board cutout), pcb_outline_2d part,
    tools/kicad_placement.py emitting Edge.Cuts DXF + placement CSV, and
    variants/5col_extra2_bat902030_pcb (14 mm tall with the 902030).
    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
    [case_left.3mf, case_left.step, case_right.3mf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]
2026-08-23 PCB variant: battery well in the floor (12.7 mm tall with the 902030)
    Sinking the cell 1.3 mm into the floor is what actually saves height --
    moving it beside the board does not, since the board already has a cutout
    there. Well walls replace the fence; bay bumpons skipped when the well is on.
    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
    [case_left.3mf, case_left.step, case_right.3mf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]
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2026-08-23 PCB variant: plate windows for PCB-mounted reset/power, CSV positions
    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
    [case_left.3mf, case_left.step, case_right.3mf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]
2026-08-24 Flip the MCU component-side-down, add cradle crush ribs, stack the nice!view
    Three changes to the electronics bay, and a rebuild of all 17 variants.
    MCU flipped (mcu_flipped, default on). The nano goes in upside down, so its
    components and USB connector face into the case and its wires poke straight
    down through the pads into the bay. The plate above it becomes solid -- no
    opening over the MCU -- and the side wire channels are gone, since nothing
    needs to run along the board edges any more. USB exits through an open-top
    notch in the wall that the plate bridges; a closed window would leave a
    sub-millimetre sliver under the wall top that prints badly. The board sits
    2.8 mm above the battery f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
    [bezel_left.3mf, bezel_left.step, bezel_right.3mf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]
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2026-08-25 Model: slim PCB build with the cell in a plate pod or a floor well, bay bumpons that clear the well
    - build = "pcb": battery_pod carries a 902030 in a pod moulded into the plate over the socketed
    controller, using the 3.5 mm the MX plate-to-PCB gap gives for free -- 11.5 mm to the plate top,
    the MX floor. battery_pod = false with a cell <= 3.4 mm thick (a 303040) lies in the floor well
    entirely under the board instead: same 11.5 mm, nothing on top. The board is solid in both.
    - Warn when a cell would poke through the board under the controller (the pin rows would have no
    board), and when the controller sockets are shorter than its USB shell needs (3.5 mm minimum).
    - With a battery we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
    [keyboard.scad]
2026-08-25 PCB: generate the slim build's boards from the model (KiCad 9, DRC-clean, gerbers)
    tools/pcb_gen.py is the schematic: it declares every net, places switches, diodes, controller,
    reset/power and jumpers from keyboard.scad's own positions, routes the board on a two-layer maze
    router, pours ground, exports a footprint library and gerbers, and writes each board's README with
    the pin tables, assembly steps and BOM. One reversible board per slim build (pcb/flat, pcb/pod):
    both MX pin diagonals and a hot-swap land per face, matrix holes chosen so both of each hole's pins
    are free GPIOs on either half with 1/14/15/16 kept for the nice!view, RAW/GND on L/R solder
    jumpers, reset across the GND/RST pai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
    [pacino_edge_cuts.dxf, pacino_flat.kicad_pcb, pacino_placement.csv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]
2026-08-25 Firmware: pacino_pcb shield for the reversible board
    Flipping the board swaps the controller's pin rows, so the matrix lands on different GPIOs on each
    half; the two overlays carry the two pin lists (printed by tools/pcb_gen.py). Same layout, matrix
    and keymap as the hand-wired pacino shield, which is unchanged. Both are in the build matrix.
    Claude-Session: https://claude.ai/code/session_0124aPbnT3qkacCPcrQBUQo5
    [pacino_pcb_left.overlay]
2026-08-25 Docs and variants: the slim build, its two boards, and every variant rebuilt with eight feet
    README: the slim build section (flat and pod, the 11.5 mm stack, the reversible board), renders of
    the board and the exploded and sectioned stack, the bumpon rule, the pacino_pcb shield. All 18
    variants regenerated: the two slim ones replace 5col_extra2_bat902030_pcb, and every well build
    now has eight full-size feet.
    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
    [bezel_left.3mf, bezel_left.step, bezel_right.3mf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]
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2026-08-25 PCB: outline every hot-swap socket on the silkscreen
    Derived from the socket's own land geometry and clipped against the switch footprint's mask
    openings, so it breaks around the pads the way a hand-drawn outline does rather than tripping
    silk-over-copper. Drawn on both faces: the left half's sockets go on the back, the right half's on
    the front rotated 180, and the two sets of outlines show that difference on the board.
    Also fixes footprint graphics being placed with FromMM(a + b) instead of FromMM(a) + FromMM(b),
    a nanometre off, which made every switch "not match" its library copy once they carried silk.
    Claude-Session: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
    [pacino_flat.kicad_pcb, pacino_pod.kicad_pcb]
2026-08-25 PCB: render each board as part of generating it
    tools/pcb_gen.py now writes top, bottom and isometric renders beside each board, from the same file
    the fab gets, so the pictures in the README and in each board's own README are always the board in
    the repo. --no-render skips the raytracing (about 45 s for the pair) while iterating. Replaces the
    two hand-made images under docs/pcb/, which were the one thing here that could quietly go stale.
    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
    [pacino_flat.kicad_pcb, pacino_pod.kicad_pcb]
2026-08-25 Plate ribs: take their depth from the main board on a PCB build, not from key_pcbs
    The ribs hang from the plate's underside to just short of whatever is beneath them. On build = "pcb"
    that is the main board, but the depth was derived from key_pcbs -- a hand-wired setting about the
    per-key boards. It gave the right 3.2 mm by coincidence; turning key_pcbs off, which is the sensible
    thing to do when there are no per-key boards, stood the ribs straight on the PCB. key_pcbs now has
    no effect on a PCB build at all. Also documents why the board's mounting holes are edge notches.
    Claude-Session: https://claude.ai/code/session_01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
    [case_left.3mf, case_left.step, case_right.3mf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]
2026-08-26 MagSafe recess: keep it clear of the battery well
    The ring recess (1 mm into the underside, centred at [60, 28]) reached x = 88.3, and the battery well's key-side edge sits on the bay line at x = 86.5 (1.3 mm into the top of the floor): the two cut 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
    [case_left.3mf, case_left.step, case_right.3mf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]
2026-08-27 Slim build: clip the plate's spacer bosses to the cavity so they stand on the board, not the wall
    In the PCB build the case bosses stop at the board and the plate carries 5 mm spacer bosses down to it. Every mounting hole sits 0.5 mm inside the wall line, so each full cylinder reached 2 mm into t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
    [keyboard.scad, plate_left.3mf, plate_left.step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]
2026-08-27 Slim build: run the controller's plate window to the wall line at the USB end
    The plate's windows were clipped 1.4 mm inside the wall line to protect the rim and lip, but the controller's USB end sits 1 mm from the wall: the rim covered the board's last 0.4 mm and the 1 mm lip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
    [keyboard.scad, plate_left.3mf, plate_left.step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]
2026-08-27 Slim build: floor pillars under the board, insert holes that keep some floor
    Two 3 mm floor pillars (pcb_posts) stand under the main board between the mounting bosses, in the column gaps clear of what hangs under the board -- each key's hot-swap socket, switch post and pins, and the diode 8.8 mm below it -- so a 55 mm span of board no longer hangs on its corners. The model warns if a pillar is moved into one of those zones and exports them in the info echo; tools/pcb_gen.py takes them as diode keep-outs (the two existing boards' diodes are all >= 9 mm away, so the boards are unchanged). The boss insert hole is capped at 0.9 mm above the case bottom: in the PCB build the bosses stop at the bo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
    [case_left.3mf, case_left.step, case_right.3mf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]
2026-08-27 Slim build: slot the plate's rim over the USB notch, 2 mm around the controller
    With the controller window run to the wall line, the plate's rim still bridged the USB notch right above the receptacle, so the port was hidden under it and a plug's overmold (taller than the notch) could not reach it. Cut the rim over the notch, the same 12 mm as the wall (usb_plate_slot, default on for the PCB build), so the port is open from above the case edge. The window's clearance on the other sides goes from 1.5 to 2 mm: a printed window comes out a few tenths under size and the last one was a bend-to-fit. Both slim variants' plates rebuilt.
    Claude-S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
    [keyboard.scad, plate_left.3mf, plate_left.step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]
2026-08-27 Slim build: screw channels up the wall over the insert holes, 3 mm wall, three pillars pulled in
    The pillars stop at the board while the wall keeps rising 5 mm past them, so the seven insert
    holes on the wall line were tucked 1.2 mm under it: a half-moon from above, no way in for an
    insert, and the screws would have sat 0.5 mm into the wall. Now a 4 mm channel (pcb_screw_channel)
    runs up the inside of the wall over each hole, the slim case's wall is 3 mm (pcb_wall) so 1.5 mm
    is left behind it, and the three pillars with room (thumb end, the bay's bottom corner, the one by
    the thumb keys already was) stand 2.5-3 mm clear of the wall as full round bosses. Both boards
    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
    [case_left.3mf, case_left.step, case_right.3mf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]
2026-08-28 Slim build: cut the plate's rim across the whole controller window at the USB end
    The 12 mm slot over the USB notch left two stubs of rim over the board's corners, 5 x 3 mm each. On paper they clear the board's end by 1 mm; in a print they scrape it -- the board can sit 0.5 mm clo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
    Claude-Session: https://claude.ai/code/session_0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
    [keyboard.scad, plate_left.3mf, plate_left.step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]
2026-08-29 Wiring guide: the nice!nano with its pins, each chain's wire to its pin, the wall and bosses
    tools/wiring_guide.py now draws the inner wall (from part="cavity_2d") and the wall bosses, the
    nano in the bay with all 24 pads named -- the matrix pins read from the shield's row-gpios and
    col-gpios, the reset/power/battery pins from the README -- and one thin wire from every row and
    column chain to its pin: rows leave the inner column into nested lanes beside the nano, columns
    leave the thumbs' block-facing COL pads, enter the bay beside the inner column's bottom corner and
    climb the far side. The router runs on a 0.5 mm grid with the wall and bosses as obstacles, never
    cuts a corner, and every w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
    [keyboard.scad]
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2026-09-08 Carry case: two trays that shut on each other keycaps-in, rabbet, corner magnets, cable pocket, finger well
    part = "carry_tray": each half lies keys-up in a tray whose pocket follows its outline, and the right
    tray flips over onto the left like a book shutting, so there is no lid. The outer half of the left
    rim steps up and the inner half of the right, four 6 x 3 mm disc magnets sit where this outline
    leaves solid rim, the corner under the pinky column is a cable pocket and a well above it lets the
    half be pinched out. outline_ext works the extents out the way cavity_2d builds the outline (checked
    against the rendered outline on nine configurations); carry_clash is empty when the magnets hav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
    [carry_tray_left.3mf, carry_tray_right.3mf, keyboard.scad]
2026-09-08 Carry case: rounded rectangle as one offset face so FreeCAD fuses it, and the trays' STEP
    A union of squares and circles comes through FreeCAD's CSG importer as a compound of split faces
    whose extrusions never fuse, leaving the tray's body empty and no STEP; one offset of one square is
    a single face. The 2000 mAh no-display trays now have their STEP (volumes match the meshes).
    [carry_tray_left.3mf, carry_tray_left.step, carry_tray_right.3mf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]
2026-09-13 PCB: controller on top of the board, reset legs paired the right way, jumpers clear of the boss
    Three things the first batch of boards taught us:
    - The nano sits on the face opposite the sockets (on top, flush in the plate window --
    what the case is built around), which swaps its pin rows relative to what the generator
    assumed. Per-half pin tables, the printed ZMK lists (right half columns inner-first) and
    the L/R silkscreen faces are now computed for that; MCU power nets renamed so the L pads
    serve the left half.
    - A 12 mm tactile links its two legs 12.5 mm apart internally; the footprint had the 5 mm
    pairs on one net, so a normally fitted switch held RST at GND and the nano neve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
    [pacino_flat.kicad_pcb, pacino_pod.kicad_pcb]
2026-09-14 Case: 0.6 mm counterbore at the mouth of every insert hole
    Heat-set inserts push a ring of plastic up around them; standing proud of the boss face it
    kept the plate (hand-wired build) and the board (PCB build) from seating without trimming.
    The hole now opens into a 4.2 x 0.6 mm relief -- press the insert down to its bottom and
    the flash stays in the ring (boss_relief_d / boss_relief_h, 0 to disable). Applies to the
    insert_test coupon as well. All variants rebuilt.
    Claude-Session: https://claude.ai/code/session_01BAXTGjnxuhw6nNKSjTcvZb
    [bezel_left.3mf, bezel_left.step, bezel_right.3mf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]
2026-09-14 Remove the carry case
    The two-tray carry case is dropped: its parameters, derived values and modules from
    keyboard.scad, the CARRY option and fit check from build.sh and build_variants.sh, its README
    section and hardware line, and the committed tray files.
    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
    [carry_tray_left.3mf, carry_tray_left.step, carry_tray_right.3mf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]
2026-09-15 MagSafe ring: locating groove on the underside instead of a recess
    The ring's adhesive holds on the bed-side first layer of a PETG print but
    not on the support-interface surface at the bottom of the 1 mm pocket, so
    the ring now sticks straight onto the underside inside a one-layer, 0.6 mm
    wide locating groove just outside its edge (magsafe_style = "groove").
    The recess stays as magsafe_style = "recess", with a note that the ring has
    to be glued in there. The well warning uses the effective depth, so the
    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
    [case_left.3mf, case_left.step, case_right.3mf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]
2026-09-15 M3 hardware option: screw_size sets every insert, screw and board hole size
    screw_size = "M2" (default, unchanged output) or "M3": 4.0 mm insert holes
    with a 5 mm counterbore, 3.4 mm plate holes, and in the pcb build a 6 mm
    spacer boss, 4.6 mm wall channel, 3.6 mm wall and 3.4 mm board holes.
    m2_holes keeps chosen holes at M2 for an existing M2 board with a track
    too close to drill out (the pcb builds' top-edge hole). README: the M3
    hardware, and how to open up an existing board's holes and notches.
    [keyboard.scad]
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2026-09-16 Embedded MagSafe ring: pocket exactly the ring's height, ceiling laid on the steel
    The first test print bridged the 0.2 mm of air over the ring; a layer's
    lines all run one way, so the ones along the annulus spanned 30 mm chords
    and sagged. The pocket is now ring_t + magsafe_pocket_air (0), the pause
    moves to z = 1.0, and the model notes when the pocket's top misses a 0.2 mm
    layer boundary.
    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
    [keyboard.scad]
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
